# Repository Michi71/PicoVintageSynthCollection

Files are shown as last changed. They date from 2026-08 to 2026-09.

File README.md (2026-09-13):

# PicoVintageSynthCollection

Ten vintage synthesizer emulations for the RP2350, built from one shared
codebase. Same board, same core, one firmware image per instrument.

<p align="center">
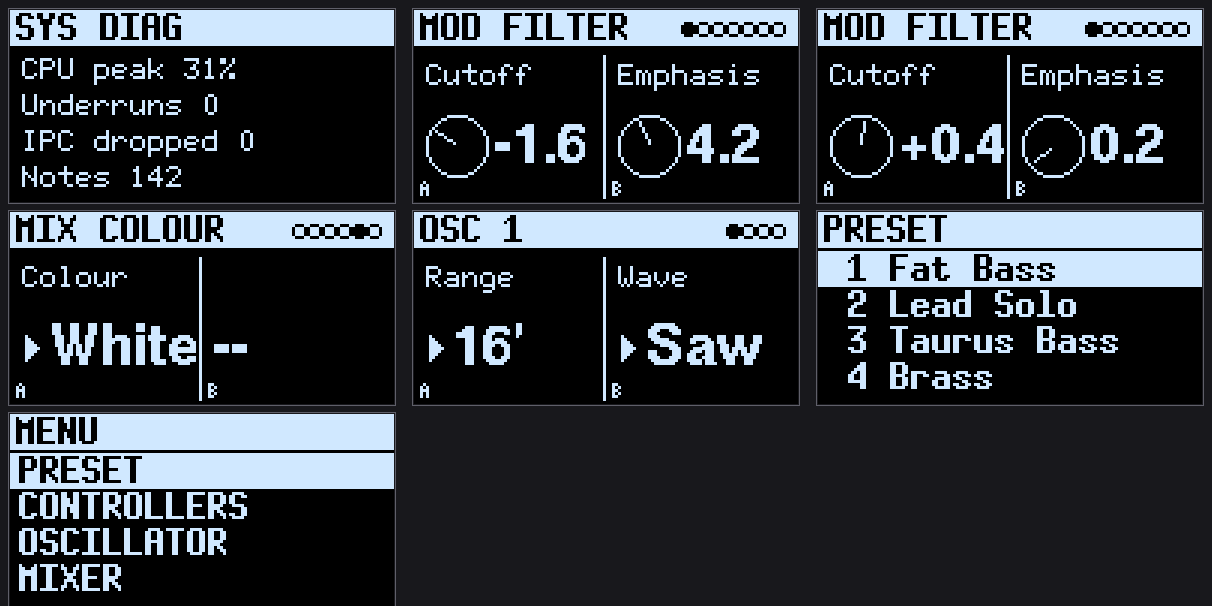
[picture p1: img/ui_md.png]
PicoFaceMD front panel: diagnostics page, filter page, preset list, section menu
  
  <br>
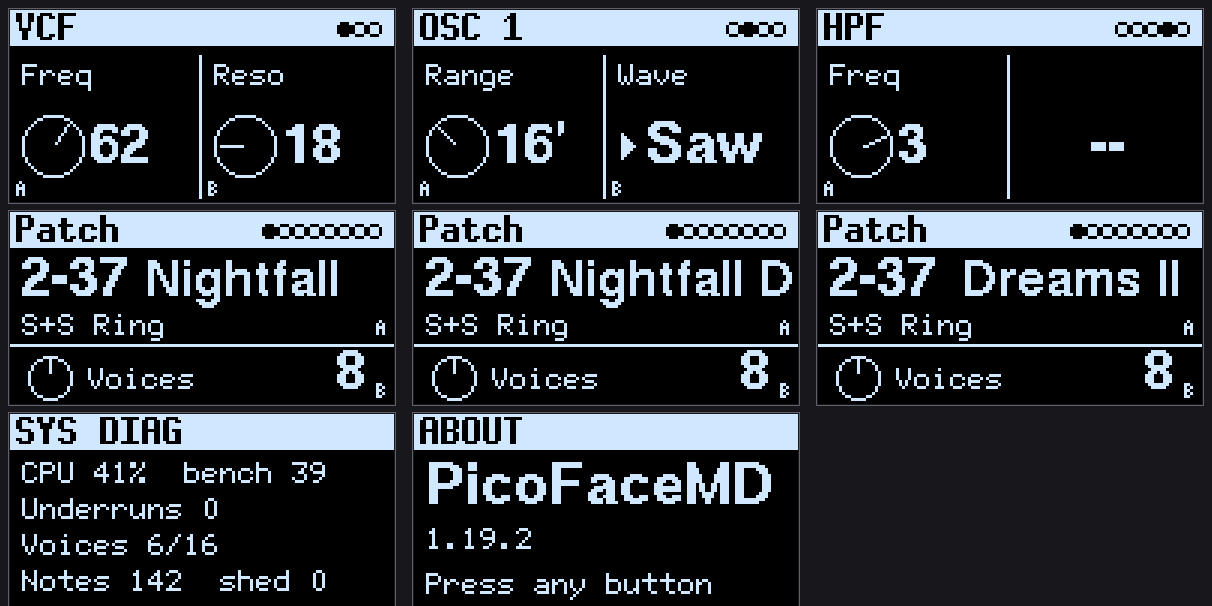
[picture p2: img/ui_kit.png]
The shared front panel: about, diagnostics, two-value pages, menus, patch page, popup
  
  <br>
  <sub>Rendered on a host from the firmware's own drawing code
  (<a href="tools/host_tests/ui/README.md">tools/host_tests/ui</a>) &mdash; what the OLED shows, pixel for pixel.</sub>
</p>

## Demo

<p align="center">
  <a href="https://youtu.be/cG6gyhaqCxE">
    PicoVintageSynthCollection demo video
  </a>
  <br>
  <a href="https://youtu.be/cG6gyhaqCxE">&#9654; Demo video on YouTube</a>
</p>

## Instruments

| Folder | Instrument | Binary |
|---|---|---|
| [instruments/PicoFaceYC](instruments/PicoFaceYC/README.md) | Yamaha reface YC (drawbar organ) | PicoFaceYC.uf2 |
| [instruments/PicoFaceCP](instruments/PicoFaceCP/README.md) | Yamaha reface CP (electric piano, mdaEPiano) | PicoFaceCP.uf2 |
| [instruments/PicoFaceDX](instruments/PicoFaceDX/README.md) | Yamaha reface DX (4-operator FM) | PicoFaceDX.uf2 |
| [instruments/PicoFaceJ6](instruments/PicoFaceJ6/README.md) | Roland Juno-6 | PicoFaceJ6.uf2 |
| [instruments/PicoFaceMD](instruments/PicoFaceMD/README.md) | Minimoog Model D | PicoFaceMD.uf2 |
| [instruments/PicoFaceSM](instruments/PicoFaceSM/README.md) | ARP/Eminent Solina String Ensemble | PicoFaceSM.uf2 |
| [instruments/PicoFaceOB](instruments/PicoFaceOB/README.md) | Oberheim OB-X (engine ported from OB-Xf) | PicoFaceOB.uf2 |
| [instruments/PicoFaceRD](instruments/PicoFaceRD/README.md) | Roland RD / MKS-20 (sample piano) | local build only |
| [instruments/PicoFaceJV](instruments/PicoFaceJV/README.md) | Roland JV-880 (native engine over the original PCM data) | local build only |
| [instruments/PicoFaceD5](instruments/PicoFaceD5/README.md) | Roland D-50 (native LA engine over the original PCM data) | local build only |

The RD, the JV-880 and the D-50 are the exceptions to "download and flash":
they only build where the respective ROM set is present, and those ROMs are not
distributable, so none of the three is in the release binaries. Without them
the configure step skips them and the seven above are unaffected. All three run
on the hardware; see the flash note below for the one build option the JV-880
needs on a small board.

## Hardware

- RP2350; the reference board carries 16 MB of flash, 4 MB is enough for every
  instrument but the JV-880 (see [How much flash an instrument needs](#how-much-flash-an-instrument-needs)).
  **The board must feed the core from the RP2350's own regulator** -- see
  *The board has to take the overclock* below before buying anything cheap.
- I2S audio (PCM5102 DAC)
- 128x64 OLED over I2C (SH1106)
- Three rotary encoders with push buttons
- USB MIDI and DIN MIDI

The pin map is the same for every instrument and lives in
[core/include/project_config.h](core/include/project_config.h).

**Which RP2350 board.** The default build assumes a Pico-2-format board with an
RP2350**A** -- Pico 2, Waveshare RP2350-Plus and the like -- where I2S sits on
GP26/27/28 at header pins 31/32/34. The Waveshare **RP2350B-Plus-W** has the
same header but carries **GP40/41/42** at those three positions (the RP2350B's
ADC0-2 take the Pico's ADC spots; GP26-28 are only on the pads underneath), so
a default image on it drives the I2S lines into thin air: display, MIDI and
encoders work, only the sound is missing, and every counter reads healthy. It
is a build-time choice, not a wiring one -- see *Building* for
`-DPICOFACE_BOARD=rp2350b_plus_w`.

**The board has to take the overclock.** These engines are budgeted for a
core clock of **444 MHz** (480 for the RD) at a core voltage of **1.60 V**:
three times the RP2350's rated 150 MHz, and a voltage above what the SDK
allows without an explicit override. That is not a tuning option, it is the
design point -- below it the instruments do not finish their audio blocks.
The firmware sets that voltage through the chip's on-board regulator, so the
board has to route the core supply (`DVDD`) through that regulator, the way
the Pico 2 reference design does. **Known good:** Raspberry Pi Pico 2,
Waveshare RP2350-Plus, Waveshare RP2350B-Plus-W (with its build variant).
**Known bad:** unbranded 16 MB "RP2350" boards from marketplace sellers. One
was bought to settle issue #107: its chip and flash are fine, but the
regulator register has no effect on its core voltage, so the core stays at the
board's fixed supply and stops dead at 312 MHz. No build option, flash timing
or stepping has anything to do with it, and no firmware can get 444 MHz from
such a board. The symptom is either nothing on the screen with the release
image, or "boots at 300 MHz, no sound" with a downclocked build. If a board
does neither of the things above, the working image is the diagnosis: build
`PicoFaceMD` with `-DPICOFACE_BOOT_DIAG=ON` and read the last line on the
screen; the whole investigation, with the images that separate flash, core
and voltage, is in the MD README under
[The board that stops at 300 MHz](instruments/PicoFaceMD/README.md#the-board-that-stops-at-300-mhz-a-core-voltage-the-register-cannot-reach).
Please check that section before opening an issue about a board that will
not start: a chip marked `A4` is not the reason either (the splash shows the
bootrom revision as `b4` now, and it changes nothing).

**If the screen stays dark.** The panel is on I2C at 1 MHz with only the chip's
internal pull-ups. That is above what an SH1106 datasheet promises (400 kHz) and
it is what the reference board runs, because the display push is paced in half
tile rows of roughly 1.5 ms of I2C each -- the bus rate is directly the UI's
frame time, and 400 kHz would make a full screen 60 ms instead of 24. On longer
jumper leads it is the first thing to suspect. Build with
`-DPICOFACE_OLED_I2C_HZ=400000`, and consider real 2.2k-4.7k pull-ups before
blaming the display.

A display that is simply absent costs nothing: the I2C write returns an error on
a NACK and the firmware carries on. A display that *holds a line low* used to
take the whole instrument down -- the wait for the bus is unbounded, and the
first transfer happens before the splash loop, which is the only place USB gets
serviced during startup, so the board would not even enumerate. It reads exactly
like a firmware that does not boot. That write is now bounded at 5 ms and the
panel is written off after twenty consecutive failures, so a broken display
costs you the display and not the MIDI, the audio and the encoders.

**On the board setting.** The build defaults to `PICO_BOARD=sparkfun_promicro_rp2350`,
and that is a statement about flash size rather than about hardware: the
prototype runs a Waveshare RP2350-Plus, and the SparkFun definition was picked
because it declares 16 MB where the plain `pico2` definition declares 4. Any
RP2350 board with 16 MB works if the pins above are reachable on it. For a
Pico-format board the honest pair is

```bash
cmake -S . -B build -G Ninja -DCMAKE_BUILD_TYPE=Release -DPICO_BOARD=pico2 -DPICO_FLASH_SIZE_BYTES=16777216
```

Without that second flag, `pico2` caps the image at 4 MB. The CP's sample
sets were cut for exactly that size, so every instrument but the JV fits
within it (the CP at 3.99 MB, with 190 KB to spare); the flag is for the JV,
and for a board that really has 16 MB. Nothing else in the SparkFun definition
reaches the firmware: the flash timing and the system clock are set by the project itself in
[core/src/pico_hw.cpp](core/src/pico_hw.cpp), and `PICO_FLASH_SPI_CLKDIV` is
identical in both. The one thing it declares that the prototype does not have is
an 8 MB PSRAM region on GPIO 19 — nothing is placed there, so it costs nothing,
but PSRAM is not a thing to reach for on this hardware without checking the
board first.

### Switching instruments

One board, ten firmware images, so choosing a different instrument is something
you do rather than something a factory does once. **Hold all three encoder
buttons together.** After half a second the display takes over and counts down
from two; let go and nothing happens. Hold it out and the board silences itself,
drains the audio it had already queued, and reappears as the `RPI-RP2` drive —
drop the next `.uf2` on it.

No button combination in any instrument uses all three at once, so it cannot
happen by accident, and the BOOTSEL button on the module is never needed for
this. Keep that button reachable anyway: if a firmware is too broken to reach
its own user interface, BOOTSEL plus a power cycle is the way back.

### How much flash an instrument needs

The reference board carries 16 MB. That is not a requirement of the design:
three instruments ship sample data, and only one of them needs a build option
to fit the 4 MB that a base Raspberry Pi Pico 2 and many other RP2350 boards
provide:

| Instrument | Image | On a 4 MB board |
|---|---|---|
| YC, DX, J6, MD, SM, OB | 90-190 KB | fits anywhere |
| PicoFaceCP | 3.99 MB | fits, 190 KB to spare |
| PicoFaceJV | 4.34 MB | only with `-DPICOFACEJV_4MB=ON` (3.76 MB, banks A+B) |
| PicoFaceD5 | 0.86 MB | fits |
| PicoFaceRD | 2.56 MB | fits |

The JV's reduced variant drops something real: the user bank, and the 22
samples only those patches used. Banks A and B are otherwise untouched --
nothing is resampled or requantised.

**The RD used to need one too, and no longer does.** Its packs held four
sampled velocity layers of every note; they hold the parameter ROM's own
corners now and the engine interpolates, which is both exact at all 128
velocities and a fifth the size. The whole instrument went from 5.15 MB to
2.56 MB. `-DPICOFACERD_MODEL=MKS20` or `=MK80` still builds one machine on its
own -- eight patches, and half a ROM set is enough for it -- but nobody needs
it to fit a board any more.

**The CP has no reduced variant either, and needs none.** It used to be
4.22 MB and carried its five built sample sets as one indivisible whole, with
no subset to drop; the sets were then cut for a 4 MB flash without dropping
anything: every sample keeps its attack byte for byte and loops 40-100 ms
earlier, at a loop cycle chosen to stay within 1 dB and 10 % spectral centroid
of the cycle it looped before. The rule and the numbers are in
[tools/cp_sampleprep](tools/cp_sampleprep/README.md#fitting-a-4-mb-flash).
Anything from 8 MB up holds any of the ten instruments. The D-50 is the one
sample-based instrument that never needed cutting -- its whole sample ROM is
512 KB.

An oversized `.uf2` fails to copy in a way that names no reason: the file
transfer stops or the drive rejects it, with nothing on screen about flash size.
That is the symptom, and it is not a corrupt download.

## Building

```bash
git clone --recurse-submodules https://github.com/Michi71/PicoVintageSynthCollection.git
cd PicoVintageSynthCollection
cmake -S . -B build -G Ninja -DCMAKE_BUILD_TYPE=Release
cmake --build build
```

The artifacts are then in `build/<instrument>.uf2`.

**Board variant.** `-DPICOFACE_BOARD=pico` (the default) builds for any
Pico-2-format RP2350A board. `-DPICOFACE_BOARD=rp2350b_plus_w` builds for the
Waveshare RP2350B-Plus-W: it selects an RP2350B board profile (48 GPIOs, 16 MB),
puts I2S on GP40/41/42, and re-bases PIO0 to GPIO 16-47 before the I2S program
is loaded, because an RP2350 PIO addresses either GPIO 0-31 or 16-47. The firmware
also puts such a board's flash into quad by itself when the bootrom left it in
dual -- the Puya P25Q128H on the reference board ships with its quad-enable bit
clear, and the bootrom never sets one -- and then tops the flash timing ladder
one rung lower (111 MHz instead of 148; RD 96 instead of 120): that part
verifies 111 MHz in quad and hangs at 148, and a rung that hangs cannot be
stepped down from. See the PicoFaceMD README, *The bit the bootrom never sets*. A board
with a faster flash can ask for the full rung with
`-DPICOFACE_QMI_M0_TIMING_TARGET=PICOFACE_QMI_M0_TIMING_RX4`. The released UF2s
are the default variant; the RP2350B build is one cmake flag away and produces
the same ten images.

```bash
cmake -S . -B build-b -G Ninja -DCMAKE_BUILD_TYPE=Release -DPICOFACE_BOARD=rp2350b_plus_w
cmake --build build-b
```

**The splash screen names the build.** Every instrument shows a version taken
from `git describe`, not a number typed into its `instrument.cmake`: on a
release tag it is the release (`1.7.0`), anywhere else it says how far past that
tag and from which commit (`1.7.0-4-ga39504b`), and a trailing `+` means the
tree had uncommitted changes when it was built. The About page shows the same
string. Quote it in a bug report and the image is identified exactly; the
version used to read `0.1` in every build ever made, which identified nothing.

A tarball without `.git` builds fine and shows `unknown`.

### The three that need ROMs

`PicoFaceRD`, `PicoFaceJV` and `PicoFaceD5` play the original machines' own
data, which is not distributable. Each looks in its own `roms/` directory —
`instruments/<name>/roms/`, gitignored — and removes itself from the build with
a note if what it needs is not there. Nothing else is affected.

| | what goes in `roms/` | |
|---|---|---|
| **PicoFaceD5** | two PCM ROMs and a program EPROM | identified by CRC32, so **names do not matter** |
| | | plus optional `*.syx` bulk dumps for the patch banks |
| **PicoFaceJV** | `jv880_rom2.bin`, `jv880_waverom1.bin`, `jv880_waverom2.bin` | exact names, 256 KB + 2 MB + 2 MB |
| **PicoFaceRD** | `mks20_15179736.BIN` … `41.BIN`, `MK80_IC5.bin`, `MK80_IC6.bin`, `MK80_IC7.bin` | exact names, 128 KB each |
| | `pack_p0.rdp` … `pack_p15.rdp` | **built, not found** — see below |

**The RD needs one thing nobody else does.** Its sixteen `.rdp` packs are note
descriptors derived from those ROMs, and they have to be made once:

```bash
R=instruments/PicoFaceRD/roms
python3 tools/rd_extract/rd_descramble.py $R \
    RD200_B.bin mks20_15179757.BIN /tmp/prog.bin /tmp/prm.bin
python3 tools/rd_extract/rd_make_packs.py /tmp/prog.bin /tmp/prm.bin $R \
    0 0x000000 1 0x008000 …
```

Python and the ROMs, nothing else -- no emulator, no toolchain beyond the one
already building the firmware.

**To check that all of this actually works from scratch**, `tools/check_clean_build.sh`
clones into a temporary directory, copies the ROMs in from outside git, and
builds all ten. That last part is the point: the ROM sets are not in this
repository and must never be, so a build here is the one thing CI cannot cover.
Name a directory to build there instead and keep the result; add `--variants`
for the reduced images too.

RD also builds as a single machine — `-DPICOFACERD_MODEL=MKS20` (1.73 MB) or
`=MK80` (1.23 MB), eight patches each, and only that machine's ROMs are needed.
The default is both machines and 2.56 MB, which fits a 4 MB board. See
[`instruments/PicoFaceRD/README.md`](instruments/PicoFaceRD/README.md) for the
whole recipe and all sixteen patch offsets.

Building a single instrument:

```bash
cmake -S . -B build -G Ninja -DCMAKE_BUILD_TYPE=Release -DPICOFACE_INSTRUMENTS_FILTER=PicoFaceMD
cmake --build build
```

### If the very first cmake call dies with an architecture error

On macOS a mixed package manager prefix produces this, and it reads like a
problem with the project:

```
dyld: Library not loaded: /opt/local/lib/libarchive.13.dylib
  Referenced from: /opt/local/bin/cmake
  Reason: (mach-o file, but is an incompatible architecture (have 'arm64', need 'x86_64'))
Abort trap: 6
```

It is not. The complaint comes from `dyld` about loading `cmake` itself, before
any of this repository is read, and "need 'x86_64'" means the `cmake` binary is
an Intel build sitting next to Apple Silicon libraries — a MacPorts or Homebrew
prefix that was installed under Rosetta, or carried over from an Intel Mac
without the migration. Check with:

```bash
uname -m                 # arm64 on Apple Silicon
file $(which cmake)      # must say the same
```

If they disagree, reinstall the toolchain for the machine's own architecture
(MacPorts documents a migration procedure for exactly this). Apple Silicon
itself is fine: the collection is developed on it.

## Repository layout

```text
core/            shared runtime: audio pipeline, hardware, USB/DIN MIDI, GUI, persistence
cmake/           picoface_add_instrument() and the SDK import helpers
lib/             third-party static libraries (audio, encoder, u8g2) and the SDK submodules
instruments/     one folder per instrument: instrument.cmake, src/, include/, doc/, README.md
tools/           host-side tools; not part of any firmware image
docs/            documentation shared by all instruments
hardware/        the module as a board: schematic, two layouts, panel, parts, and
                 what the first built pair taught
img/             the instruments' screens and the panel sheets above, rendered
                 from the firmware by tools/host_tests/ui
```

## Documentation

Shared:

- [Architecture](docs/ARCHITECTURE.md) - how core and instruments fit together, and why
- [Adding an instrument](docs/ADDING_AN_INSTRUMENT.md) - the three steps needed
- [The module bus](docs/MODULE_BUS.md) - the hardware interface several modules in one
  case would share: power, MIDI and audio. Planned, not built
- [Hardware](hardware/README.md) - the module as a 10 HP Eurorack board: schematic,
  the two layouts and the panel, parts, and the first built pair
- [Host tools](tools/README.md)

Per instrument, under `instruments/<name>/doc/`: MIDI implementation charts,
persistence formats, preset tables and the engineering logs of the individual
ports. The per-instrument README links them.

Manufacturer manuals and service documentation are **not** part of this
repository. Where an emulation follows a specific manual or schematic, the
instrument's README names the document so it can be obtained separately.

## Status

**All ten instruments build from a single configure run, each with its own USB
PID, and all ten run on the hardware.** Seven are in the release binaries; the
RD, the JV-880 and the D-50 need a local ROM set and are therefore built locally
only.
Open points are listed in [docs/ARCHITECTURE.md](docs/ARCHITECTURE.md),
section 8.

## License

**GNU General Public License, version 3 or later** - see [LICENSE](LICENSE).
Copyright (C) 2026 Michi71.

The collection was assembled in August 2026 from seven single-instrument
repositories -- YC, CP, DX, RD, J6, MD and SM; OB, JV and D5 were written here
afterwards, which is why the number is seven and not ten. Each of those seven
already shipped the identical GPL-3 licence text, and every instrument README
states GPL-3. It is also the lowest common denominator of what the engines are
built on. Where an instrument derives from someone else's work:

| Part | Upstream it derives from | That upstream's license |
|---|---|---|
| core, cmake, tools | own work | - |
| PicoFaceYC | [OpenB3 / BeatrixCPP](https://github.com/pantherb/setBfree) - tone generation *concepts* only, no code | AGPL-3.0 upstream, does not reach here; see below |
| PicoFaceCP | [mda-EPiano](https://sourceforge.net/projects/mda-vst/) (engine, in tree) | GPL-3.0-or-later |
| PicoFaceDX | an ESP32 reface DX emulation (engine) | see that project |
| PicoFaceRD | [giulioz/rdpiano](https://github.com/giulioz/rdpiano) + MAME (reference emulator; host-side only, not in this repository) | GPL |
| PicoFaceJ6 | [junox](https://github.com/dzannotti/junox) (patch table, parameter scaling) | GPL-3 |
| PicoFaceMD | [BelaMiniMoogEmulation](https://github.com/lbros96/BelaMiniMoogEmulation) (ladder filter) | stated by its author to be under no copyright |
| PicoFaceSM | [string-machine](https://github.com/jpcima/string-machine) (DSP models) | Boost Software License 1.0 |
| PicoFaceOB | [OB-Xf](https://github.com/surge-synthesizer/OB-Xf) (engine) | GPL-3.0-or-later |
| PicoFaceJV | own engine over the machine's own PCM data, measured against [giulioz/jv880_juce](https://github.com/giulioz/jv880_juce) (host-side reference; tone field layout) | non-commercial; not vendored, see below |
| PicoFaceD5 | [munt](https://github.com/munt/munt) - the LA32's wave generation and the Boss reverb topology as that project *documents* them, no code | LGPL-2.1-or-later upstream, does not reach here; see below |

Two rows in that table need a sentence more than a table cell holds.

**PicoFaceRD** used to carry the reference emulator's sources in the tree, and
three decoded ROM sets with them. Neither is here any more. The emulator is a
separate checkout the regression harness is pointed at, and the sample data is
built at configure time from a local ROM set into a blob -- the same arrangement
as the JV and the D5, and for the same reason. What the device plays is
`RdNewEngine` over descriptors that emulator captured offline.

**PicoFaceJV** contains none of that emulator's code, and cannot: its licence
forbids commercial use and fits neither MIT nor GPL-3. It was used as a host-side
measuring instrument — the harness in `tools/jv_extract/` drives it to take the
readings the engine was calibrated against, and the patch and tone field layout
comes from its `dataStructures.h`. The engine itself is written from the ROM
formats. `tools/jv_extract/README.md` records the reasoning; the work is Giulio
Zausa's, and his emulator in turn derives from [NukeYKT's
Nuked-SC55](https://github.com/nukeykt/Nuked-SC55).

`instruments/PicoFaceOB/` additionally carries its own `LICENSE`, identical in
text, because that instrument's engine is a direct port of OB-Xf and its files
keep the upstream copyright headers. Every instrument builds into its own
binary, so a stricter licence on one of them stays confined to that binary.

Source files carry a two-line SPDX header rather than the full notice, to keep
it out of the way of the code. Three kinds exist:

- own work: `GPL-3.0-or-later` plus the copyright line;
- ported trees (`instruments/PicoFaceDX/include/dx_engine/`): the licence line
  plus a note that copyright is shared with the upstream authors - no sole
  claim is made there;
- upstream files (`instruments/PicoFaceOB/include/obxf/`, CP's `mdaEPiano.*`,
  the SDK-derived `usb_descriptors.c`,
  `get_serial.*` and `tusb_config.h`): untouched, they keep the header they
  came with. The last four are MIT and BSD-3-Clause, not GPL.

**On PicoFaceD5 and munt.** The D-50 and the MT-32 share the LA32 sound chip,
and the MT-32 emulator [munt](https://github.com/munt/munt) has read that chip
out and written down what it does: how a cutoff becomes the width of a cosine
edge, how the resonance decays, and - from the same era's Boss reverb chip,
whose data lines were traced by Lord_Nightmare, balrog and Mok - the topology
the reverb here follows. munt is LGPL-2.1-or-later. Nothing was copied: the
engine under `instruments/PicoFaceD5/include/d5_engine/` was written for this
project from that written description and from the D-50's own firmware, which
is why no file there carries an upstream copyright header. The description is
what mattered, and a description is not the program.

**On PicoFaceYC and the AGPL.** OpenB3 / BeatrixCPP, whose tone generation
concepts the YC drawbar engine follows, is AGPL-3.0 - stricter than GPL-3, and
not something that can be dropped by relicensing. It does not apply here: the
engine under `instruments/PicoFaceYC/include/yc_engine/` was written for this
project and contains no upstream code, which is why no file there carries an
upstream copyright header. Copyright covers the expression, not the concepts,
so GPL-3 is the right licence for it.

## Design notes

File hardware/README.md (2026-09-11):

# Hardware

The module this firmware has been running on, turned into something
reproducible: the dimensions and decisions the board was drawn to, worked out
against the parts actually in hand and written down before the layout rather
than after. The first pair of boards has been fabricated, assembled and is
running the firmware since September 2026 - it is the reference hardware now,
see [The first built pair](#the-first-built-pair) for what powering it up
taught.

The schematic is drawn: the KiCad 10 project in
[PicoVintageSynthCollection/](PicoVintageSynthCollection/) (root sheet plus
`main_board`, `front_board`, `panel`; ERC clean), with a PDF export next to it
([PicoFace-schematic.pdf](PicoVintageSynthCollection/PicoFace-schematic.pdf)).

**Both boards are laid out**: [MainBoard/](MainBoard/) and
[FrontBoard/](FrontBoard/), routed, DRC clean; and the panel is a board in its
own right in [Panel/](Panel/). Both boards have been made from these files.

The interface *between* several modules — power, MIDI, audio — is a separate
document: [The module bus](../docs/MODULE_BUS.md).

## Format

3U Eurorack, 10 HP. The panel is 50.8 x 128.5 mm and 1.6 mm thick, which is
mechanical rather than cosmetic: the EC11 encoders have a 5 mm threaded bushing,
and 1.6 mm of panel leaves 3.4 mm for the nut. A 2 mm panel leaves 3.0 mm, which
works but has no margin.

**Cut it to 50.4 mm, not 50.8.** 10 HP is 10 x 5.08 mm, and that nominal figure
is the space the module occupies in the rack, not the width of the metal. A panel
made to it has no room for the tolerances of its own edge, of its neighbours, or
of the rails, and a full row will bind rather than sit flat. Roughly 0.4 mm under
is the usual allowance. The height is not affected: 128.5 mm is already the
Eurorack panel height, 3U less the clearance the rails need.

The layout is [Panel/panel_10hp.svg](Panel/panel_10hp.svg) (CorelDRAW source
next to it), measured against the real parts: the display on top, the SELECT
encoder between the RUN and BOOT buttons, PARAM A and B in a second row, the
four jacks along the bottom below the board. 14 HP was the plan as long as the
three encoders had to share one row; with SELECT in its own row and the jacks
off the board, 10 HP closes.

## The governing dimension

**The board sits 6.5 mm behind the panel.** That is the EC11's body height and
nothing else negotiates with it — every other panel-facing part has to reach the
same plane:

- the **display** module is 2.8 mm thick, so it rides on 3.5 mm standoffs
- the **jacks** could not reach it at all, which is why they are panel-mounted
  and wired (see below)

## Drill and cutout list

Origin top left, X right, Y down, panel 50.8 x 128.5 mm. Numbers read off
`panel_10hp.svg` (1 unit = 0.01 mm there); the SVG carries a 50 mm calibration
bar.

| Element | X | Y | Machining |
|---|---|---|---|
| Mounting M3 | 7.5 / 43.3 | 3.0 | 3.2 dia |
| Mounting M3 | 7.5 / 43.3 | 125.5 | 3.2 dia |
| Display window | 25.4 | 30.0 | 30 x 16 (X 10.4–40.4, Y 22–38) |
| Encoder SEL | 25.4 | 60.58 | 7.0 dia, 15 mm knob |
| RUN | 10.0 | 60.58 | 4.0 dia for the 6x6 tact switch actuator |
| BOOT | 40.8 | 60.58 | 4.0 dia for the 6x6 tact switch actuator |
| Encoder A | 12.9 | 85.61 | 7.0 dia, 15 mm knob |
| Encoder B | 37.9 | 85.61 | 7.0 dia, 15 mm knob |
| MIDI in | 8.15 | 109.6 | 8.2 dia (M8 thread), 10 mm body |
| MIDI out | 19.65 | 109.6 | 8.2 dia (M8 thread), 10 mm body |
| Out L | 31.15 | 109.6 | 8.2 dia (M8 thread), 10 mm body |
| Out R | 42.65 | 109.6 | 8.2 dia (M8 thread), 10 mm body |

No USB cutout: the 10 HP panel has no room for a USB lead, so USB stays at
the module's own socket.

The display module is **35.4 x 33.5 mm** with its four M2 holes **30.4 x 28.5**
apart, set 2.5 mm in from its top-left corner — all four numbers off the part
itself. Centred on the board it sits at X 7.7–43.1, Y 15.0–48.5, which puts the
holes at X 10.2 / 40.6 and Y 17.5 / 46.0. The two boards, 45 x 80 mm each, sit
at X 2.9–47.9, Y 14.0–94.0 behind it; the jack row is below the boards.

**The display's pin order is not the common one.** Measured on the part in hand:
**1 VDD, 2 GND, 3 SCK, 4 SDA**, numbered from the display side with pin 1 on the
left. The order most modules use — GND, VCC, SCL, SDA — would have put 3.3 V on
this module's ground pin and killed it on first power-up. The header is centred
on the module's top edge, which is where DS1 sits.

**The window is cut to the pixels, not to the glass.** On the 1.3 inch module the
active area starts 7.35 mm below the module's top edge and is 14.7 mm tall, so
its centre lands 14.7 mm below that edge — the glass around it is 19 mm tall and
sits differently. Cutting to the glass would leave an uneven border.

Clearances, so the numbers can be checked rather than trusted: the display
glass ends at Y 48.5 and the SELECT knob begins at 53.1; the 15 mm knob leaves
4.9 mm to each 6 mm button; the PARAM knobs (78.1–93.1) end 0.9 mm above the
board edge at Y 94 and stand 10 mm apart; the jack bodies (10 mm) sit 1.5 mm
apart at 11.5 mm pitch — fine for round nuts, an 11 mm hex nut is marginal.

## The panel as a board

The drawing is not a manufacturable file. `panel_10hp.svg` says where the holes
go and can be read by a person or a laser cutter; a board house needs the
outline on a copper-stackup layer and every opening as a closed contour. So the
panel is drawn a second time, as [Panel/Panel.kicad_pcb](Panel/Panel.kicad_pcb)
— a two-layer board 1.6 mm thick with **no copper on it at all**, which is the
usual way to have a fab cut a front panel: same process, same price bracket, and
the silkscreen comes with it instead of needing a separate print.

**The coordinates are the table above shifted 0.2 mm left.** The table is drawn
on the 50.8 mm nominal; cutting to 50.4 takes 0.2 mm off each edge, and
everything has to follow or the pattern sits off-centre. It stays symmetric
after the shift, which is the check: SELECT lands on 25.2, exactly half of 50.4,
and each pair still mirrors (mounting 7.3 / 43.1, buttons 9.8 / 40.6, PARAM 12.7
/ 37.7, jacks 7.95 / 42.45). The mounting holes end up ±17.9 mm from the panel
centre, which is where the rail thread expects them.

**What is drilled and what is routed** is decided by one number: 6.3 mm, the
largest drill most fabs keep.

| Opening | Layer | Why |
|---|---|---|
| outline 50.4 x 128.5 | `Edge.Cuts` | |
| display window 30 x 16 | `Edge.Cuts` | rectangular |
| 3 x encoder 7.0 dia | `Edge.Cuts` | over 6.3 |
| 4 x jack 8.2 dia | `Edge.Cuts` | over 6.3 |
| 4 x mounting 3.2 dia | NPTH | |
| 2 x button 4.0 dia | NPTH | |

Routed circles are cut with an end mill and come out a little rougher than a
drilled hole, which is of no consequence behind a nut. The display window's
inside corners will carry the mill's radius, about 1 mm — that is normal and the
module's bezel covers it.

**Every label sits above what it names**, including the jack row. That is not
symmetry for its own sake: a patch cable hangs down out of a Eurorack jack and
covers whatever is printed below it, so the first drawing — labels under the
jacks, in the space that looked free — would have been legible only on an
unpatched module. Checked rather than eyeballed: no silkscreen stroke falls
within 0.3 mm of any opening or the board edge, and none of it disappears under
a 15 mm knob or an 11 mm jack nut.

**The top side is the front.** Decided, and the board file is drawn to it: the
legend sits on `F.SilkS` unmirrored, so the side the fab prints as top is the
side that faces the player. Say it in the order anyway — a panel has no
components to make the intent obvious, and a fab that guesses has a fifty-fifty
chance of printing the legend on the inside. White on black is the usual choice.

DRC reports six warnings and nothing else: the six hole footprints are generated
in the board file rather than pulled from a library, so the library-parity check
has nothing to compare them against. Same class of warning the other two boards
carry, and it does not reach the Gerbers.

## Two boards

Both boards are **45 x 80 mm, two layers**.

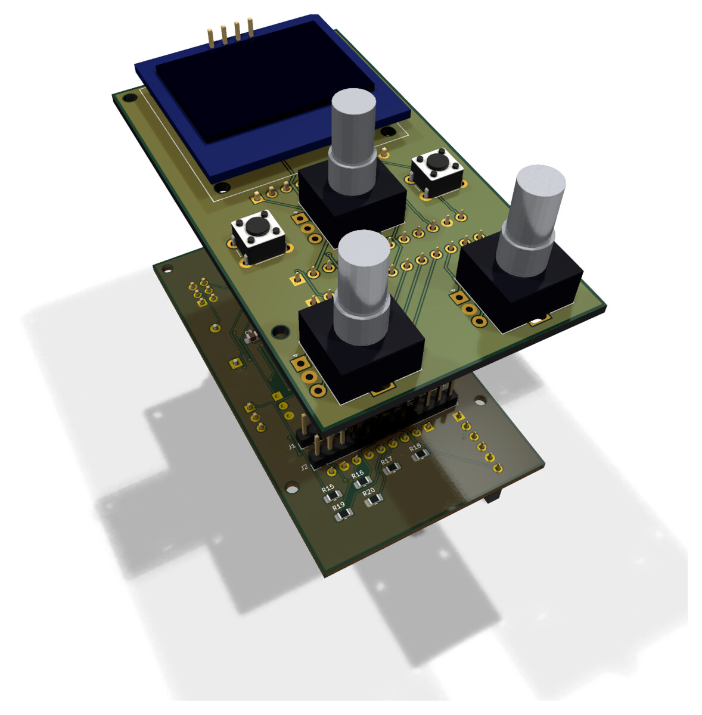
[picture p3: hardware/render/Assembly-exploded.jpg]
The two boards pulled apart, front board above the main board


*Renders under [render/](render/); how they are made and what they settled is in
[3D view](#3d-view) below. The encoders and the display are stand-in models, and
the module is drawn as a Pico.*

**Front board**, 6.5 mm behind the panel, carries everything the format dictates
— and that 6.5 mm is a hard ceiling for anything on its panel side, which is why
the jack wires are soldered into J8 rather than plugged into a header: a 2.54 mm
header stands 8.5 mm tall and would hit the panel. It carries:
three EC11 encoders, the RUN and BOOT tact switches (6x6, four pins; the
actuator has to reach through 6.5 mm of gap plus the 1.6 mm panel, so the 9.5
mm or taller types), the display on standoffs, the encoder pull-ups, and the
header J8 for the panel-wired jacks.

**Main board** behind it carries what does not care about the format: the
module on sockets, the PCM5102, the MIDI circuitry, and the bus connectors.

They join with **two 1x12 headers** (J1/J2 male on the main board, J3/J4
sockets on the front board) — two rather than one because they also hold the
boards parallel. Nineteen signals: I2C 2, encoders 9, MIDI 4, audio 2, RUN,
BOOT; plus 3V3, VSYS and three GND = 24. MIDI is four lines rather than two
because the current loop crosses the headers — the opto-coupler and its
resistors stay on the main board, where the bus MIDI RX joins the same node —
and the two extra grounds are what makes a single 24-way link acceptable for
audio. The plan said "roughly nineteen" and two 10-pin strips; the schematic is
where the count became exact.

The split is the point. A different enclosure means a new front board; the main
board does not change.

## Why the jacks are wired rather than soldered to the board

The available jack has its collar 2.9 mm above the board and its thread ends at
8.9 mm. With a 1.6 mm panel and a 2 mm nut, the panel can sit no further out
than 5.3 mm — and the encoders put it at 6.5 mm. Short by 1.2 mm, with no slack
anywhere to take it out of.

So the jacks mount to the panel and wire back to a 10-pin header (J8). That
removes the constraint instead of working around it: the board stops having an
opinion about which jack fits, which is what makes the three-conductor MIDI
sockets possible at all — those need TRS. The jacks are the M8-thread panel
type (10 mm body, nut, solder lugs), stereo for MIDI, mono or stereo for audio;
with a stereo jack on an audio output the ring is simply left open. On a metal
panel the bushing ties the sleeve to the panel — fine for the three grounded
jacks, and for MIDI IN either an insulating washer or accepting it (the opto
still isolates the loop).

## Parts

Already in hand: Waveshare RP2350-Plus (16 MB), three EC11 with 5 mm bushings, 15 mm
knobs, PCM5102 module.

Still needed:

| Part | Qty | Note |
|---|---|---|
| OLED 1.3" SH1106, I2C, 4-pin | 1 | 35.4 x 33.5 mm |
| 3.5 mm jack, panel mount, M8 thread, 10 mm, solder lugs | 4 | 2× stereo (MIDI), 2× mono or stereo (audio) |
| Tact switch 6x6, 4-pin, actuator ≥ 9.5 mm | 2 | RUN, BOOT — on the front board |
| Header strips 12-pin, male + female | 2 each | board to board (J1/J2, J3/J4) |
| Header strip 10-pin | 1 | panel jacks (J8) |
| Socket strips for the module | 2 | keep the module replaceable |
| Socket strips 1x6 and 1x9 | 1 each | the PCM5102 module, likewise replaceable |
| H11L1 optocoupler (+ DIP-6 socket) | 1 | MIDI in, Schmitt trigger type |
| 220R, 4k7, 1N4148, 100 nF | 1 each | MIDI in (4k7 pull-up on the H11L1, 100 nF bypass) |
| 33R, 0.5 W | 2 | MIDI out at 3.3 V (the source resistor sees a pin-4 short) |
| 1N5817 Schottky | 1 | bus 5 V into VSYS |
| BAT85 Schottky | 1 | bus MIDI RX into the RX node (small signal: low Vf, low leakage) |
| 1k 0805 | 2 | in series with the audio outputs (mispatch and load protection) |
| 100k 0805 | 4 | PCM5102 FLT/DEMP/XSMT/FMT to the module's own rails |
| 100 nF 0805 | 1 | on RUN, at the module pin |
| Shrouded header 2x3 | 1 | bus 1: power and MIDI |
| Header 3-pin | 2 | bus 2: audio; UART0 debug (footprint only) |
| 10k 0805 | 9 | encoder and switch pull-ups |
| 10 nF 0805 | 6 | **buy, leave unpopulated** |
| 100 nF 0805 | 1 | MIDI IN sleeve RF ground, **leave unpopulated** |
| M2 standoff 3.5 mm + screws | 4 | display |
| USB panel socket with lead | 0–1 | optional, and the 10 HP panel has no cutout for it; type follows the module — micro-USB on a Pico 2, USB-C on the Waveshare |

## Checked against the datasheets

- **The boards are drawn for a Raspberry Pi Pico 2**, the module most of the
  instruments in this collection run on. A **Waveshare RP2350-Plus** drops into
  the same sockets when 16 MB of flash is wanted — same 21 x 51 mm outline, same
  40 pins. Which one goes in is a firmware build setting, not a board question;
  see the flash-size note in the [top-level README](../README.md). The one place
  the difference does reach the board is BOOT, below.
- **Everything the board assumes about the module is checked against
  [the Pico 2 datasheet](https://datasheets.raspberrypi.com/pico/pico-2-datasheet.pdf)**,
  not against a footprint that happened to be to hand:

  | | board | datasheet |
  |---|---|---|
  | outline | 21.00 x 51.00 mm | 51 x 21 mm, 1 mm thick |
  | pin pitch | 2.54 mm | 2.54 mm |
  | pin 1 to pin 20 | 48.26 mm | 48.26 mm |
  | row spacing | 17.78 mm | 17.78 mm |
  | pin 1 from the top edge | 1.37 mm | (51 − 48.26)/2 |
  | hole per pin | 1.00 mm | 1 mm |

  Also from the drawing and not used here: four Ø2.1 mm mounting holes, 2 mm in
  from each end and 11.4 mm apart — the module hangs in its sockets, so they stay
  empty.
- **The pin map matches the firmware**, checked pad by pad against
  `core/include/project_config.h`: MIDI on GP4/GP5 → pins 6/7, display on GP2/GP3
  → pins 4/5, I2S on GP26/27/28 → pins 31/32/34, the three encoders on
  GP6-GP8/GP10-GP15, stdio on GP0/GP1 → pins 1/2.
  **This map assumes a Pico-format RP2350A board.** The Waveshare
  RP2350B-Plus-W keeps every one of these positions *except* pins 31/32/34,
  which carry GP40/41/42 there (the RP2350B's ADC0-2 take the Pico's ADC
  positions; GP26-28 are only on the pads underneath). A firmware built for a
  Pico drives GP26-28 into thin air on that board -- display, MIDI and
  encoders work, only the sound is missing. Build it with
  `-DPICOFACE_BOARD=rp2350b_plus_w` instead; see the top-level README. Ground lands on 3, 8, 13, 18,
  23, 28 and 38, and AGND on 33 — which the datasheet allows to be tied to
  digital ground when the ADC is not used, and it is not.
- **RUN is on pin 30** of the Pico format, so the RUN switch works.
- **VSYS is pin 39**, which is where the bus Schottky goes.
- **BOOT is a test pad on the underside**, under the BOOT button (the USB_N /
  USB_P pads sit under the USB connector, the three SWD pads at the far end).
  That pad sits on the button side of the 1 k that separates it from QSPI_SS_N,
  so the BOOT switch goes straight from the pad to ground — no extra resistor. A second button there makes the module
  unbrickable: a firmware too broken to reach its own interface is still
  recoverable without taking it apart.

  BOOT is the only signal on either board that does not end on a connector pin,
  which is why it gets two terminals rather than one:

  **TP2** is a spring-pin landing pad at **25.00 / 15.13**, directly under the
  module's BOOT pad, so the contact is made by seating the module and the module
  stays a plug-in part. That matters: the sockets are in the BOM specifically to
  keep it replaceable, and a soldered wire would tether it. The pin has to span
  **11.04 mm** — socket body 8.5 plus header plastic 2.54, both read out of their
  own STEP models — so roughly 12 mm free length compressing to 11. A crown or
  serrated tip, not a spear: the module's pad is flat and unperforated. It is
  **1.5 x 1.5 mm** though, which is a kinder target than it first looked, and
  leaves room for the tilt a 11 mm free-standing pin will have.

  **Where the position comes from.** Figure 5 of the Pico 2 datasheet, the SMT
  footprint, which gives every test-point centre in a frame whose origin is the
  board's bottom-left corner. The board is 21 x 51 mm there, and the USB shell
  pads at x 7.775 and 13.225 fix the centreline at 10.5. There are **seven** test
  points, not six, and the drawing labels none of them — it only gives
  coordinates, so which one is TP6 has to be reasoned out:

  | coordinate | mm from the USB end | what it must be |
  |---|---|---|
  | (9.5, 49.8), (11.5, 49.8), (10.5, 46.5) | 1.2 / 1.2 / 4.5 | TP1–TP3, the USB group, clustered at the connector |
  | (8, 43) | 8.0 | TP5, GPIO25/LED — the LED sits 7.4 mm from that end |
  | (8, 40.5) | 10.5 | TP4, GPIO23/SMPS PS |
  | **(8, 38)** | **13.0** | **TP6, BOOTSEL — the button sits 13.2 mm from that end** |
  | (11.5, 30.5) | 20.5 | TP7, 1V1, over by the chip |

  The LED and the BOOTSEL button are visible on any photo of the board, and
  measuring both against the three candidates leaves only one reading. The frame
  itself is confirmed independently: it puts pin 1's centre 1.37 mm from the top
  edge, which is exactly what KiCad's `RaspberryPi_Pico_Common_THT` footprint
  uses.

  Which side of the centreline a drawing means is the one thing it cannot say,
  since it does not state the viewing face — **checked on the part, the pad is
  nearer the GP0 row**, and that is the side the board carries. Against the
  module's own features TP6 sits **6.39 mm inwards from the GP0 pin row** and
  **11.63 mm from pin 1 along it**, which is the form to check with callipers.

  **The Waveshare RP2350-Plus is a different PCB**, so its BOOT pad is somewhere
  else and the spring pin will land on bare laminate. That build uses TP1 and a
  wire — which is exactly why TP1 stayed. Nothing needs changing on the board to
  switch between them; you fit either the pin or the wire.

  **TP1 stays** as the fallback, out at the board edge where a soldering iron
  reaches, for the case where the pad turns out to be somewhere else entirely.
  Then it is the short-wire build after all, and nothing has been lost.
- **RUN has only the RP2350's internal ~50k pull-up** (no external one on the
  module), and here it travels over two headers to the tact switch on the front
  board. 100 nF at the module pin (C9) so a touch or a spike does not reset a
  running instrument.
- **GP29 is not brought out**, which independently confirms that `PIN_POT_1` in
  `core/include/project_config.h` is a leftover rather than a connection.
- The pin map fits this board: MIDI on GP4/GP5 lands on **UART1**, which is what
  `midi_serial.cpp` uses, and the display on GP2/GP3 lands on **I2C1**, which is
  what `pico_hw.cpp` initialises.
- The **PCM5102 module takes 3.3–5 V** (two on-board LDOs) and brings its analog
  outputs out on a header row, so the audio bus taps there rather than at its
  own jack. The small purple GY-PCM5102 has a 6-pin digital row (SCK BCK DIN
  LCK GND VIN) and a 9-pin row on the long edge (FLT DEMP XSMT FMT A3V3 AGND
  ROUT AGND LROUT); the schematic sockets both, ties SCK to ground and leaves
  the four format pins to the module's own solder bridges (1=L 2=L 3=H 4=L for
  I2S) — plus 100k pulls to the module's own rails, so a replacement module
  that arrives unbridged still plays. Output is 2.1 Vrms behind 470R — about
  4.5 dB below the 10 Vpp a Eurorack module would normally put out, which is
  why no output stage is planned. The board adds 1k in series (R15/R16): a
  ±12 V Eurorack output patched into ours by mistake is then limited to
  ~8 mA into the DAC's clamps, and a half-inserted plug does not drop the load
  below the PCM5102's 1 kΩ minimum. Into a 100 kΩ input it costs nothing.
- **MIDI at 3.3 V.** In: 220R, reverse 1N4148, H11L1 from 3V3 with 4k7
  pull-up, sleeve left open (CA-033: no DC path to ground at the receiver; a
  100 nF footprint to ground is the RF option the spec allows). The pull-up is
  4k7 rather than the usual few hundred ohms because the bus MIDI RX joins the
  same node through a diode: every module then loads the hub's driver with
  only ~0.6 mA, ten of them with ~6 mA, and the low level at the module stays
  around 0.5 V. The firmware calls `gpio_disable_pulls(PIN_MIDI_RX)` — the
  pad's default pull-down would otherwise divide that pull-up. Out: 33R from
  3V3 to pin 4, 33R from TX to pin 5, sleeve grounded. CA-033's pair is
  33R/10R; 33/33 gives about 4.1 mA worst case into a standard receiver, the
  same class as the 47/47 the Teensy design ships with. The firmware raises
  GP4's drive strength to 12 mA — the default 4 mA is below the loop current.
  Both settings are made in `MIDISerial::init()`; neither is visible from the
  schematic, which is why they are written down on both sides.

## The main board layout

| front | back |
|---|---|
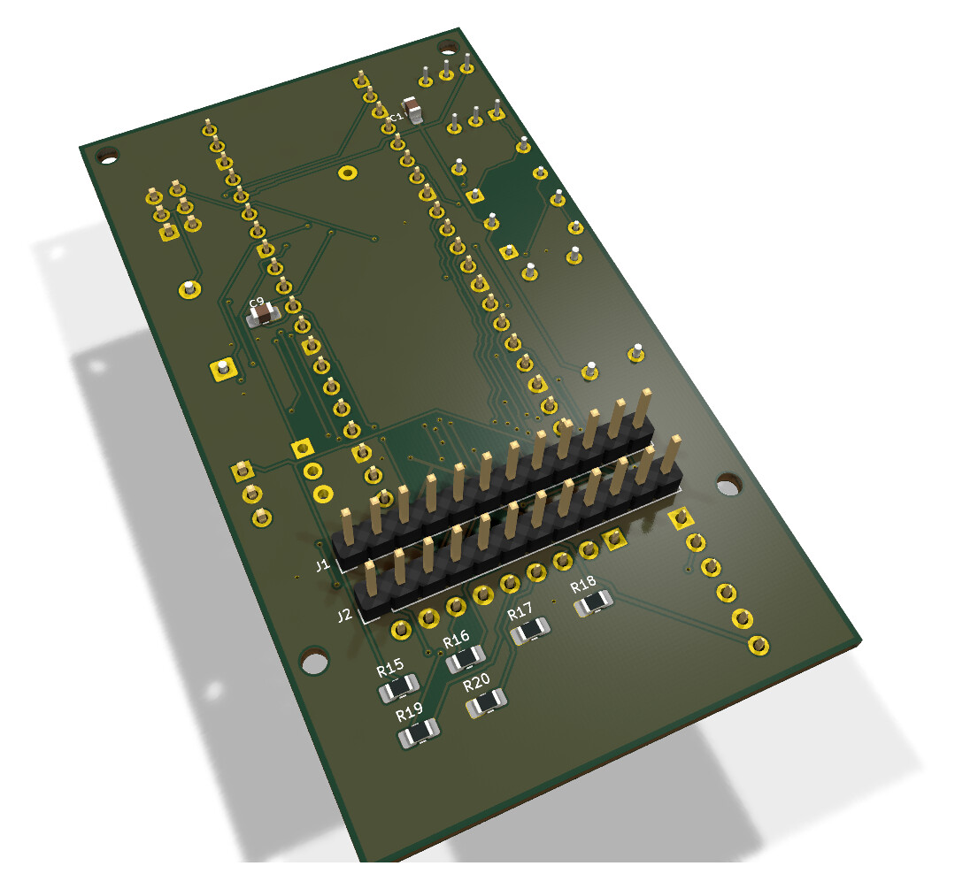
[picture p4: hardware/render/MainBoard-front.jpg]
Main board, panel side: J1 / J2 and the eight 0805 parts
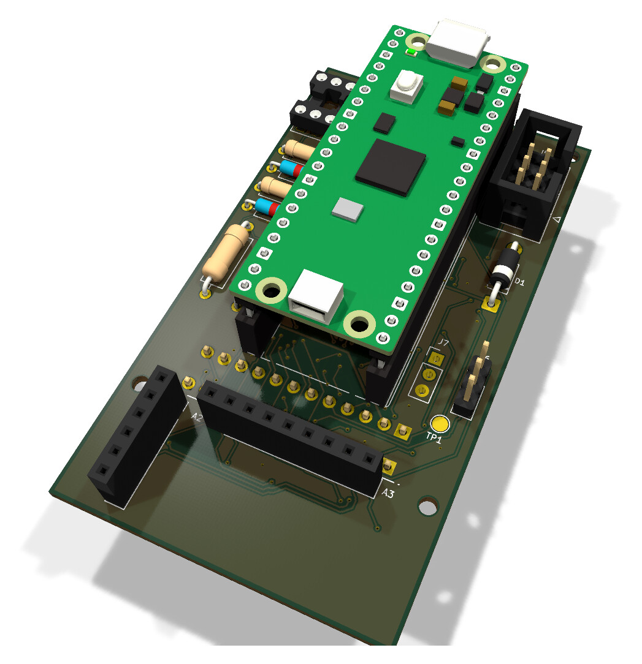
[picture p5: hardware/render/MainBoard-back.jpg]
Main board, back: module on sockets, MIDI section, PCM5102 sockets
|  |  |

[MainBoard/](MainBoard/) is a second KiCad project, because KiCad wants one
board per project. Its root sheet is a wrapper that pulls in
`../PicoVintageSynthCollection/main_board.kicad_sch` — there is one copy of the
schematic, not two. Every symbol carries a second instance path, which is what
lets one sheet belong to two projects without re-annotating anything. The 19
board-to-board signals end on global labels there, because they leave the board
through J1 / J2.

45 x 80 mm, two layers, 0.2 mm signal tracks (0.3 mm for 3V3 / VSYS / bus 5V),
0.2 mm clearance, 0.6/0.3 mm vias. 630 track segments, 1414 mm of copper, 93
vias — of which about a third are ground stitching. Ground is a pour on both
sides rather than routed.

**Everything sits on the back except J1 / J2 and the eight 0805 parts.** That is
the decision the layout turned on: with the module on the front it would
stand 13.5 mm into the gap between the boards and J1 / J2 would need long-pin
headers, which are a part you have to go looking for. On the back, nothing
between the boards is taller than a 0805, and ordinary headers reach. It also
puts USB, the bus connectors and the module's own BOOT/RESET buttons on the side
you can reach with the module in a case.

- **A1** sits at the top with its USB socket at the board's top edge, so a plug
  can come in from above without dismantling anything. A Pico 2 has **micro-USB**
  (the Waveshare board has USB-C), overhanging its own top edge by 1.3 mm typ.
  The module's edge is 2.13 mm inside the carrier board's, so the socket face
  ends up 0.83 mm *behind* the board edge — which sounds like it would foul a
  plug and does not, because the module stands 11 mm off the back on its sockets
  and the plug arrives in free air well above the board plane. Worth writing down
  so nobody 'fixes' it later.
- **TP2, the BOOT spring-pin pad, cost two reroutes.** It lands where UART0_RX
  used to run, so that net was laid again; the first attempt then took the
  corridor past C9 and pinched the ground pour into an 8.4 mm² island — with
  C9's own ground pad inside it, which would have left the RUN capacitor with no
  return path. The island was too narrow for a stitching via (widest point
  0.468 mm, a 0.6 mm via needs 0.50), so the fix is upstream: that corridor is a
  router keep-out now and UART0_RX goes round. Worth knowing because the same
  trap is waiting for the next track laid through there. BOOT ends up 72.2 mm
  long over two vias, which is long for a node that sits 1k from the flash chip
  select — harmless, because it is only sampled at reset, but it is the reason
  to keep the wire short if the fallback build happens instead.
- **The PCM5102 module** is at the bottom, on the socket offsets taken from the
  STEP model and cross-checked against a KiCad footprint — see
  [PCM5102_module_geometry.md](PCM5102_module_geometry.md). Its own 3.5 mm jack
  (unused) hangs about 11 mm past the bottom edge, which is drawn on
  User.Comments as a reminder.
- **The MIDI section** is down the right-hand strip beside the module, next to
  GP4/GP5 where its signals land.
- **A1's courtyard was clipped** to its own outline plus 0.25 mm. The library
  footprint reserves room for a connector overhang that here points off the
  board. Running "Update Footprints from Library" would put it back and J5 would
  then report a courtyard overlap.

DRC is clean: no unconnected items, no clearance, short, hole or courtyard
errors, and the board matches the schematic. What remains are warnings —
footprints differing from their library copies (they are generated, and A1's
courtyard is deliberately clipped) and a handful of silkscreen overlaps on a
board this dense.

## The front board layout

| panel side | back |
|---|---|
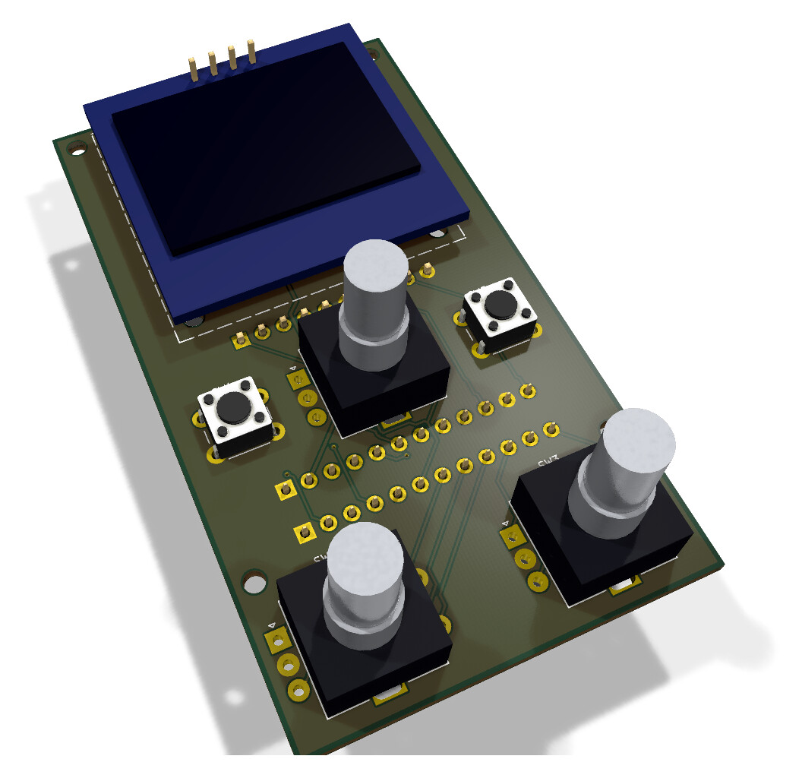
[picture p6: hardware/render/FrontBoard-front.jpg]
Front board, panel side: display, three encoders, RUN and BOOT
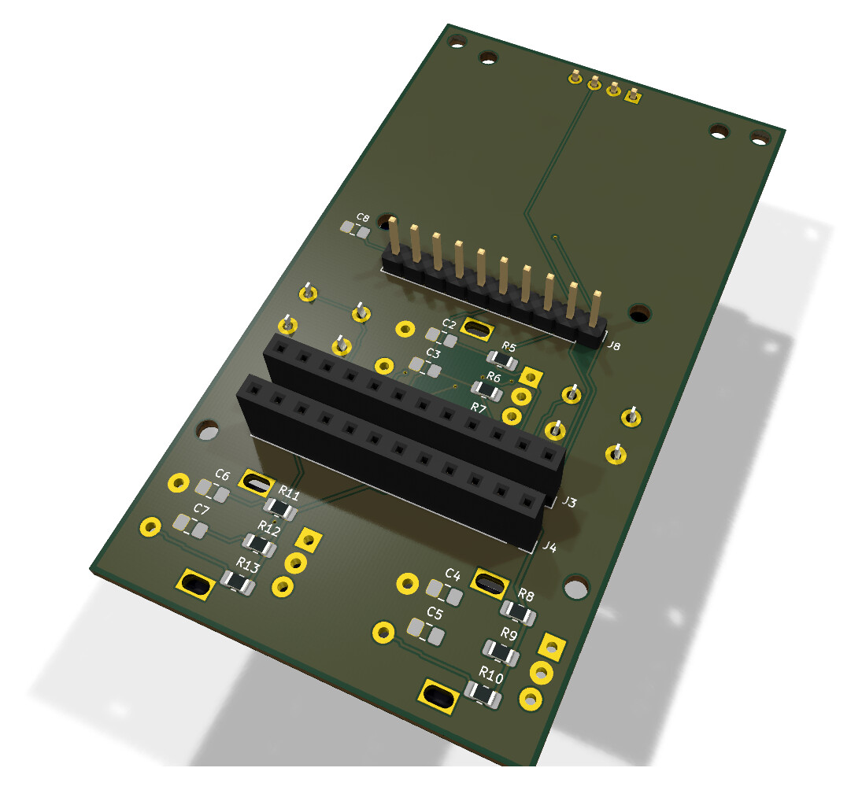
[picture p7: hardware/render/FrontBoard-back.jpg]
Front board, back: J3 / J4, J8 and the debounce parts
|  |  |

[FrontBoard/](FrontBoard/), same arrangement as the main board: a wrapper root
sheet around the shared `front_board.kicad_sch`, one copy of the schematic.
Power arrives through J3 rather than from anything on the board, so ERC rule
`power_pin_not_driven` is set to ignore in that project only.

45 x 80 mm, two layers, same rules as the main board. 229 track segments, 691 mm
of copper, 20 vias, ground poured both sides.

Almost nothing here was a free choice — the panel fixes it. Board origin is
panel (2.9, 14), so the encoder shafts land at (22.5, 46.58), (10.0, 71.61) and
(35.0, 71.61), the two buttons at (7.1, 46.58) and (37.9, 46.58), and the
display occupies (4.75, 1.0) to (40.25, 34.5). What was left to decide:

- **J3 / J4 sit on the back at exactly the coordinates J1 / J2 occupy on the
  main board** — y 55.4 and 60.4, pin 1 at x 8.89. Both boards are drawn in the
  same frame (both have F.Cu facing the panel), so a point (x, y) on one is
  directly behind the same point on the other, and pin k meets pin k.
- **J8 sits on the back**, in the free band between the display and the encoder
  row. Its wires run in the gap between the boards and leave at the bottom edge:
  on the panel side the encoder bodies fill the whole 6.5 mm, so there is no
  lane for ten wires there.
- **The pull-ups and debounce footprints sit beside the encoder they belong to**,
  on the back, where the encoders' own courtyards do not reach because those are
  on the other side.

## Fabrication output

Gerbers and drill files are not in the repository -- they are regenerated from
the board files, which is how the first pair was ordered. Two commands per
board, from `hardware/`:

```
kicad-cli pcb export gerbers --output MainBoard/fab/ \
  --layers "F.Cu,B.Cu,F.Mask,B.Mask,F.SilkS,B.SilkS,F.Paste,B.Paste,Edge.Cuts" \
  --subtract-soldermask --check-zones MainBoard/MainBoard.kicad_pcb

kicad-cli pcb export drill --output MainBoard/fab/ --format excellon \
  --excellon-units mm --drill-origin absolute --excellon-separate-th \
  --excellon-oval-format route \
  --generate-map --map-format gerberx2 MainBoard/MainBoard.kicad_pcb
```

That gives nine Gerbers, a plated and a non-plated Excellon file, drill maps and
a `.gbrjob` that declares two layers at 1.6 mm. Zip everything except the drill
maps -- a fab that auto-detects layers can mistake a `-drl_map.gbr` for copper.

Checked against the board files rather than assumed: main board 183 plated holes
(111 pads + 72 vias) and 4 unplated, front board 86 (67 + 19) and 8, both
outlines exactly 45 x 80 mm.

`--excellon-oval-format route` is deliberate. The encoders' six mounting lugs are
oval, and KiCad's default writes them as `X..Y..G85X..Y..` -- one line that means
"slot from here to there". It is normal Excellon and fabs read it, but strict
parsers do not all accept it: gerbonara refuses the file outright, so a check in
a viewer never happens. The routed form (`G00` to the start, `M15` pen down,
`G01` to the end, `M16` up) says the same thing in statements every tool knows.
The six slots come out as a 1.5 mm tool travelling 1.3 mm, so 2.8 x 1.5 mm, on
the three encoder axes at x 10.0 / 22.5 / 35.0. They are plated, which is what
holds the encoder bodies down.

The panel takes the same two commands with fewer layers — it has no paste and
no copper worth subtracting a mask from:

```
kicad-cli pcb export gerbers --output Panel/fab/ \
  --layers "F.Cu,B.Cu,F.Mask,B.Mask,F.SilkS,B.SilkS,Edge.Cuts" \
  Panel/Panel.kicad_pcb

kicad-cli pcb export drill --output Panel/fab/ --format excellon \
  --excellon-units mm --drill-origin absolute --excellon-separate-th \
  Panel/Panel.kicad_pcb
```

Read back: `Edge.Cuts` spans exactly 0–50.4 by 0–128.5 with eight closed
contours inside it, the unplated Excellon carries four 3.2 mm and two 4.0 mm
holes at the coordinates in the table, and the plated file and both copper
layers are empty — which is what a panel should look like.

Both packages were read back with gerbonara and rendered per side. What that
found and fixed: the Pico's `A1` designator sat entirely above the top edge and
would have been trimmed away by the fab, `TP1` and `A2` sat on pads and would
have been cut open by the soldermask subtraction, and the display outline ran
0.12 mm alongside the `DS1` box. Reference designators for the axial parts now
sit centred on their own bodies, which is also the only unambiguous place in a
4 mm-pitch stack. Both boards are at zero DRC violations, zero unconnected and
zero schematic-parity issues; nothing on any layer reaches past the outline.

The Excellon files carry a `G90` after the header that KiCad has always written
and that a strict reader warns about. It is not a defect and needs no action.

The main board carries **one DRC exclusion**, written into `MainBoard.kicad_pro`
with its reason: TP2's hole sits inside A1's courtyard, which is the entire point
of it. It is an exclusion for that one pair rather than the rule turned off, so
`pth_inside_courtyard` still guards the rest of the board — it caught a real
problem once already, when J1's pads sat under the module. TP2 has no courtyard
of its own, because a landing pad is not a component body.

## 3D view

The board files carried **no `(model ...)` references at all** — the footprints
were placed by script and the model lines never came along, so both boards
opened to an empty 3D view. Every footprint now points at its library model
again, with two exceptions and one correction:

- **The encoders had to be modelled.** KiCad ships 3D models for 105 of its 155
  footprint libraries and `Rotary_Encoder` is not one of them. These three parts
  are what fills the 6.5 mm between the front board and the panel, so a 3D view
  without them answers nothing.
  [3dmodels/RotaryEncoder_Alps_EC11E_H20mm.wrl](3dmodels/RotaryEncoder_Alps_EC11E_H20mm.wrl)
  takes its outline and shaft axis from the KiCad footprint and its heights from
  the EC11E nominal dimensions. Measured back out of a render: body 6.2 mm,
  bushing 4.8, 19.4 mm total above the board.
- **The display is an envelope**, not a model —
  [3dmodels/Display_I2C_35x33_Envelope.wrl](3dmodels/Display_I2C_35x33_Envelope.wrl),
  35.4 x 33.5 x 2.8 mm on its 3.5 mm standoffs, hung off H1. It exists to occupy
  the right space, nothing more.
- **The spring pin has a stand-in too** —
  [3dmodels/SpringPin_11mm_Stand-in.wrl](3dmodels/SpringPin_11mm_Stand-in.wrl).
  No part number behind it; it draws the envelope the contact has to fill, and
  the render below is what it is for: the pin has to out-reach the socket strips
  beside it, and you can see that it does.

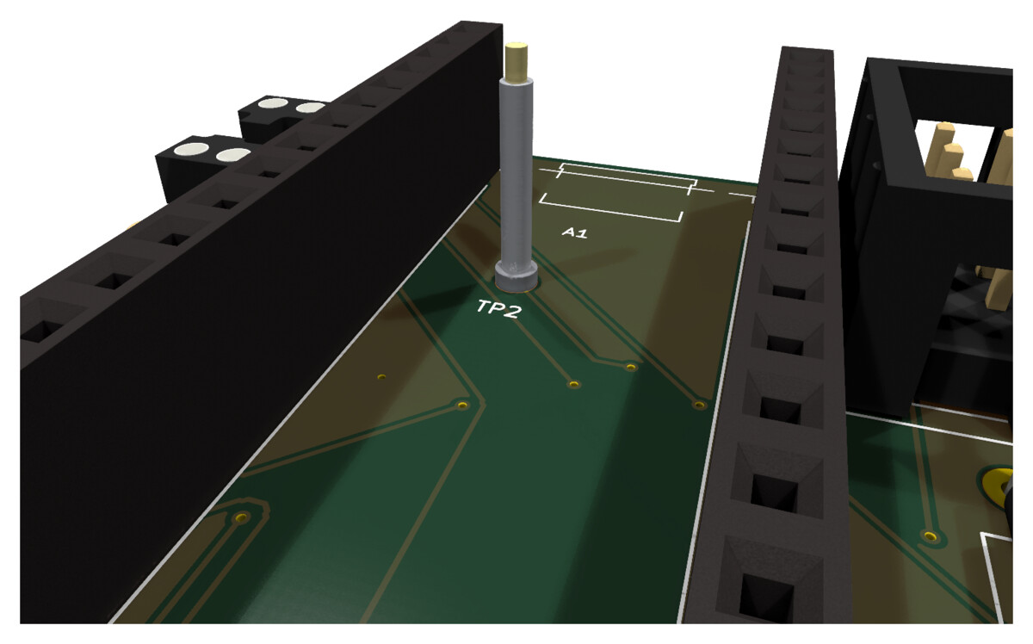
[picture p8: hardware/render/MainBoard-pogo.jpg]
The BOOT spring pin at TP2, module hidden
  

- **A1 now shows the module on its sockets**, not lying on the board. The
  footprint offers five variants and the one that was visible had headers
  soldered flat — which hides the very dimension the whole layout turns on. The
  socketed pair is visible and the module sits 11 mm up. The library has no
  Pico 2 model, but the outline is the same one.

Per board:

```
kicad-cli pcb render --output MainBoard-back.png --side bottom \
  --quality high --floor --perspective --rotate '-32,0,24' --zoom 0.85 \
  MainBoard/MainBoard.kicad_pcb
```

The two boards stacked is not something kicad-cli does, but it renders 3D models
and a board can be exported as one. Export the front board to VRML in tenths of
an inch (the unit KiCad's model loader expects), then add a footprint to a
throwaway copy of the main board that carries it as a model:

```
kicad-cli pcb export vrml --output FrontBoard.wrl --units tenths \
  FrontBoard/FrontBoard.kicad_pcb
```

```
(footprint "Assembly:FrontBoardStack"
  (layer "F.Cu") (at 22.5 40)
  (model "FrontBoard.wrl" (offset (xyz 0 0 11.04)))
)
```

No rotation and no mirroring: both boards are drawn in the same frame with F.Cu
towards the panel, so the front board only has to move up. **11.04 mm** is the
mated height of the two connectors, read out of their own STEP models — header
plastic 2.54 plus socket body 8.5. Raise the offset to 40 mm for an exploded
view. The VRML export's origin is the board centre with z=0 at the bottom face,
which is why the footprint goes at (22.5, 40) and the offset is the plain gap.

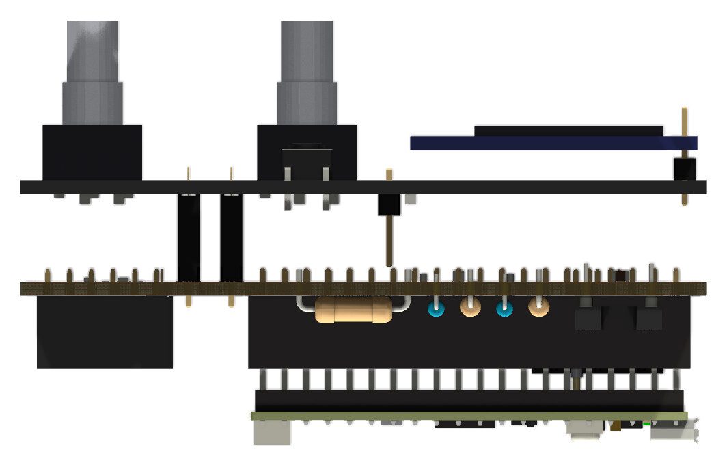
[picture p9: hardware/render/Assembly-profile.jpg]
The stack in profile: panel side at the top, module hanging off the back


The profile is the one worth reading twice. Top to bottom: encoder shafts and the
display on their standoffs, the front board, the two socket strips filling the
gap with J1 / J2 inside them, the main board, and the module hanging off its
sockets at the back. Also visible on the right is DS1's pin going straight
through the display.

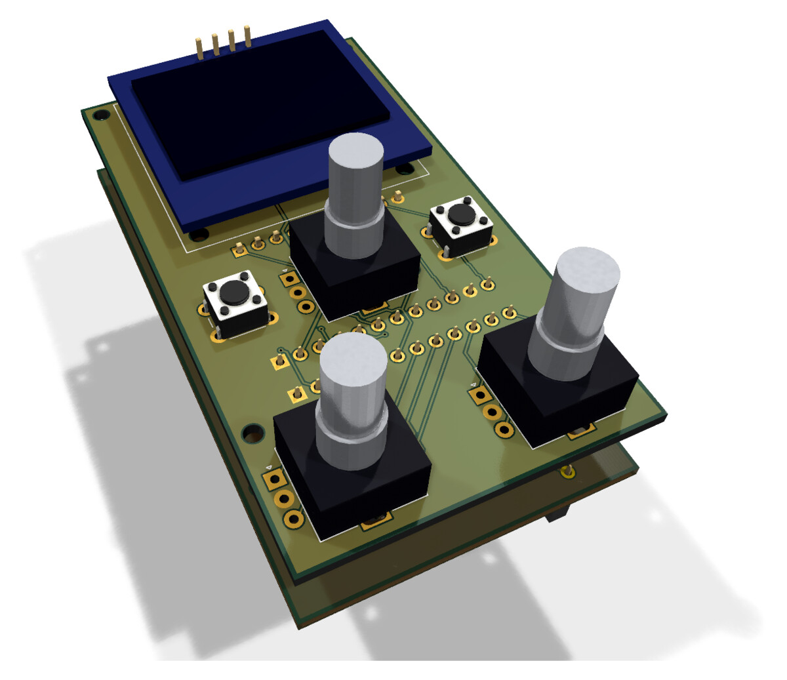
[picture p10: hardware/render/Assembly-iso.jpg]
The assembled pair from the panel side


The seven renders in [render/](render/) come out of exactly these commands,
scaled to 1200 px and saved as JPEG at quality 90 — they are photographic images
with smooth shading, where JPEG costs a third of the space and, checked at 200 %
zoom, leaves the silkscreen lettering clean. Regenerate them whenever a board
changes; they are documentation, not an artefact anything depends on.

What the view settled:

- **J1/J2 against J3/J4: all 24 pins coincide to 0.000 mm.** Worth checking
  rather than assuming — the two footprints are stored with opposite rotations
  (90 and -90) and only the back-side coordinate flip makes them run the same
  way.
- **DS1 and the display collide.** The display's carrier sits 3.5 mm up, a fitted
  2.54 mm header reaches 8.54 mm, and the render shows its pins straight through
  the module. That is not a board error — it says the display's own pins solder
  into DS1 from the front and no header gets fitted there. Worth knowing before
  ordering parts.
- **The tact switches in the render are the standard 5 mm type**, about 6.9 mm
  over the board, and the panel face is at 8.1 mm. That is the 9.5 mm-or-taller
  requirement noted above, now visible rather than only written down.

## Open

- Nothing on either board is assumed any more: every footprint position comes
  from a datasheet, a STEP model, the panel drawing or a measurement on the part.
- The board-to-board standoffs moved from the corners to y 63 on both boards:
  at y 77.5 the hole falls inside the PARAM encoders' courtyards. The front
  board is anchored to the panel by three encoder nuts anyway.
- ~~Not fabricated, not built.~~ Fabricated, built and running since
  September 2026; see the next section.
- Panel-mounted parts (the four jacks, the optional USB lead) are in the
  schematic with "exclude from board" set, so they appear in the BOM but on
  neither layout.
- Not on the schematic: mounting holes for board-to-board standoffs (the two
  header strips are the only mechanical link so far), and the module's SWD
  pads (underside, unreachable once the module sits in its sockets).
- Powered over USB at the module's own socket (the 10 HP panel has no USB
  cutout; a panel lead is optional). The bus 5 V path exists as footprints for
  later; where the hub's own supply comes from is not decided.
- The panel is the expensive part to have made — 128.5 mm exceeds the 100 x 100
  mm that sponsored and cheap-tier PCB runs are usually capped at. Both boards
  stay well under it.

## The first built pair

Both boards came back from fabrication in the first week of September 2026 and
were assembled and powered up on the 8th. Two findings, both resolved, both
worth knowing before building another:

- **The encoders count the other way round.** On this board the A and B
  contacts of all three EC11 reach the RP2350 swapped relative to what the
  firmware's pin definition had assumed - measured on the assembled board, not
  read off the schematic. The fix is in the firmware, deliberately in the pin
  definition rather than in a direction flag: `core/include/project_config.h`
  names `PIN_*_CLK` / `PIN_*_DT` the way this board wires them (SEL 7/6,
  PARAM A 11/10, PARAM B 13/12). This board is the reference from here on, so
  that is the one default; an earlier prototype or protoboard that was wired
  the other way swaps its two A/B leads (issue #161). There is no build
  variant for it, and there will not be one.
- **The DAC module is silent until R15-R20 are fitted.** The GY-PCM5102's four
  configuration pins are driven by the board (R17-R20, 100k; R19 pulls XSMT to
  A3V3, R17/R18/R20 pull FLT/DEMP/FMT to GND), and the module's own solder
  bridges stay open - that is the intended case, not a fault. Without R19,
  XSMT floats and the DAC sits in soft mute, which looks exactly like a dead
  module, on the module's own 3.5 mm jack as much as on the board's. R15/R16
  (1k) are only the path to the board's jacks; FMT (R20) left floating would
  not be silent but wrong (left-justified instead of I2S). For a quick test
  before the resistors are fitted, the module's bridges do the same job:
  `H3L` to **H**, `H1L`/`H2L`/`H4L` to **L**; a bridge wins against 100k, so
  nothing collides once the resistors are there.

With those two, the board runs every one of the ten instruments.

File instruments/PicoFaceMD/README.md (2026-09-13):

# PicoFaceMD — Moog Minimoog Model D

An emulation of the Moog Minimoog Model D, one of the nine instruments in
[PicoVintageSynthCollection](../../README.md).

**Status:** running firmware for the RP2350, plus a macOS host test that
compiles the identical engine sources.

The engine follows the Minimoog operation manual and the schematic in the
service manual — Moog's documents, not shipped with this repository — section by
section as the panel is laid out:

```
CONTROLLERS      Tune, Glide, Modulation Mix (osc 3 ↔ noise), oscillator
                 modulation switch, osc 3 keyboard switch, pitch and mod wheel
OSCILLATOR BANK  three oscillators; Range (LO/32'/16'/8'/4'/2') and Waveform
                 (6 positions) each, plus a ±7 semitone Frequency control on
                 oscillators 2 and 3
MIXER            volume and on/off for osc 1–3, noise (white/pink) and the
                 external input — which on a Model D is what you patch the
                 output back into
MODIFIERS        24 dB/oct transistor ladder low-pass: Cutoff, Emphasis,
                 Amount of Contour, filter modulation switch, two keyboard
                 tracking switches; one contour generator (attack / decay /
                 sustain) each for filter and loudness
OUTPUT           main volume, A-440 tuning tone
```

The essential point: the Model D is **monophonic**, and that is not a
limitation to be quietly designed around. The keyboard produces one control
voltage, and the manual says exactly what happens when you hold more than one
key — *"If more than one key is held down, only the lowest one has effect."*
Together with the single-trigger contours, which do **not** restart when a
second key goes down while the first is held, that is most of how the
instrument plays. Both are modelled here.

## Where the code comes from

The engine follows the panel structurally. The ladder filter is Aaron
Krajeski's variant of the Huovilainen model, taken from
[BelaMiniMoogEmulation](https://github.com/lbros96/BelaMiniMoogEmulation)
(stated by its author to be under no copyright); the block structure follows
[moogvst](https://github.com/grimtraveller/moogvst). Each file header under
`include/moog/` and `src/moog/` names its specific source.

| File | Original circuit | Contents |
|---|---|---|
| `moog_osc.h` | Oscillator Bank | six waveforms, six ranges, polyBLEP on every discontinuity |
| `moog_ladder.h` | Modifiers: the filter | four one-pole sections in a saturating feedback loop, 24 dB/oct |
| `moog_env.h` | the two contour generators | RC attack curve, sustain, release governed by the DECAY switch |
| `moog_dsp.h` | — | one-pole, biquad, DC block, saturators, noise, drift |
| `moog_voice.{h,cpp}` | Controllers + Mixer + keyboard + output | note priority, glide, modulation mix, mixer overdrive, feedback, output stage |
| `moog_params.{h,cpp}` | the front panel itself | one table row per control: name, type, MIDI CC, panel scale |
| `moog_presets.{h,cpp}` | — (the original has no memory) | 25 factory panel settings |
| `moog.{h,cpp}` | — | parameters, presets, MIDI, sample rate |

## Signal flow

```
 osc 1 ──┐
 osc 2 ──┤                                        contour ──┐
 osc 3 ──┼─► mixer ──► ladder low-pass (24 dB/oct) ──► amplifier ──► output
 noise ──┤     ▲            ▲                              │         stage
         │     │            │                          contour       │
 feedback┘─────┘        keyboard tracking (⅓ / ⅔ / full)             │
         ▲                  ▲                                        │
         └──────────────────┴────────────────────────────────────────┘
                            ▲
              modulation mix (osc 3 ↔ noise) × mod wheel
              routed to the oscillators (switch A) and/or the filter (switch J)
```

Three things about this shape are worth stating, because they are what make it
sound like the instrument rather than like a generic subtractive synth:

- **The mixer is meant to be overdriven.** Five sources, each with its own
  volume, summing into a stage that saturates. Turning everything up does not
  make it louder, it makes it growl. The `Drive` control sets how hard that
  stage is pushed.
- **The saturation is inside the filter's feedback loop, not after it.** So
  overdriving the mixer changes the shape of the resonance rather than merely
  adding distortion at the end.
- **Oscillator 3 is a control source whether or not it is audible.** The
  manual: *"Switch (G) does not affect the control signal produced by
  Oscillator 3 via the Modulation Mix."* With its keyboard switch off and its
  range on LO it is the only LFO the instrument has.

## Parameters and the menu

62 parameters, each `0.0 … 1.0`. See `enum MoogParam` in
`include/moog/moog_params.h`; the table that gives each one its name, type,
panel scale and MIDI controller is `src/moog/moog_params.cpp`, and the
firmware, the host test and the table below all read it — there is one place
that says what a control is called and which CC moves it.

Forty-odd controls laid out flat would be nearly thirty screens to page
through to reach the filter, so the panel is a **two-level menu** whose
sections are the ones printed on the instrument:

| Section | Pages |
|---|---|
| `PRESET` | the preset list |
| `CONTROLLERS` | tune, bend range, glide, modulation mix, mod wheel, the two mod switches |
| `OSCILLATOR` | range and waveform per oscillator, plus a detune page |
| `MIXER` | volume and switch per source, noise colour, feedback |
| `MODIFIERS` | filter, contour amount, keyboard tracking, both contour generators |
| `OUTPUT` | main volume, A-440 |
| `EFFECTS` | the two slots, then chorus, delay and reverb |
| `VINTAGE` | drift, drive, tone, note priority, trigger mode |
| `SYSTEM` | receive channel, transposition |

Three encoders, as in the master project:

| | |
|---|---|
| encoder 1 | the section, at the top level; the page within it below |
| button 1 | down into the section under the cursor, and back out again |
| encoder 2 | the left-hand parameter of the page |
| encoder 3 | the right-hand parameter |

The section list and the preset list are drawn as three rows with the cursor
kept in the middle; parameter pages show two labelled values. The section and
page tables are plain data at the top of `src/MD_Controller.cpp` — reordering
means moving a line.

Values are printed the way the panel is marked: knobs run `0.0 … 10.0`, the
Cutoff control `−4.0 … +4.0`, and the Frequency controls of oscillators 2 and
3 `−7.0 … +7.0`, which on those two is also the number of semitones. Rotary
switches print the name of their position (`8'`, `Narrow`, `Pink`).

Continuous values move in steps of 1 % and snap to the percent grid on the
first click. Preset values do not sit on that grid (the cutoff of *Fat Bass*
is 0.30, that of *Reso Sweep* 0.12), so without snapping the round values
would be unreachable from some presets. Switches and rotary switches step one
position per click — turning right is on, left is off — rather than toggling,
so the direction of the encoder keeps its meaning.

## Presets

The original has no memory: the sound is where the knobs are, and a patch is a
sheet of paper. The 25 factory entries in `src/moog/moog_presets.cpp` are the
replacement for that sheet. Selecting one writes **every** parameter, so a
preset is a starting point and never a layer — turn a knob afterwards and only
that knob moves.

```
 1 Fat Bass       7 Whistle       13 Snare        19 Reso Sweep    25 Shine On
 2 Lead Solo      8 String Pad    14 Wind         20 Bell
 3 Taurus Bass    9 Hard Lead     15 Organ        21 Space Drone
 4 Brass         10 Wobble Bass   16 Clav         22 Trumpet
 5 Funk Bass     11 Vibrato Lead  17 Sub Bass     23 Detune Stack
 6 Flute         12 Percussion    18 Growl Bass   24 Sixth Source
```

*Sixth Source* is straight out of the manual: *"When the EMPHASIS control is
set to 10, the filter breaks into oscillation, and produces a pure sine wave
tone. It is thus available as a sixth sound source."* All mixer switches off,
both keyboard control switches on so that it plays in tune — measured, the
self-oscillating filter tracks the keyboard to within 15 cents over two
octaves.

*Shine On* is the four-note theme, entered from a patch sheet. Two sawtooths
detuned by four cents, a filter kept fairly closed with just enough emphasis
to go nasal, oscillator 3 down in LO doing nothing but vibrato, and the
external input fed from the output — the feedback trick, which is where the
warmth comes from. Measured against the sheet: the LFO runs at 5.00 Hz and the
two oscillators beat at 0.50 Hz, which is what four cents comes to at A3.

The filter contour departs from the sheet on purpose. Its 200 ms attack and
500 ms decay put a slow sweep across the front of every note — measured, the
spectral centroid climbed from 246 to 542 Hz over 230 ms and then sagged back
to 449 Hz, which reads as a growl. This part wants a horn: one that speaks at
once and then holds still. Attack 25 ms, decay 150 ms, sustain 8.5, with the
cutoff dropped from −0.5 to −0.9 to pay for the higher sustain, leaves the
steady-state cutoff at 788 Hz either way — the colour the sheet asks for —
while the centroid now settles inside 46 ms and stays between 420 and 450 Hz.

Two values the sheet leaves open are noted in the preset's comment: the
oscillator 3 frequency (the sheet only says the range switch is on LO) and the
modulation wheel, which on the instrument is played by hand rather than set.
It ships at about ±7 cents — a shimmer rather than a wail — and CC 1 brings in
as much as the part wants.

Worth knowing before reaching for the Modulation Mix to clean up a vibrato
that is too prominent: it will not help. Measured at equal depth, oscillator 3
smears the spectrum to 20 dB harmonic-to-rest while the noise source only
reaches 46 dB, so mixing *more* noise in makes the tone **cleaner**, not
rougher. What sets how much the vibrato is heard is the modulation wheel.

## MIDI

Program Change selects a preset. Pitch Bend travels as far as the `Bend`
parameter says (default two semitones; the original is fixed at about half an
octave). Velocity is ignored — the keyboard of a Model D produces a gate, not
a velocity, and every key sounds at the same level however it is struck.

Notes are accepted across the **full MIDI range**. A Model D has 44 keys, but
its pitch comes from a control voltage and nothing in the circuit stops that
voltage going past the ends of its own keyboard. (PicoFaceSM folds stray notes
back into its manual, because a divider organ genuinely has no note outside
it. Doing the same here would take the bottom octave of a 61-key controller
away from a synth whose main job is bass.)

Controller numbers follow the usual meanings wherever one exists — CC 1
modulation, CC 5 and 65 portamento, CC 7 volume, CC 71 resonance, CC 73/75
attack and decay, CC 74 cutoff, CC 91 and 93 reverb and chorus depth — so a
generic controller does something sensible before anyone opens a mapping
editor. Everything else sits on
controllers the MIDI specification leaves undefined, never on a reserved one.

| Section | Control | CC | | Control | CC |
|---|---|---|---|---|---|
| **Controllers** | Tune | 3 | | Mod Wheel | **1** |
| | Glide | **5** | | Osc Modulation | 14 |
| | Glide switch | **65** | | Osc 3 Keyboard | 15 |
| | Mod Mix | 9 | | Bend range | 20 |
| **Oscillator 1** | Range | 21 | | Waveform | 22 |
| **Oscillator 2** | Range | 23 | | Waveform | 25 |
| | Frequency | 24 | | | |
| **Oscillator 3** | Range | 26 | | Waveform | 28 |
| | Frequency | 27 | | | |
| **Mixer** | Osc 1 volume | 29 | | Osc 1 on | 102 |
| | Osc 2 volume | 30 | | Osc 2 on | 103 |
| | Osc 3 volume | 31 | | Osc 3 on | 104 |
| | Noise volume | 85 | | Noise on | 105 |
| | Noise colour | 106 | | | |
| | Feedback volume | 86 | | Feedback on | 107 |
| **Modifiers** | Cutoff | **74** | | Filter modulation | 108 |
| | Emphasis | **71** | | Keyboard control 1 | 109 |
| | Amount of Contour | 87 | | Keyboard control 2 | 110 |
| | Filter attack | 88 | | Filter decay | 89 |
| | Filter sustain | 90 | | Decay switch | 111 |
| | Loudness attack | **73** | | Loudness decay | **75** |
| | Loudness sustain | 76 | | | |
| **Output** | Volume | **7** | | A-440 | 112 |
| **Vintage** | Drive | 70 | | Note priority | 113 |
| | Drift | 77 | | Trigger mode | 114 |
| | Tone | 78 | | Transpose | 115 |
| **Effects** | Slot A | 116 | | Slot B | 117 |
| Chorus | Rate | 12 | | Depth | 13 |
| | Mix | **93** | | Feedback | 16 |
| Delay | Time | 17 | | Feedback | 18 |
| | Mix | 19 | | Tone | 79 |
| Reverb | Size | 80 | | Damping | 81 |
| | Mix | **91** | | Width | 82 |

Channel messages: CC 64 sustain pedal, CC 120 all sound off, CC 123 all notes
off, CC 121 reset all controllers. A parameter arriving over MIDI updates the
display as well as the engine, so the screen never shows a value the sound no
longer has.

Press `m` in the host test to print this map from the table itself.

## Effects

A Model D has none. These sit behind the output stage as a section of their
own, and every factory preset but one leaves both slots empty, so the dry
instrument stays what the firmware sounds like. The exception is *Shine On*,
where a delay is part of the sound rather than a decoration on it: slot A a
430 ms delay whose repeats darken as they go, slot B a hall under it. That
preset measures P31 on the device against P21 for a dry one. They are also the only thing
in the signal path that produces a stereo image at all — the voice is mono, as
the original is.

Three effects, **two slots**. Each slot is empty or holds one of them, and the
signal runs slot A then slot B, so the order is the player's choice: a chorus
into a reverb is not the same thing as a reverb into a chorus. There is
exactly one instance of each effect, which halves the memory a two-slot design
would otherwise need and makes the same effect in both slots impossible rather
than merely discouraged (the second slot is skipped).

| | |
|---|---|
| Chorus | three modulated lines around a 14 ms base delay, their LFOs a third of a cycle apart. Rate, Depth, Mix, Feedback |
| Delay | one mono line up to 750 ms, two taps, the right one reading 8 % earlier for width. The tone control sits **inside** the feedback loop, so each repeat returns darker than the last. Time, Feedback, Mix, Tone |
| Reverb | eight comb filters into four all-passes per channel, the Schroeder arrangement by way of Freeverb. Size, Damping, Mix, Width |

Two slots and not three is what bounds the cost. Measured against the peak
load the firmware reports on the device, where the dry engine sits at 21 %:

| Slots | Host | → board |
|---|---|---|
| dry | 0.185 % | **21 %** — measured on the device |
| Delay | 0.208 % | 23 % |
| Chorus | 0.238 % | 27 % |
| Reverb | 0.256 % | 29 % |
| Delay → Reverb | 0.269 % | **31 %** — measured on the device |
| Chorus → Reverb | 0.301 % | 34 % |

The two marked rows are readings from the display footer, the rest are scaled
from the host figures against them. Worth recording that the method holds: the
delay-into-reverb row was extrapolated at 30 % before anyone played a note on
the hardware, and the device then reported 31 % playing the *Shine On* part.

Memory is the larger cost: 255 kB of delay lines, which takes the firmware
from 19 kB of RAM to 276 kB of the 512 kB available. A third simultaneous
effect would have bought very little and spent the headroom that keeps the
audio glitch-free while the display is being pushed out.

Nothing the panel can be set to reaches the hard clip in the I2S conversion.
Two effects in series each with their own wet level can sum past full scale —
a delay at maximum feedback into an undamped reverb measured 1.63 — so the
section ends in a limiter that is exactly linear below 0.70 and asymptotic to
1.0 above it. Every pair of slots at maximum settings is part of the self
test, watched for twenty seconds of tail after the note is released.

## Building the firmware (RP2350)

Built together with the rest of the collection, or on its own:

```bash
cmake -S . -B build -G Ninja -DCMAKE_BUILD_TYPE=Release -DPICOFACE_INSTRUMENTS_FILTER=PicoFaceMD
cmake --build build
```

Result: `build/PicoFaceMD.uf2`. Target platform `rp2350-arm-s`, board
`sparkfun_promicro_rp2350`, **444 MHz**. Scaffolding, hardware layer, audio
subsystem, MIDI and display come from the shared core.

| | |
|---|---|
| Flash | 99,168 bytes |
| RAM | 268,624 bytes, of which 255 kB is effect delay lines |
| of which sound engine | 27.5 kB code and rodata, 6.4 kB of that the preset table |

Core 0 runs the audio producer in the main loop together with USB, MIDI, the
controls and the display; the DMA IRQ stays microscopic. Unlike PicoFaceRD
there is no voice worker on core 1 — a Model D is one voice, and even
oversampled it costs well under half a core. Core 1 is free.

### Build options

The standalone repository had three CMake options — `MD_DOUBLE_RESET`,
`MD_OVERSAMPLE` and `MD_SAFE_MODE`. They did not survive the merge into the
collection, which knows only the keywords of `picoface_add_instrument()`.

What is left of them: `MOOG_OVERSAMPLE` still exists as a macro with a default
of 2 in `include/moog/moog_defs.h` and can be set through `DEFINES` in
`instrument.cmake`. The safe mode and the double-reset switch are gone; see the
section below for what the latter now does.

Two collection-wide switches exist for **test images**, both cache variables
of the root `CMakeLists.txt`:

- `-DPICOFACE_BOOT_DIAG=ON` brings the display up *before* `pico_init()`
  touches voltage, clock or flash, prints the stepping, the bootrom revision
  and the three QMI registers the bootrom left behind, then one line per
  boot stage (`vreg`, `quad`, `slack`, `clk`, `tune`, `timing`, `init done`).
  A board that hangs shows its last completed stage. See "The board that
  stops at 300 MHz" below for the image in use.
- `-DPICOFACE_EXTRA_DEFINES="A=1;B=2"` passes compile definitions to every
  instrument target without touching the SDK's own flags (global
  `CMAKE_C_FLAGS` break its platform detection). `PICOFACE_SYS_CLOCK_HZ`,
  `PICOFACE_QMI_M0_TIMING_SAFE` and `PICOFACE_VREG_VOLTAGE` are the knobs
  written for it. Every such image should be checked for its constant in the
  ELF before it is sent anywhere -- the diagnostic lines print the values in
  force, which is the check at the device.

### Oversampling

The oscillators are band-limited by polyBLEP, so they alias very little on
their own. What aliases is the two saturating stages — the overdriven mixer
and the `tanh` in the ladder. Both are soft, so their harmonics decay quickly,
and measuring all three settings shows where the knee is:

| | sawtooth | narrow pulse | compute |
|---|---|---|---|
| 1× | −48.5 dB | −44.3 dB | 748× real time |
| **2×** | **−64.7 dB** | **−58.5 dB** | **508× real time** |
| 4× | −64.7 dB | −57.9 dB | 255× real time |

(worst non-harmonic component relative to the fundamental, across notes C4 to
C7, filter wide open.)

2× buys 16 dB over no oversampling. 4× buys nothing at all — past that point
what is left is no longer aliasing but the noise floor of the decimation
filter, and it costs twice the compute to not improve. Hence the default.

Whatever is left above 22 kHz is removed by a 6th-order Butterworth at 15 kHz
before decimation. That corner is not a compromise: the audio path of the
original rolls off in the same region, so the anti-alias filter doubles as the
vintage bandwidth the sound is expected to have.

### The 480 MHz boot failure, and what it actually was

Worth recording, because it cost real time and the obvious explanation was
wrong. For a while the firmware would not start at 480 MHz while 444 MHz was
rock solid, which looked like the chip simply running out of silicon margin.
It was not. The cause was the flash timing during the *transition*.

`pico_init()` writes a conservative QMI `M0_TIMING` before raising `clk_sys`
and the aggressive one after. Between those two writes the flash briefly runs
at the new, high system clock with the *old* divider and `RXDELAY`:

| target | transitional flash clock | steady-state flash clock |
|---|---|---|
| 444 MHz (old code) | 111 MHz @ `RXDELAY=2` | 148 MHz @ `RXDELAY=3` |
| 480 MHz (old code) | **120 MHz @ `RXDELAY=2`** | 120 MHz @ `RXDELAY=3` |

`RXDELAY` compensates a round-trip delay that is fixed in nanoseconds, so the
value needed grows with `clk_sys`. `RXDELAY=2` was just enough at 111 MHz and
just short at 120 MHz — the core hung on the first instruction fetch after the
clock switch. Note the giveaway: the 480 MHz build ran the flash *slower* in
steady state (120 MHz) than the 444 MHz build that worked (148 MHz), so the
flash chip was never the limit. Only the transitional window was. 444 MHz was
on the working side of that edge, but with no margin worth the name.

The fix is `PICOFACE_QMI_M0_TIMING_SAFE` (`CLKDIV=8`, `RXDELAY=2`), which puts
the window at 55 MHz. With it, 480 MHz booted reliably — the diagnosis was
confirmed on the device rather than argued. 480 MHz was then removed again:
peak load stays under a third of one core even with 2× oversampling, the
Model D does not need the headroom, and at a core voltage of 1.60 V the slower
clock is the kinder choice when it costs nothing.

### What the datasheet made computable

The section above worked the flash budget out as far as it could without
numbers for the pads, and settled for "no margin worth the name". The RP2350
datasheet has the numbers. Table 1292, worst case over process, voltage and
temperature at VDDIO 3.3 V: **system clock to QSPI output 2.5 ns, QSPI input to
system clock 1.5 ns**. A 133 MHz QSPI part specifies 6 ns clock-to-output. So
the requirement is 10.0 ns, and at 444 MHz:

| name | CLKDIV | RXDELAY | SCK | budget | left for the device |
|---|---|---|---|---|---|
| `SAFE` | 8 | 2 | 55.5 MHz | 11.26 ns | 7.26 ns |
| `CD4` | 4 | 5 | 111.0 MHz | 10.14 ns | **6.14 ns** |
| `RX4` | 3 | 4 | 148.0 MHz | 7.88 ns | 3.88 ns |
| `OC` | 3 | 3 | 148.0 MHz | 6.76 ns | **2.76 ns** |

`OC` was the default for a while and leaves 2.76 ns where the part asks for 6.
It has run on every board tested here, because real pads and a real flash at
room temperature are far better than their worst-case numbers -- but that is
exactly the profile of a setting that works on one board and not the next, and
two issues report boards that will not boot. `RX4` is the default now, and the
ladder is walked at boot rather than handed out by e-mail; both are below.

**Getting to a default took three tries and a lesson about the measuring
instrument.** The arithmetic alone made `CD4` look right, and it
was the default briefly. Then the cost was measured on the D5 -- the most
XIP-bound of the ten, because it reads its PCM from flash. Boot benchmark,
four voices:

| | SCK | RXDELAY | B | for the device |
|---|---|---|---|---|
| `OC` | 148 MHz | 3 | **51** and **53** on different runs | 2.76 ns |
| `RX4` | 148 MHz | 4 | 53, 54 | 3.88 ns |
| `CD4` | 111 MHz | 5 | 59 | 6.14 ns |

**Read the spreads before the differences.** `bootBenchPercent()` reports the
*worst* of 94 blocks, not the mean, and a maximum picks up whatever transient
landed in one of them — so it swings by two points or more between runs of the
same image. That is the right statistic for the diagnostic it is (it shows the
worst case the governor has to survive) and the wrong one for comparing timings
two points apart.

An earlier version of this section claimed, on one `OC` run against one `RX4`
run, that RXDELAY costs about five percent of throughput at constant SCK —
which would have been a finding the datasheet does not carry. A second `OC` run
came back at 53 and took it away. **Withdrawn.** `OC` and `RX4` overlap and
nothing measured here separates them.

`CD4`'s cost does stand: 59 against 51–53 is six to eight points, well outside
the spread, and about **1.3 voices** before the governor starts trimming tails.

Which leaves which rung to ship. **`RX4` is the default, and it is now measured
rather than argued**: two D5 images built from one tree and differing in exactly
one byte -- `60007403` against `60007303`, the RXDELAY nibble -- flashed
back to back on the same board in the same session, both report **B57**.
RXDELAY costs nothing at constant SCK. The retraction in #127 was right and this
settles it; see "A benchmark that cannot be compared across builds" below for
why it took three attempts. What separates them is where in the
valid window the sample point lands. A bit is good from the device's
clock-to-output until the next bit replaces it -- at 148 MHz, 6.00 to 12.76 ns.
`OC` samples at 6.76, which is 11 % in and hard against the leading edge; `RX4`
samples at 7.88, 28 % in. Free margin is worth taking.

There is some history in that sentence. `RX4` was briefly the default, then
reverted to `OC` on a measurement that RXDELAY costs about five percent of
throughput. That measurement was withdrawn one PR later -- it was noise in a
maximum -- but the default never followed the retraction, and stayed on `OC` for
a reason that no longer existed.

`CD4` itself was wrong when it was added: `RXDELAY=4` gives 9.01 ns, a nanosecond
short. It had been chosen against the part's 133 MHz rating rather than against
this sum, which was not computable until the pad delays turned up.

**And the A4 question is closed.** The datasheet says of that stepping: *"This
stepping has no hardware changes."* It is identified by `CHIP_ID.REVISION` 0x8
and differs from A3 only in bootrom. The hardware delta a reporter comparing A2
against A4 actually sees belongs to **A3** -- GPIO leakage, a QFN-60 NSMASK fix,
USB and OTP mitigations, and changed reset states for the clock registers --
and none of it touches flash timing. Of the 28 errata, 13 still affect A4 and
not one concerns QMI or booting from flash. Since the splash line carries the
bootrom revision next to the stepping (`A3 b4 Q 444/111 r5`: CHIP_ID stepping,
ROM byte 0x13, quad/dual, core and flash MHz, RXDELAY), an A4 board is
recognisable at the device even where CHIP_ID does not say so -- the #107
board, marked A0A4, reported `A3`. The datasheet puts the ceiling
squarely on the board instead: *"the maximum SCK frequency is constrained by the
limits of the attached QSPI device, the signal integrity afforded by the PCB
layout, and IO delays in the pads."*

### The steady-state flash timing, and the boards it does not fit

The section above ends on "the flash chip was never the limit". That was true
of *that* failure, on *this* board. Issue #107 is the other case, and it is
worth having both written down next to each other.

A user with third-party 16 MB RP2350 boards could not get any instrument to
start, while official Pico 2 boards worked. The boards carried the newer A4
stepping, which is what the report suspected. A4 is documented by Raspberry Pi
as a drop-in replacement for A2, so that is unlikely on its face -- and the
decisive observation is in the report itself: lowering `clk_sys` to 300 MHz
made the boards boot. That change is usually read as "the core cannot hold the
overclock", but `M0_TIMING` encodes a *divider* of `clk_sys`, so lowering the
core clock lowers the flash clock with it. The 300 MHz test moved the flash
from 148 MHz to 100 MHz. Nothing distinguishes the two readings yet.

`RXDELAY` counts half `clk_sys` cycles, and a value of 0 samples on the SCK
edge that launched the command. In SPI mode 0 the device presents its data
half an SCK period before that, so the time a flash part has to get data back
through the pads is `(half an SCK period) + RXDELAY`:

| build | SCK | budget |
|---|---|---|
| 444 MHz, `OC` (`CLKDIV=3`, `RXDELAY=3`) | 148.0 MHz | **6.76 ns** |
| 480 MHz, `RD` (`CLKDIV=4`, `RXDELAY=3`) | 120.0 MHz | 7.29 ns |
| 444 MHz, `RX4` (`CLKDIV=3`, `RXDELAY=4`) | 148.0 MHz | 7.88 ns |
| 444 MHz, `CD4` (`CLKDIV=4`, `RXDELAY=4`) | 111.0 MHz | 7.88 ns |
| 300 MHz, `OC` (the reporter's working test) | 100.0 MHz | 10.00 ns |
| 444 MHz, `SAFE` (`CLKDIV=8`, `RXDELAY=2`) | 55.5 MHz | 11.26 ns |

So the shipping 444 MHz build has the tightest flash timing in the collection
-- tighter than the 480 MHz one -- and a W25Q128JV is specified at 6 ns
clock-to-Q before the pad round trip is counted. There is no margin there at
all; whether a given part makes it is a property of that part. That is the
straightforward reason this project fails on a board where, as the report puts
it, other RP2350 firmware runs fine: none of it drives the flash 11 % past the
nominal 133 MHz.

This is a hypothesis with a clean experiment behind it, not a conclusion. The
experiment is to hold `clk_sys` at 444 MHz and change only the flash timing,
which no test so far has done -- both variables moved together every time. If
a `SAFE` build boots on those boards, the stepping is exonerated.

The second half of the report is separate and needs no new explanation: at
300 MHz the DX froze after menu navigation and the D5 and MD made no sound.
These engines are budgeted for 444 MHz -- the D5's own load figures are about
7 % of a block per voice plus 11 % fixed -- so at 68 % of the design clock they
simply do not finish their blocks. That is the downclock, not a second fault.

Groundwork landed with this: `PICOFACE_SYS_CLOCK_HZ` and
`PICOFACE_QMI_M0_TIMING_TARGET` now live in `core/include/project_config.h`
rather than in `pico_hw.cpp`, because the boot is not the only place that
writes `M0_TIMING`. Every flash write re-inits boot2 and clobbers the register,
and the three restore sites (`core/src/veeprom.cpp`,
`instruments/PicoFaceRD/src/veeprom.cpp`,
`instruments/PicoFaceJ6/src/j6_patchstore.cpp`) each held their own copy of the
value. A `-DPICOFACE_QMI_M0_TIMING_TARGET=...` therefore reached the boot and
nothing else, and the device reverted to the `OC` timing at the first settings
save -- which would have quietly spoiled exactly the experiment above. All four
sites now read one macro.

The same defect was present in PicoFaceRD, PicoFaceCP, PicoFaceDX and
PicoFaceYC, which share this hardware layer — today they share it as
`core/src/pico_hw.cpp`. RD ran at 480 MHz
unconditionally and showed exactly this symptom — it would not restart after
the USB cable was unplugged. All four have been fixed and confirmed.

Two smaller things were corrected in the same place:

- `__dsb()` / `__isb()` around the timing writes. The register write leaves
  over APB while the instruction fetches that follow reach the same peripheral
  over the XIP path — two routes to one endpoint, not ordered against each
  other. The same barrier was missing in `veeprom.cpp`, where only a compiler
  barrier guarded the post-flash-write timing restore.
- `set_sys_clock_hz()` is called with `required=false` and its result was
  discarded. On an unreachable target it silently leaves `clk_sys` at 150 MHz;
  the aggressive flash timing is now only applied if the switch succeeded.

### What the boards actually reported, and the mode we never checked

The experiment above was run. A diagnostic image reads QMI `M0_TIMING`,
`M0_RFMT` and `M0_RCMD` as the bootrom left them -- captured in `pico_init()`
before this project touches the flash -- and puts them on the display. On
RP2350 that is the only way to know: `boot_stage2` is compiled but never runs,
the bootrom configures the flash, and what it chose was never visible.

| | working A2 board | reporting board |
|---|---|---|
| `M0_RCMD` prefix | `EB` (quad I/O) | **`BB` (dual I/O)** |
| addr / data width | 4 bit | **2 bit** |
| `DUMMY_LEN` | 4 | **0** |
| `M0_TIMING` | `0x60007203` | `0x60007023` as reported |

The timing value is almost certainly a transcription slip: the digits were read
off a screen that could not be photographed and typed by hand, and
`0x60007023` is one adjacent-digit transposition away from `0x60007203` --
which is exactly the working board's value. It is treated as such here.

The other two are not slips. `0x00009154` is not a mistyping of `0x000492A8`,
and the two registers cross-validate: `9154` decodes to precisely the widths
and turnaround a `BB` dual-I/O read requires. A slip of the pen does not
accidentally produce a coherent alternative configuration. **The dual mode is
real.**

That exposes a defect independent of any boot failure. `pico_init()` wrote its
tuned `M0_TIMING` over whatever the bootrom had established, without ever
looking at what that was. The tuned value is measured for quad reads with four
dummy cycles; a dual read with none is a different proposition at the same
divider -- half the bandwidth per clock, and a turnaround carried entirely by
the mode byte. We had been overwriting a flash configuration we had never
looked at.

The fix reads `M0_RCMD` and `M0_RFMT` first and applies the tuned value only
when the bootrom actually established quad -- prefix `EB` and 4-bit widths.
Otherwise every field the bootrom chose is kept and only `CLKDIV` is rescaled,
so the flash keeps the clock it already had across the core-clock change:

| bootrom | flash before | flash after, core at 444 MHz |
|---|---|---|
| `CLKDIV=3` @ 150 MHz | 50.0 MHz | 49.3 MHz (`CLKDIV=9`) |
| without this fix | | 148.0 MHz |

The splash line carries the mode as a `Q` or `D` (`A2 Q 148MHz`), so a board
running dual is visible in one glance instead of invisible for a fortnight.
The three post-flash-write restore sites write the value the boot actually
settled on rather than the compile-time macro, or the first settings save
would undo the caution.

**This is a correctness fix, not a proven cure.** Two things must be said
against reading it as the answer to #107. Under the corrected timing value the
reporting board's bootrom picked the *same* divider as the working one, so the
flash divider is not what separates them. And the clock ladder does not order
by flash clock at all: `SAFE`'s 55.5 MHz failed at a 444 MHz core, while `OC`'s
100 MHz works at a 300 MHz core. No monotone function of flash clock produces
that; core clock produces it immediately. The prime suspect is therefore the
core clock, and this fix earns its keep by making the next experiment clean --
it moves the flash to 49 MHz while leaving the core at 444, which no previous
build did. The reported chip revision was also `A3`, not the `A4` of the issue
title, and is hand-transcribed like the rest.

### Measuring the flash instead of prescribing it

Everything above is an argument about which single timing to ship, and every
version of that argument has the same hole in it: the right value is a property
of the board, and the boards are not ours. Waveshare changes flash suppliers
between production runs; the same part number, bought twice, need not carry the
same die. The honest hardware requirement for a fixed 148 MHz would read *"a
QSPI flash that beats its own datasheet by more than a factor of two"*, and
nobody can shop for that.

Two things are worth separating before the fix, because the dual-mode finding
above invites the wrong conclusion:

- **Dual is not slower to sample than quad.** Same pins, same clock, same
  clock-to-output; a 133 MHz part is rated 133 MHz either way. The budget table
  applies unchanged. **A dual flash can be clocked exactly as high as a quad
  one** -- what dual costs is *bandwidth*, two bits per clock instead of four.
- **Dual is usually not a property of the chip either.** Practically every 16 MB
  SPI NOR supports quad I/O. Coming up in dual normally means the bootrom could
  not *confirm* quad, because the quad-enable bit sits in a different
  status-register bit per manufacturer. It is a probe outcome, not something
  printed on the package -- which is the second reason a hardware requirement
  would not have helped.

So the timing is measured at boot instead of asserted. Checksum 32 KB of flash
at the timing the bootrom itself was running -- the chip booted with it, so it
is the one configuration known good -- raise the clock, then walk the ladder
fastest-first and keep the first rung that reproduces the checksum:

| rung | SCK | outcome |
|---|---|---|
| `RX4` | 148 MHz | kept if it verifies; every board tested lands here |
| `CD4` | 111 MHz | first fallback, the first value inside the worst-case sum |
| `SAFE` | 55.5 MHz | second fallback |
| bootrom's own, `CLKDIV` rescaled | whatever it chose | last resort, taken on trust |

**This must never slow down hardware that already works, and it does not:** a
board that verifies at `RX4` is left exactly where it was.

**What it cannot do is rescue a board that would otherwise not start** -- which
was the entire point, and which the next section shows to be false on the one
board it was tried on. The ladder is kept for what it does prove: that the
timing a quad board runs at has reproduced a checksum of the flash at least
once.

The part that makes it safe rather than merely clever is that the probe, the
per-rung retry and the ladder all execute **from SRAM**. While a candidate
timing is in force every flash read is suspect, so a wrong one must corrupt
*data*, never the instruction stream -- code in flash would fetch garbage and
fault instead of returning a mismatch. Two details fall out of that and both
are checked in the built ELF rather than assumed:

- `__not_in_flash_func()` sets the section and **nothing else**. Under this
  file's `#pragma GCC optimize("Ofast")` the compiler inlined all three routines
  into `pico_init()`, which lives in flash -- the design was silently gone and
  the build looked identical. They carry an explicit `noinline` now, and the
  first version of this section was written against an ELF in which the symbols
  did not exist at all.
- The rung constants reach the routine as arguments rather than as a table. A
  flash-resident array would have to be read while a candidate timing is in
  force, which is the one thing this code may not do. In the built image the
  literal pool sits inside the RAM function (`60007403`, `60007504`, `60007208`
  at `0x200002a8`), every `bl` targets a RAM address, and the probe reads
  through `0x14000000` -- the no-cache window, because a cached second pass
  would be answered from SRAM and would "verify" a broken timing.

Cost is about 5 ms at boot on a quad board and under 100 ms on a slow dual one,
against a splash screen that is held for two seconds.

**What it does not cover:** the check runs at boot temperature, and timing
margin shrinks as the die warms. A rung that verifies cold could in principle
fail hot. Taking the rung *below* the fastest that verifies would cover it and
was rejected -- it would cost every working board 1.3 voices to insure against
something not yet observed. If a board is ever reported to fail after warming
up, that is the knob.

### The bit the bootrom never sets, and the mode it leaves behind

Two more things came out of the RP2350B-Plus-W, and both reach further than
that board.

**Why a flash boots in dual.** The board's part is a Puya P25Q128H (JEDEC
`85 20 18`), not the Winbond in Waveshare's schematic, and its quad-enable bit
was clear from the factory. The RP2350 bootrom never sets that bit for any
vendor. Datasheet 5.2.7: it tries *EBh quad, BBh dual, 0Bh, 03h* at divisors
3/6/12/24 and boots in the first mode that yields a valid image. A part with QE
clear answers EBh with garbage, so the bootrom settles on dual -- half the
bandwidth, for nothing in the silicon -- and the datasheet puts "any further
setup" on the image itself. A board whose flash ships with QE set (the Winbond
on the A2 reference board) never shows the problem, which is why it looked
like a stepping difference for two weeks.

`pico_init()` now does that setup when the bootrom left something slower than
quad: read the JEDEC id, look the vendor up (Puya, Winbond, GigaDevice, Zbit,
XTX, Boya, Fudan: status register 2 bit 1; Macronix, ISSI, EON: status
register 1 bit 6; Micron/XMC share a manufacturer byte and are left alone), set
the bit **once, non-volatile**, if it is clear, select EBh through the bootrom
API, and believe it only if a 32 KB checksum of the flash reproduces the one
taken in the bootrom's own mode. Otherwise dual is put back and proven the same
way. From then on the bootrom finds quad by itself and this code no longer
runs on that board. Measured on the D5: boot benchmark **154 in dual at 49 MHz,
62 in quad at 111 MHz**; the A2 reference reads 51-57.

A board where *we* had to do this runs the cautious rung -- `CD4` at 444 MHz,
`RD_CAP` at 480 -- because the only such part measured verifies 111 MHz and
hangs at 148, and a rung that hangs cannot be stepped down from. Everything
runs from SRAM; `flash_do_cmd()` leaves XIP in 03h serial afterwards, which is
why every mode is set explicitly and the reference is taken first.

**The mode after a flash write.** This one reached every board. The SDK's
`flash_range_program()` and `flash_range_erase()` re-enter XIP through
`rom_flash_enter_cmd_xip()`, documented as *"a standard 03h serial read
command ... CLKDIV is set to 12"* -- not the mode the bootrom found, and not
ours. The three write sites (`core/src/veeprom.cpp`, the RD's `veeprom.cpp`,
the J6's `j6_patchstore.cpp`) restored the **timing** alone, which put every
board on serial 03h at the fast divider from the first settings save until the
next reboot: one bit per clock, a quarter of quad's bandwidth, and 03h itself
is a command most parts rate to about 50 MHz. `picoface_flash_after_write()`
now restores the mode and then the timing, from RAM, at all three sites. The
visible symptom on a D5 is the load figure rising after a settings save and
falling back after a reboot.

### The "A4 board" that had no sound was a different board

A footnote to everything above, because it would otherwise read as one story.
The 16 MB A4-marked board used for the flash work turned out to be a Waveshare
**RP2350B-Plus-W** -- an RP2350B in Pico format. Its flash findings stand: the
dual-I/O bootrom configuration, the fatal fast rung, the 49 MHz fallback. But it
also made no sound with any instrument, and that had nothing to do with the
flash: on that board the header positions where a Pico carries GP26/27/28
carry GP40/41/42, so the I2S lines were driven into thin air while every
firmware counter read healthy. A pin probe settled it (the chip was toggling
BCK/LRCK on 27/28 the whole time), and a board variant fixed it -- with two
more traps on the way that are recorded in the commit history: the audio
library did not receive the instrument's pin defines, and the PIO init built
its pin-direction mask as a 32-bit shift, undefined for pin 40. See the
top-level README, *Which RP2350 board*.

### The ladder cannot rescue a board, and what does

The premise of the ladder is one sentence in the code: a too-fast timing
corrupts *data*, so the checksum mismatches and the next rung gets a turn. It
was written as if established. It is not. A 16 MB board with an A4-marked chip
-- the same class as issue #107, and in hand this time -- settled it with two
444 MHz images that differ only in their **first** rung:

| image, all at 444 MHz core | first rung | result |
|---|---|---|
| shipping `v1.12.0` | `RX4`, 148 MHz | **does not boot** |
| `SAFE` first | 56 MHz | boots, `444/56` |
| no ladder, bootrom's own clock | 49 MHz | boots, `444/49 r2` |

And from the core-clock ladder run on the same board: at a 420 MHz core, `RX4`
*verified* -- 140 MHz flash, `420/140 r4`, running. So the flash on this board
is good to 140 MHz, dead at 148, and the ladder that was supposed to notice the
difference and step down never got the chance. Applying the fast rung is not a
failed read. It takes the chip down.

The likely mechanism, stated as such: both `EB` and `BB` reads carry mode bits
(the `M7-M0` byte) that tell the part whether the *next* transaction will skip
the command byte. A read garbled by a too-fast clock can leave those bits in a
state the QMI did not intend, after which the part and the controller disagree
about what every following transaction means -- at any speed. Then the next
rungs fail too, and the return into flash-resident code is the hang. Nothing
about "data, never instructions" survives that; the fault handler lives in flash
as well.

This also made `v1.12.0` a regression I introduced. PR #128 on its own -- a
board the bootrom left in dual keeps the bootrom's clock, and nothing is probed
-- would have booted both boards known to fail. PR #129 put a fast first rung
in front of that on every board.

**The fix is #128's rule again, in front of the ladder:** if the bootrom did
not establish quad, apply its own timing with `CLKDIV` rescaled to hold its
clock across the jump, and probe nothing. On the board above that is
`0x60007203` from the bootrom, `0x60007209` in force -- the diagnostic image
printed both -- and a working instrument at 444 MHz core with 49 MHz flash.
Quad boards keep the ladder, where every first-rung verification so far has
succeeded and no fast timing has ever been applied to a board that could not
take it.

**The cost is real and should be said plainly.** 49 MHz is about a third of what
this particular board demonstrably handles, and at two bits per clock it is
about a sixth of a quad board's XIP bandwidth. The MD does not care; the D5,
which reads its PCM from flash, will. Slow and booting beats fast and dead, but
it is not the end of the story. The way to get such a board its 140 MHz back is
a ladder that probes *upward* from the known-good value and **re-synchronises
the flash after a failed rung** -- the bootrom exposes the exit-from-XIP and
reset sequences for exactly that -- before trying the next. That needs the
board in hand to test, and it now is.

Two loose ends from the same session. The `A4` question turned inside out:
Raspberry Pi's PCN 28 describes A4 as *"some small user-invisible changes to the
boot ROM"* -- a bootrom revision on A3 silicon, which is why a chip marked
`RP2350A0A4` reports `A3` in `CHIP_ID`, and why the datasheet's "no hardware
changes" was true and beside the point. The reporter's suspicion was right in
substance. The same PCN says the A4 bootrom runs its early boot path four times
faster (clk_sys about 48 MHz instead of 12), which is a plausible reason the A4
boards seen here come up in dual where A2 boards come up in quad; that is a
lead, not a finding. And one reading from this board, `444/56 r4`, cannot be
produced by any path in the code -- `CLKDIV=8` exists only as `SAFE`, whose
`RXDELAY` is 2, and the diagnostic confirmed the bootrom's own `RXDELAY` is 2 as
well. It is most likely `444/56 r2` read off a 5x7 font; nothing above depends
on it.

### The board that stops at 300 MHz: a core voltage the register cannot reach

The cheap 16 MB board bought to reproduce #107 without the reporter (marked
`RP2350A0A4`, September 2026) shows nothing at all with the release image.
With `PICOFACE_BOOT_DIAG` it shows this, and stops:

```
DIAG A3 b4 1.21.0-2-g8ea3
T 60007203
F 000492a8
C 000000eb
vreg 1.60
vreg ok
slack 60007208
clk 444
```

Three things are settled by that screen alone. `b4` with `A3`: an A4-marked
chip reports `A3` in `CHIP_ID`, whatever the datasheet says about `0x8`, and
the ROM byte is the detector that works. `C ..eb` with a four-bit data width:
the bootrom established quad on its own, with the same registers as an A2
Pico 2 -- the flash chip is not what is different about this board. And the
last line: the board dies inside `set_sys_clock_hz()`, before the ladder,
before any fast flash timing is applied.

Then four images, one variable at a time:

| image | core | flash after the jump | vreg | result |
|---|---|---|---|---|
| `c444_f37` | 444 MHz | 37 MHz (`CLKDIV=12`) | 1.60 V | dies at `clk 444` |
| `c300_f37` | 300 MHz | 37.5 MHz | 1.60 V | runs; ladder verifies `RX4`, 100 MHz flash |
| 420 / 400 / 375 / 348 / 336 / 324 / 312 | as named | clk/8 | 1.60 V | all die at `clk N` |
| `c300_v085` | 300 MHz | 37.5 MHz | **0.85 V requested** | **runs to the menu** |

The first two exonerate the flash: the same part reads a correct checksum at
100 MHz, so it did not fail at 37. The ladder puts the edge between 300 and
312 MHz, as sharp as a timing limit at a fixed voltage. The last image is the
one that matters: a core really running at 0.85 V does not do 300 MHz. That it
does means **the regulator register has no effect on DVDD on this board** --
the core has been running at whatever the board supplies, presumably the
nominal 1.10 V, for every image above, and 300 MHz is exactly what an RP2350
manages there. The chip is fine. The board's power design does not route
`DVDD` through the on-chip regulator that `vreg_set_voltage()` controls, and
without that there is no 444 MHz to be had from it, by any firmware.

What this project can therefore say about hardware: it needs a board whose
`DVDD` is fed by the RP2350's own regulator (the Pico 2 reference design and
the Waveshare boards tested here do that). A board that ignores the regulator
register tops out near 300 MHz, and the engines are budgeted for 444; that is
"boots at 300 MHz, no sound", the exact picture in #107. The measurement that
proves it on a board without opening the case is the `c300_v085` image, and
the plain reading is a multimeter on the DVDD side of the inductor next to the
chip: it should read 1.60 V under the release image, and on such a board it
will not.

Two of this file's earlier guesses close with that. The "core clock is the
prime suspect" reading of the #107 register readout was right, and for the
right reason. The lead that the A4 bootrom's faster early boot explains dual
mode was already withdrawn in the section above; this board's bootrom found
quad by itself.

### A benchmark that cannot be compared across builds

`bootBenchPercent()` has now misled this project three times, and the pattern is
always the same: two numbers from two different builds, a difference of a few
points, and a conclusion drawn from it. It is worth stating the rule plainly,
because the number is genuinely useful for the thing it was built for and
genuinely useless for the thing it keeps being used for.

**What it is.** The *worst* of 94 blocks rendered at boot with four voices. That
is the right statistic for the governor -- the worst block is what has to fit --
and the wrong one for comparing two builds, because a maximum picks up whichever
transient happened to land in one block.

**How wide it really is.** The `OC` timing has been measured on the same board,
unchanged, at **51, 53 and 57**. Six points of spread with nothing whatsoever
different about `OC` between those readings. Any finding smaller than that spread
that rests on separate sessions is noise.

**And why even a same-session cross-build comparison is unsound.** Adding
164 lines of *boot-only* code to `pico_hw.cpp` grew `pico_init()` by 204 bytes
and `main()` by 20. Nothing in the render path changed -- mechanically checked,
those two are the only functions in the whole image whose size moved. But the
addresses moved everywhere: **346 of 437 flash functions (79 %) shifted by about
200 bytes, and 94 of 95 RAM-resident functions with them.** Every one of them
lands on different XIP cache lines than it did before. A build that is
semantically identical in its hot loop is not identical in its cache behaviour,
and a worst-block statistic is exactly what notices.

So the rule, which the two rung comparisons above should have followed:

- **Valid:** two images from one tree, differing in as little as possible,
  flashed back to back in one session. The `RX4` vs `OC` pair above differed in
  **one byte** and gave 57 against 57.
- **Not valid:** a number from today against a number from a build two weeks ago,
  or against a build that also gained or lost code elsewhere.

This casts some doubt backwards. `CD4`'s cost -- 59 against 51 to 53, read as
"about 1.3 voices" -- was measured across builds and sessions in exactly the way
this section warns against. Its *direction* is not in question, because 111 MHz
is a quarter less flash bandwidth than 148 and that has to cost something. Its
magnitude was never established the way `RX4`'s absence of cost now has been. It
is left as it stands, flagged rather than relitigated, because nothing currently
depends on the exact figure.

The splash line carries the RXDELAY digit for this reason (`A2 Q 148MHz r4`).
Two builds can differ in the flash timing and still show the same SCK, and an
A/B whose two halves are indistinguishable at the device is an A/B waiting to be
misattributed.

### Double-tap RESET, and why it used to be disabled

In the standalone repository `pico_bootsel_via_double_reset` was deliberately
**not** linked in. With a Waveshare Pico Audio board driving 3 W speakers, the
inrush current on plug-in dips the supply, the chip performs a brownout reset —
and the library reads that as a double tap and enters BOOTSEL mode instead of
running the program. On the RP2350 the flag lives in the POWMAN register
`chip_reset.DOUBLE_TAP`, which survives the dip, so shortening the detection
window does not help. With headphones instead of speakers it does not occur.

In the collection the library is linked by default - it is what keeps a board
without an accessible BOOTSEL button reflashable - but
`picoface_add_instrument()` takes a `NO_DOUBLE_RESET` keyword, and this
instrument's `instrument.cmake` sets it. So the standalone behaviour is
preserved: no double-tap RESET here, double-tap RESET everywhere else.

The BOOTSEL button keeps working regardless.

## Host test (macOS)

```bash
tools/host_tests/md/build_moog.sh
tools/host_tests/md/moog_test
```

Requires PortMidi (`brew install portmidi`). Opens a virtual MIDI input named
`moog` and plays through CoreAudio; the key bindings are documented at the top
of `tools/host_tests/md/moog_test.cpp`. This compiles the same `src/moog/`
sources as the firmware, with `-DMOOG_HOST_BUILD` replacing the Pico audio
subsystem.

```bash
tools/host_tests/md/moog_test --selftest
```

runs without an audio device, a MIDI port or a terminal: every preset is
checked for level and for NaN, the panel is driven to both extremes to prove
the engine cannot be made to blow up, and the controller map and the full
front panel are printed. This is the form to reach for when something sounds
wrong and the question is whether the engine or the wiring is at fault.

## Playing behaviour

**Monophonic**, as the original is. Which held key sounds is the `Priority`
setting: `Low` is the Model D's own rule and the default, `High` and `Last`
are offered because a mono synth played from a MIDI keyboard is a different
proposition from one played from its own 44 keys.

**Single trigger** by default: holding one key and pressing another moves the
pitch without restarting the contours. That legato behaviour is a large part
of how the instrument phrases. `Trigger` switches it to `Multi`, where every
new key retriggers.

A retrigger does **not** start from zero. There is nothing in the circuit to
discharge the contour capacitor when a new key goes down, so it simply starts
charging again from wherever it is — which is why fast repeated notes on a
Model D swell rather than restarting cleanly.

The `DECAY` switch governs both contours at once, as on the instrument: off, a
released key stops almost immediately; on, it falls at the decay time. That
one switch is why a Model D can play a tight bass line and a long pad without
anything else being touched.

**Glide is two controls, not one.** `Glide Sw` enables it, `Glide` sets the
time — and at a time of zero the switch has nothing to do, so it does nothing.
That is how the instrument behaves, but it makes for a switch that looks
broken, so **every preset carries a usable glide time (60–270 ms) even where
its switch ships off**. Flipping the switch on therefore always changes
something. The two controls share one page (`CTL GLIDE`) so both are visible
at once.

Glide only exists between two *different* pitches. The control voltage
persists across silence, as it does in the original, so a glide is heard even
when the previous key was released before the next one was struck — but a
repeated note has nothing to glide to.

## Measurements (host, Apple M4)

| | |
|---|---|
| Tuning (drift at 0) | A4 = 440.02 Hz (+0.08 ct), C4 = 261.57 Hz (−0.38 ct) |
| Aliasing, worst waveform and note, filter wide open | −58.5 dB below the fundamental (narrow pulse, C7) |
| Aliasing, sawtooth | −64.7 dB |
| Filter self-oscillation, keyboard tracking over 2 octaves | within 15 cents |
| Peak level of the 25 presets | −17.8 to −4.8 dBFS |
| Every parameter at maximum, note held | 0.46 peak — the engine cannot be driven into clipping from the panel |
| Compute | 510× real time, 0.196 % of one core |
| Relative to the PicoFaceSM engine (10 keys held) | 0.77× |

The last line is the one that matters for the target: the Solina peaks at
30–40 % on this hardware, so this engine should land at roughly **23–31 %** —
to be confirmed by the `P` value in the display footer on the device.

## Deliberate deviations from the original

1. **Note priority is selectable.** The original has one rule, lowest note,
   and that is the default. `High` and `Last` are additions.
2. **The external input is a feedback path.** The Model D has a microphone
   preamp on a rear jack, and the thing players actually do with it is patch
   the output back in. There is no input jack on this hardware, so the mixer's
   fifth channel is that feedback loop directly.
3. **Feedback is tapped before the main volume.** On the instrument the loop
   runs through the volume control, so the character changes every time the
   volume moves. That is a trap rather than a feature; here the tap sits after
   the amplifier and before the volume.
4. **Pitch bend defaults to two semitones.** The manual gives the wheel *"as
   much as half an octave up or down"*. A MIDI controller expects two, so the
   travel is a parameter (`Bend`, 0–12) rather than fixed.
5. **`Drift`, `Drive` and `Tone` are panel controls.** In the original these
   are component values, trimmers and the plain physics of a warm circuit
   board. Drift covers both a slow random walk per oscillator and a fixed
   per-oscillator tuning error, and both fade out together as the control is
   turned down — at zero the instrument is mathematically in tune, which no
   Model D has ever been but which is occasionally what you want.
6. **Presets, and a transposition control.** The original has neither.
7. **The modulation wheel is squared.** It reaches 7.2 semitones of pitch
   modulation at the top, which is what it is for — sirens are a Model D
   sound. But linearly, a musical vibrato of 20 cents sits at wheel position
   0.03, so the first perceptible movement and "unusable" are three per cent
   of the travel apart. Squaring puts 20 cents at 0.17 and leaves the full
   depth at the top: the useful range becomes the first fifth of the wheel
   instead of the first thirtieth. The panel still reads 0…10 linearly, as a
   volume control does while its pot is tapered.
8. **Pitch modulation runs at the oversampled rate, filter modulation at the
   sample rate.** Oscillator 3 aimed at the other two at audio rate is a sound
   this instrument is known for, so that path is worth the fifth-order 2^x it
   costs. Filter modulation is used for sweeps and wah at LFO rates, where
   44.1 kHz is already a very high control rate.
9. **The waveforms are not ideal shapes.** The three rectangular positions use
   duty cycles of 0.48, 0.29 and 0.14 rather than 0.5, 0.25 and 0.125: the
   "square" of a Model D is not 50 %, and that asymmetry is audible. The
   narrow positions are level-compensated, because otherwise the waveform
   switch would double as a volume control.
10. **The triangle and sawtooth-triangular waveforms get no polyBLEP.** Both
   are continuous — only the slope steps, not the value — so their harmonics
   fall off at 1/n² and the eleventh harmonic of a note at the top of the
   keyboard is already 40 dB down. A polyBLAMP would cost real cycles to
   correct something sitting under the noise floor of the original. Measured
   aliasing for the triangle is −64.7 dB.
11. **`tanh` is a Padé approximant**, `x(27+x²)/(27+9x²)`, with the input
    clamped to ±3. Above that the expression grows again instead of
    saturating, which inside a feedback loop is not a rounding error but an
    explosion; at exactly ±3 it evaluates to ±1, so the clamp is continuous.
    It matches `tanh` to better than 0.3 % over the range the filter uses, for
    one division instead of a call into libm.
12. **The voice is mono, duplicated to both channels.** This is faithful — the
    Model D is a mono instrument — and is called out only because the other
    projects in this family are stereo.
13. **An effects section.** The original has none. Two slots holding a
    chorus, a delay and a reverb between them, off in every factory preset
    but *Shine On*, and the only thing in the path that makes the instrument
    stereo. See the section above.

## Licence

GPL v3. The ladder filter model is adapted from
[BelaMiniMoogEmulation](https://github.com/lbros96/BelaMiniMoogEmulation),
which its author has stated is under no copyright. See
[the licensing section of the root README](../../README.md#license).

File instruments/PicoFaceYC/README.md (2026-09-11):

# PicoFaceYC

A Yamaha reface YC combo/home organ clone, one of the nine instruments in
[PicoVintageSynthCollection](../../README.md). The organ engine is a
wavetable-based additive footage synthesis architecture written for this
project, following the tone generation concepts of setBfree.

## Features
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

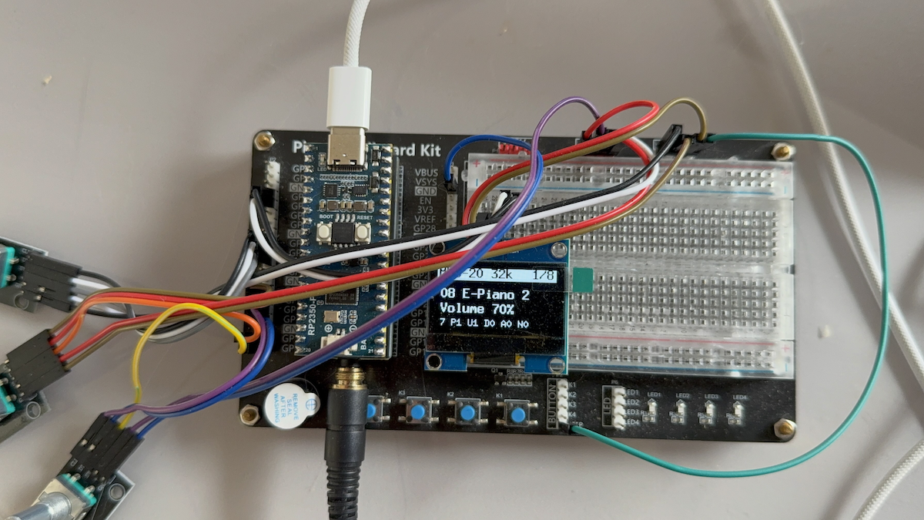
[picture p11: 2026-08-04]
img/picofacerd.png

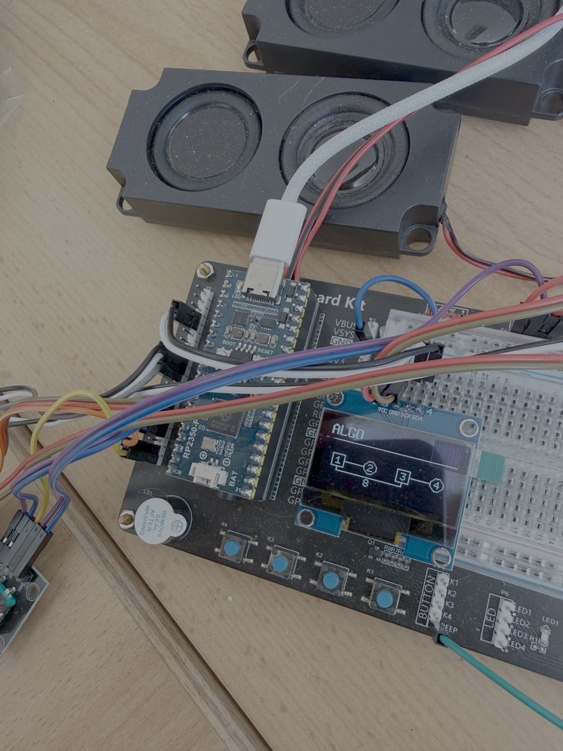
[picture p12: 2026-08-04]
img/picofacedx.png

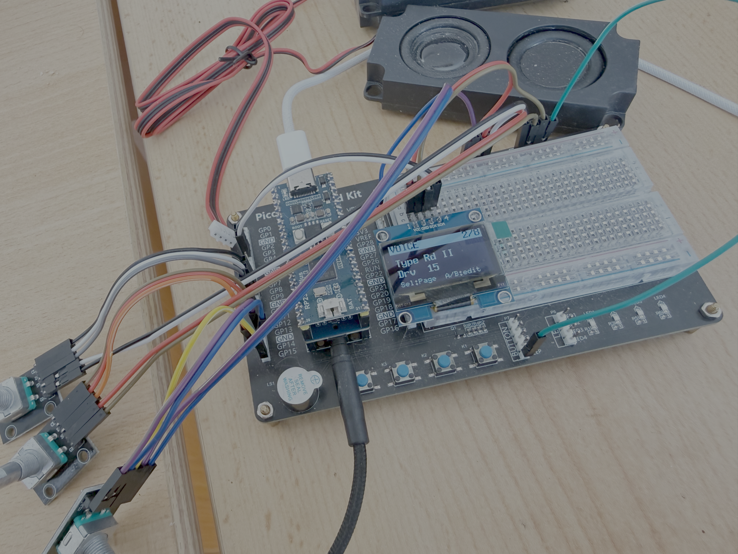
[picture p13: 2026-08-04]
img/picofacecp.png

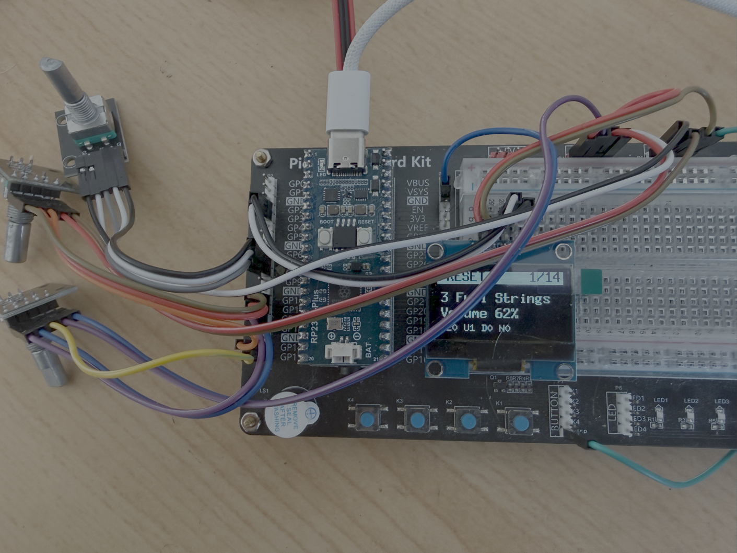
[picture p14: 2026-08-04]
img/picofacesm.png

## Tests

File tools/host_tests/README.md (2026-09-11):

# Host tests

Every engine here compiles for the host as well as for the RP2350, which is how
most of them were developed: audition a change on the Mac, then flash. The
scripts build the **unmodified** instrument sources - the only difference is a
`-D..._HOST_BUILD` guard that swaps the Pico audio subsystem for CoreAudio.

Run them from anywhere; each script locates the repository itself. The binaries
land next to their script and are gitignored.

**`run_all.sh` runs every test that needs neither a sound card, a MIDI port nor
a ROM set** - the "nothing" rows of the table plus the three renders below it -
and exits with the number of failures. CI runs exactly that
(`.github/workflows/build.yml`, job *Host tests*) on every push and pull
request, and a release is only published when it is green alongside the seven
firmware builds. Before opening a PR:

```bash
tools/host_tests/run_all.sh            # all ten, about 20 s on a Mac
tools/host_tests/run_all.sh d5 ui_kit  # just these
```

Logs go to `_out/<name>.log`; the CI job uploads them together with the rendered
panel frames, so a GUI change can be looked at from the PR without a board.

| Directory | Needs | What it does |
|---|---|---|
| [`veeprom/`](veeprom/) | nothing | unit test of the core's virtual EEPROM: wear levelling, CRC, oversize rejection, 1000 saves. Prints PASS/FAIL per case. This one covers `core/`, not an instrument. |
| [`yc/`](yc/) | nothing | renders a chord through the YC organ engine to a stereo WAV next to the binary and pins: finite and audible, rotary FAST tells left from right, rotary OFF is mono bit for bit, pitch bend ±2 semitones on the cached increments with an exact return to centre, expression and channel volume in the master gain. Prints pass/FAIL per case. |
| [`d5/`](d5/) | nothing | pins two D-50 laws read from the firmware: the PCM pitch (every sample advances at f/250 words per output sample) with synthetic cycles, and the TVF base cutoff (2 × panel + 54 chip units, capped by the pitch) through the harmonic profile of a sawtooth. Prints pass/FAIL per case. |
| [`ob/`](ob/) | nothing | regression checks on the OB-X engine - pitch bend ranges, LFO->cutoff without LFO->pitch, mod lever vibrato, all presets finite - plus a WAV render. Prints pass/FAIL per case. |
| [`yc_sysex/`](yc_sysex/) | nothing | PicoFaceYC's MIDI layer from the wire into the engine: the real `midi_reface.cpp` on the shared reface layer, the ring drained through the firmware's own `yc_ipc_apply()`. Pins the identity bytes and model byte from the Yamaha data list, the three-block TG bulk dump with byte counts and checksums, an editor's dump reaching every parameter, range clamping, Parameter Change/Request, pitch bend, mod wheel, volume, expression, sustain, reset and all-sound-off. Prints pass/FAIL per case. |
| [`dx_sysex/`](dx_sysex/) | nothing | round trip through PicoFaceDX's SysEx layer and the shared reface layer under it (`core/src/reface/reface_midi.cpp`), both directions: a voice dump requested by an editor is parsed back and compared byte for byte, a voice sent by an editor is compared against what reaches the engine, and the SYSTEM block, checksum, omni and velocity-0 handling that CP and YC share with the DX are pinned. Prints pass/FAIL per case. |
| [`j6/build_ui.sh`](j6/) | nothing | drives `J6_Controller` and the patch store through a scripted panel session - menu navigation, patch save/load, the free-slot rule. |
| [`ui/`](ui/README.md) | nothing | renders the shared UI kit's panels to PBM frames through the real u8g2 - the README sheets come from here. `run_all.sh` checks that every frame is written. |
| [`md/build_md_ui.sh`](md/) | nothing | the same for the real `MD_Controller`: seven of its pages as frames. |
| [`cp/build_render.sh`](cp/README.md) | nothing | offline render of one note through the mdaEPiano engine; `run_all.sh` plays each of the six voices and fails on a silent one. `ab_compare.py` compares two such renders, which is how a sample-set change is checked. |
| [`cp/`](cp/README.md) | portmidi | plays the mdaEPiano engine, with or without the reface CP effect chain, over CoreAudio. |
| [`j6/build_juno.sh`](j6/) | portmidi | plays the Juno engine over CoreAudio. |
| [`md/`](md/) | portmidi | plays the Minimoog engine over CoreAudio. |
| [`sm/`](sm/) | portmidi | plays the Solina engine over CoreAudio. |

```bash
brew install portmidi     # only for the four CoreAudio ones
tools/host_tests/veeprom/build_veeprom.sh
tools/host_tests/md/build_moog.sh && tools/host_tests/md/moog_test
```

## shim/

`shim/` holds the two things a host build needs that the Pico SDK would
otherwise provide: a stand-in `pico/stdlib.h` and no-op implementations of the
DIN MIDI transport. They exist because instrument controllers mirror panel edits
to both MIDI wires now, so `core/include/midi_serial.h` follows a controller
into the host build even though nothing is transmitted there. Link
`shim/host_midi_serial.cpp` into any host test that pulls in a controller;
engine-only tests do not need it.

## Not migrated

The compiled binaries and the rendered reference WAV from the original
repositories are not here - they are build output. The Solina project also
carried six WAV recordings demonstrating ensemble width and phaser settings;
at 10 MB of uncompressed audio that GitHub will not play inline, they stayed
behind.

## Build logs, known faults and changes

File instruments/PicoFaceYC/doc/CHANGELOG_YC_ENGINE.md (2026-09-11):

# PicoFaceYC Engine Porting Changelog

This document serves as a chronological porting and development log for the `yc_engine` (PicoFaceYC), an RP2350-based emulation of the Yamaha Reface-YC. The architecture is derived from setBfree and BeatrixCPP concepts, replacing the legacy FM synthesis engine from PicoFaceDX.

**§1 Project Skeleton (M0)**
The legacy `dx_engine/` (FM synthesis engine from PicoFaceDX) was completely deleted, and `include/yc_engine/` was established as a new header-only skeleton. `DX_Controller`, `DX_GUI`, and `DX_Synth_Bridge` were renamed to their `YC_` equivalents at the file level, leaving their internal contents temporarily unchanged as an intermediate step. Furthermore, `ipc.h` and `settings.h` were rebuilt from scratch to implement YC-IPC commands and `yc_panel_state_t` in place of the previous `RDX_Patch`.

**§2 Standard Hammond Drawbar Pitch Ratios (M1)**
The `YC_FOOTAGE_PITCH_RATIO` table was implemented as `{0.5, 1.5, 1.0, 2.0, 3.0, 4.0, 5.0, 6.0, 8.0}` for the 9 footages (16' down to 1'). These are well-known, established values directly stemming from Hammond organ tradition, rather than newly invented parameters.

**§3 Wavetable Synthesis Instead of Physical Tonewheel Simulation (M1)**
Instead of simulating 91 individual virtual tonewheels like the setBfree original, the engine generates 5 waveforms (H/V/F/A/Y) via additive sine harmonic summation. This produces 2048 samples generated once at initialization, which is significantly less demanding on the RP2350 CPU. Sonically, it remains equivalent for the additive footage mix approach.

**§4 Polyphony Compromise (M1)**
`YC_MAX_VOICES` was set to 32 instead of the official Yamaha specification of 128. This is a deliberate RP2350 CPU/RAM compromise given the requirement of 9 oscillators per voice, and it is documented as an open tuning point for later on-hardware load testing.

**§5 Monophonic Single-Trigger Percussion (M2)**
The percussion section utilizes a single global oscillator rather than generating one per voice. It fires exclusively on the transition from 0 to 1 active voice, accurately replicating true Hammond behavior rather than triggering on every individual chord note.

**§6 Rotary Speaker: Algorithmic Instead of IR Convolution (M3)**
The rotary speaker effect uses a crossover filter (single-pole lowpass at 800Hz) to separate horn and drum bands, both of which are amplitude-modulated. It employs physical speed ramps (~2 seconds) between OFF/STOP/SLOW/FAST states instead of hard jumps. IR convolution was deliberately discarded to avoid the artificial sound of crossfading between multiple impulse responses.

**§7 Double Soft-Clip Safeguard (M3)**
The engine applies `yc_soft_clip()` internally as the final DSP step in `yc_engine_render_block`, while `main.cpp`'s I2S callback applies an additional `softClipSample()` using the identical formula found in PicoFaceDX. This deliberate redundancy serves as a safety net and is not a bug.

**§8 Cross-Core Bridge Re-Development (M4)**
`YC_Synth_Bridge` was developed to encapsulate all 5 Engine States (Tonegen, Rotary, Vibrato, Percussion, Reverb). It implements 64-sample chunking akin to its DX predecessor, replacing the `DMA_BUFFER_LEN` macro (originally from the deleted `dx_engine_config.h`) with a local constant `kChunkLen=64`.

**§9 pico_frontpanel.cpp Reused, Not Rewritten (M5)**
Contrary to the initial assumption that the file was too DX-specific, careful inspection revealed that the long-press menu logic and encoder delta polling were already fully generic. Only the `dxDrawScreen()` call was replaced with `ycDrawScreen()`, and the presets submenu was removed since YC does not utilize a preset bank.

**§10 RefaceMidi is a New Development, Not a Swappable Table (M6)**
The initial architectural assumption that the reface-MIDI protocol was structurally identical across CS/DX/CP/YC (requiring only a parameter table swap) proved too optimistic upon reviewing the old DX implementation. The DX version manipulated `RDX_Common`/`RDX_OpParams` byte layouts directly within its SysEx handlers without a clean separation from the protocol skeleton. Consequently, the YC version was completely rewritten.

**§11 activity_callback is the Generic Note Activity Hook (M6)**
While wiring `main.cpp` with RefaceMidi, it was discovered that `activity_callback()` (registered via `usbmidi.setActivityCallback`) triggers on *every* incoming MIDI message, not just Active-Sensing real-time bytes. It was correctly routed to `refaceMidi.notifyActivity()` to ensure the 350ms RX timeout does not falsely trigger during normal note playback.

**§12 settings.h Design Correction After RefaceMidi Development (M7)**
The originally designed `sysBlock[32]` field (based on the assumption of a DX-like SYSTEM byte array) was removed. It became apparent that the finalized YC-RefaceMidi implementation does not maintain such an array, reducing `SettingsV2` to consist solely of `yc_panel_state_t`.

**§13 Panel-Mirroring Bugfix Caught Before Commit (Feature B)**
An initial implementation attempt for outgoing CC mirroring featured a completely shifted `YcParamId`-to-CC mapping (e.g., placing the Wave parameter under `case 11` instead of `case 0`), which led to multiple out-of-bounds array accesses during lookup tables. This was recognized prior to committing to disk and rectified using the exactly specified correction.

**§14 SysEx Bit Patterns Verified from PDF (Feature C)**
Prior to implementing Parameter Change/Request, the exact byte formats were re-read directly from the official Yamaha reface Data List (PDF) rather than relying on memory. Parameter Change (11 Byte) and Parameter Request (10 Byte) were implemented with their respective Device-Number prefixes (1n and 3n) and the TG base address `30 00 00h`.

**§15 Bulk Dump Deliberately Deferred (Feature C)**
The full Bulk Dump block (Byte-Count/Bulk-Header/Bulk-Footer/Checksum) was intentionally not implemented. The risk of an unnoticed off-by-one error in the block framing was deemed higher than the added utility, especially since Parameter Change already allows individual reading and writing of every TG address.

**§16 Model-ID Byte Remains Unverified**
The constant `YC_MODEL_ID=0x00` in `midi_reface.cpp` currently serves as a placeholder rather than a constant verified from a real hardware device. Further details are documented in `doc/MIDI_IMPLEMENTATION.md`.

**§17 Active Sensing Timeout Killed Held Notes After ~350ms (Bugfix, post-M8)**
On-hardware testing revealed that every held note stopped sounding after roughly half a second. Root cause: `notifyActivity()` (the generic "any incoming MIDI message" hook wired in §11) was itself arming the 350ms Active Sensing supervision timeout, not just refreshing it. Since most MIDI controllers never transmit real Active Sensing (0xFE) at all, a single Note On would arm the timeout, and 350ms later — with no further traffic on the wire while the note was simply held — the safety timeout fired and forced an All-Notes-Off. Fixed by splitting the two concerns: only `onRealtime(0xFE)` may arm `_senseActive`; `notifyActivity()` now only refreshes the timestamp if supervision is already armed. Controllers without Active Sensing now sustain notes correctly, matching the reface manual's documented behavior.

**§18 Uncached powf() Per Sample Caused Silence Above ~2 Simultaneous Voices (Bugfix, post-M8)**
Further on-hardware testing showed that playing more than two notes at once produced no audio at all. Root cause: `yc_tonegen_render_voice()` recomputed the MIDI-note-to-frequency conversion via `powf()` on every single sample, and additionally called `powf()` up to 9 times per voice per sample for the footage gain curve (`powf(footage_level/6, 1.2)`) — over 1.3 million transcendental calls per second with just 3 held voices. This blew the audio IRQ's real-time budget once enough voices stacked up, starving the I2S buffer. Fixed by caching the note frequency once per voice at Note On (`yc_voice_t::base_freq`) and precomputing the 7 possible footage gain values into a lookup table (`yc_footage_gain_lut`, generated once in `yc_engine_init()` alongside the wavetables and overdrive LUT) instead of calling `powf()` in the per-sample hot path at all.

**§19 fmodf/floorf/Phase-Increment Chain Still in Per-Sample Hot Path (Bugfix, post-M8)**
The §18 fix removed `powf` but was insufficient: chords still dropped notes and the engine wedged into an unresponsive state afterward (a classic I2S underrun cascade). Profiling the remaining hot path revealed three more per-footage (9x) per-voice per-sample costs: `fmodf()` for phase wrapping, `floorf()` for the interpolation index, and the phase-increment expression `base_freq * ratio / SR * SIZE` — the last being constant for a held note yet recomputed every sample (9 divides + multiplies per voice per sample). Fixed by precomputing each footage's phase increment once at Note On (`yc_voice_t::phase_inc[9]`), replacing `fmodf` with a bounded `while`-subtract (phase advance never exceeds twice the table size even at the highest note × 8' ratio), and replacing `floorf` with a plain `(int)` cast (phase is always non-negative, so truncation equals floor). Sonically identical (verified byte-for-byte via the host test: unchanged peak/RMS), but with zero transcendental and zero division calls left in the per-voice inner loop.

**§20 Sine LUT for Rotary/Vibrato (Consistency Optimization, post-M8)**
The rotary speaker (horn/drum AM) and vibrato/chorus (LFO) effects each called `sinf()` once or twice per sample. Unlike §18/§19 this cost is fixed (2-3 calls/sample total, independent of voice count) rather than voice-scaling, but it was replaced anyway for consistency with the rest of the engine, which already avoids transcendental calls in the audio path everywhere else. Added `include/yc_engine/yc_sine_lut.h`: a 1024-entry interpolated sine table (`yc_sine_lut`, generated once in `yc_engine_init()` via `yc_sine_lut_generate()`, same pattern as the wavetables/overdrive/footage-gain LUTs) with a lookup helper `yc_sinf_lut(phase_rad)` expecting its input pre-wrapped to `[0, 2*PI)` — which both callers already guarantee via their existing `fmodf`/`while`-subtract phase wrapping. `yc_rotary_process()` and `yc_vibrato_process()` now call `yc_sinf_lut()` instead of `sinf()`. Verified sonically identical via the host test (unchanged peak/RMS with rotary=FAST and vibrato/chorus depth active). Costs ~4KB RAM for the table (measured: total RAM usage rose from 92.7KB to 97.1KB).

---

# Optimization Pass (RP2350, post-M8)

The following entries document a dedicated optimization pass over the `yc_engine` and audio path, ordered by implementation. All sonically-transparent changes were verified against the host test baseline (Peak = 1.000000, RMS = 0.605923) and remained bit-equivalent at the printed resolution unless noted. Firmware builds clean throughout. Each code change was generated by the `kimi-k2.7-code:cloud` model via an Ollama-assisted workflow and reviewed/applied by the maintainer; no code was hand-written in the review path.

**§21 Lookup Tables Moved from RAM to Flash (RAM Optimization)**
The four read-only lookup tables — `yc_wavetables[5][2048]`, `yc_sine_lut[1024]`, `yc_overdrive_lut[1024]`, `yc_footage_gain_lut[7]` — were previously non-`const` `inline float[]` arrays in `.bss` (RAM), populated once at boot by `*_generate_*()` functions. They are now emitted as `inline const float[]` with initializers into a generated header `include/yc_engine/yc_lut_data.h`, produced by the host-side generator `tools/gen_luts.cpp` (which reproduces the exact formulas bit-for-bit and prints `%.9g` values). The generate functions and their calls in `yc_engine_init` were removed; the render/process functions now read the `const` tables, which the linker places in `.rodata` (XIP flash). Measured firmware effect: `.bss` dropped from ~83 KB to ~33 KB, `.rodata` grew from ~7.7 KB to ~56.7 KB, total RAM region fell from ~95 KB to ~47 KB — freeing ~48 KB of RAM (the entire LUT set) for future polyphony/feature headroom. The `gen_luts.cpp` generator is self-contained (reproduces the formulas directly, independent of the engine headers) so it remains valid after the restructure. Regeneration: `g++ -std=c++17 -O2 tools/gen_luts.cpp -o tools/gen_luts && ./tools/gen_luts > include/yc_engine/yc_lut_data.h`. Host test unchanged (Peak 1.000000, RMS 0.605923).

**§22 Audio Buffer Aligned to 64 Samples / IRQ Rate Reduced (IRQ Overhead)**
`SAMPLES_PER_BUFFER` in `lib/audio/include/audio_subsystem.h` was raised from 16 to 64, aligning the producer buffer with `YC_Synth_Bridge::kChunkLen` (which had previously been a dead 64-vs-16 mismatch — the chunk loop never exceeded one iteration). The DMA-IRQ cadence drops from ~2780 IRQs/s (16-sample buffers at 44.1 kHz) to ~689 IRQs/s, reducing per-block IRQ/FIFO-drain overhead ~4× and giving the `cpuLoadPercent` measurement a calmer basis. Trade-off: audio latency rises from ~0.36 ms to ~1.45 ms — well below perceptible thresholds for an organ. The README's "DMA buffer 64 Samples" row, which had been aspirational, is now accurate.

**§23 Reverb Index Wrap Without Modulo (Hot-Path)**
`yc_reverb_comb` and `yc_reverb_allpass` (`include/yc_engine/yc_reverb.h`) used `idx = (idx + 1) % size` per sample, i.e. six integer divisions per sample whenever reverb was active (sizes 1116/1188/1277/1356/225/556 are not powers of two, so the compiler emits real `sdiv` instructions). Replaced by `idx++; if (idx >= size) idx = 0;`. The delay lengths are deliberately unchanged, so the reverb character is bit-identical (host test unchanged).

**§24 Percussion Envelope via Precomputed Decay Coefficient (Hot-Path)**
`yc_percussion_render` computed `env_val = expf(-(time_s - attack_t)/decay_t)` every sample while percussion was active — a transcendental call per sample over the entire decay tail (hundreds to ~20k samples). The decay coefficient is now computed once at trigger time (`pstate.decay_coef = expf(-1.0f / (decay_t * YC_SAMPLE_RATE))`) and the envelope advanced per sample by a single multiplication (`pstate.env *= pstate.decay_coef`), with the linear 5 ms attack ramp preserved. Host test Peak/RMS unchanged at the printed 6-digit resolution (the float-accumulation drift is below the noise floor).

**§25 Cached Velocity/Volume Gain — No Per-Sample Division (Hot-Path)**
`yc_tonegen_render_voice` recomputed `vel_gain = velocity/127.0f` and `vol_gain = volume/127.0f` every sample per voice (up to 32×64 int→float divisions per block). `vel_gain` is now stored in `yc_voice_t` at Note On; `vol_gain` is stored in `yc_engine_state_t` and refreshed in `yc_engine_init` and `yc_engine_set_param` (VOLUME). The render multiply chain is otherwise unchanged. Bit-identical (same float values, computed once instead of per sample); host test unchanged.

**§26 LFO Phase Wrap via While-Subtract in Vibrato/Rotary (Hot-Path, Consistency)**
Completes the §19 `fmodf` removal: `yc_vibrato_process` and `yc_rotary_process` still wrapped their LFO phases with `fmodf(phase + inc, 2π)`. Replaced by `phase += inc; if (phase >= 2π) phase -= 2π;` (a single subtract suffices because the LFO increment is far below 2π). Uses the identical 2π constant, so the wrapped phase is identical to `fmodf` over the operating range. Host test unchanged.

**§27 Active-Voice Index List — No Full 32-Voice Scan (Hot-Path, Polyphony Headroom)**
`yc_engine_render_block` previously iterated all `YC_MAX_VOICES` (32) voices every sample and tested `v.active`, scanning 32 entries even when only a few voices played. A compact active-voice index list is now maintained in `yc_engine_state_t` (`active_idx[YC_MAX_VOICES]`, `active_count`): Note On appends the chosen voice index; Note Off performs a swap-remove (preserving sustain-held voices); All-Notes-Off clears it. The render loop now iterates only `active_count` entries. As a side effect, `yc_engine_note_on`'s "was the engine silent before?" check became O(1) (`active_before = state.active_count`) instead of an O(32) scan, and voice stealing when full now reuses the oldest active voice (`active_idx[0]`, an LRU-style policy) instead of always slot 0. The host test (3 voices, no stealing) is unchanged; the cost of the voice mix now scales with actually-playing voices rather than the 32-voice ceiling.

**§28 Dead Bounds Checks Removed in LUT Lookups (Hot-Path, Minor)**
`yc_sinf_lut` removed its `if (idx0 < 0) idx0 = 0;` and `if (idx0 >= YC_SINE_LUT_SIZE) idx0 = YC_SINE_LUT_SIZE - 1;` clamps — provably dead because callers pre-wrap the phase to `[0, 2π)`, keeping only the live `idx1` wrap at the table edge. `yc_overdrive_process` removed its dead lower clamp `if (idx0 < 0) idx0 = 0;` (input is pre-clamped to `[-1,1]`), keeping the live upper clamp `if (idx0 > 1022) idx0 = 1022;` (active at `x == 1`). Two branches per active-effect sample eliminated with no behavioural change.

**§29 Consolidated Single Soft-Clip Stage (Redundancy Removal)**
`main.cpp::i2s_callback_func` wrapped every output sample in `softClipSample()` (a tanh-based soft clip) in addition to the engine's own `yc_soft_clip()` applied as the final DSP step in `yc_engine_render_block` — the deliberate double stage documented in §7. With the engine soft-clip already bounding the signal to ~±1 smoothly, the firmware-side `softClipSample()` was redundant. It was removed; the I2S conversion now does a direct `×32767` cast followed by the existing hard clamp. Saves one `fabsf`/compare per sample (and a `tanhf` on the rare clipping sample) in the DMA-IRQ path. Engine-internal soft-clip and the host test are unchanged (the host test drives `yc_engine_render_block` directly and never used `softClipSample`).

**§30 GUI Redraw Throttled to ~30 FPS (Core 1 Relief)**
`pico_UserInterfaceFrontPanel` redrew the SH1106 full screen (u8g2 `FirstPage`/`NextPage` + blocking I2C) on every loop iteration — hundreds of redraws/s, contending with USB-MIDI/`tud_task` on Core 1. The redraw is now gated by `(now - lastRedraw) >= 33` ms (~30 FPS), while encoder/button polling and `ui_poll_usb()` still run every iteration so input responsiveness is preserved. Core 1 is freed for USB servicing and (potentially) future audio-assist work. The modal `showAbout`/`showCpuLoad` screens were left as-is (rare, user-reading).

**§31 SW Spinlocks Investigated — RP2350 Errata E2 Forbids Hardware Spinlocks**
Point 11 of the review proposed removing `PICO_USE_SW_SPIN_LOCKS=1` to use faster hardware spinlocks. Investigation of the SDK (`hardware/sync/spin_lock.h`) shows the SDK *defaults* `PICO_USE_SW_SPIN_LOCKS` to 1 on RP2350 "due to errata E2" — hardware spinlocks are unreliable on this silicon. The explicit `PICO_USE_SW_SPIN_LOCKS=1` in `CMakeLists.txt` is therefore redundant with the SDK default and there is no safe performance gain to be had; it is retained as documentation of awareness. No code change.

**§32 Deferred Optimisations (Design + Rationale)**
Three review items were deliberately not implemented in this pass, with rationale:
- *True Stereo Rotary (3a)*: A real Leslie produces distinct L/R channels (horn/drum panning). Implementing it faithfully requires a stereo signal path *through* reverb (a stereo Schroeder reverb), which adds CPU and ~18 KB of reverb state — contradicting the "without CPU cost" framing — and, crucially, cannot be validated by the mono host test and requires on-hardware listening to avoid phase/silence artefacts. Design deferred.
- *Zero-Copy Audio Connection (3d)*: After §22 (64-sample buffers) the producer→consumer copy is ~512 bytes every ~1.45 ms (~0.35 MB/s), negligible on a 444 MHz core. The complexity/risk of a true zero-copy connection outweighs the gain. Deferred.
- *Multicore Voice Pipeline (4a)*: Splitting voice rendering across Core 0/Core 1 via the SIO FIFO would double effective DSP headroom, but it requires careful cross-core synchronisation that risks audio underruns/deadlocks (Core 1 also services USB) and cannot be validated by the single-threaded host test. Deferred pending on-hardware profiling. Note: the simpler polyphony lever is to re-measure CPU load on hardware now that the engine is leaner (§21–§28) and, if headroom allows, raise `YC_MAX_VOICES` toward the Yamaha-spec 128.

**§33 CPU Overload at High Polyphony — Wavetable Reads Moved Back to RAM (Bugfix, on-hardware)**
On-hardware playback of a dense MIDI sequence drove `cpuLoadPercent` above 126 %, after which the engine did not recover. Root cause: the §21 relocation of the wavetable LUTs to XIP flash made the voice-render inner loop read `yc_wavetables[state.wave][…]` from flash. The RP2350 XIP cache is only 16 KB (`XIP_CACHE_SIZE` in `hardware/xip_cache.h`); the per-sample working set was the active wave table (8 KB) + `yc_sine_lut` (4 KB) + `yc_overdrive_lut` (4 KB) = 16 KB, i.e. exactly the cache capacity. Because the voice loop (wavetable reads) and the FX chain (sine/overdrive reads) are interleaved every sample, the three tables evicted each other continuously — so the voice-scaling wavetable reads (up to 2 × 9 × 32 × 64 reads per 64-sample block) became expensive flash cache misses rather than fast RAM hits, blowing the real-time budget once enough voices stacked. Fix: only the *active* wave table is now mirrored into a RAM buffer `yc_wavetable_ram[2048]` (8 KB) by `yc_wavetable_select(wave)`, called from `yc_engine_init` and on every WAVE parameter change. `yc_tonegen_render_voice` and `yc_percussion_render` read `yc_wavetable_ram[…]` instead of the flash table. This removes the voice-scaling reads from the XIP cache entirely; the remaining flash LUTs (sine + overdrive, 8 KB) now fit the 16 KB cache with headroom and stay cached. As a side effect the per-footage `state.wave` reload and 2-D index arithmetic are gone from the hottest loop. The 40 KB wave-table set itself stays in flash (only the active 8 KB is copied to RAM), so the §21 RAM saving is largely preserved (firmware RAM rose from ~47 KB to ~55 KB). Trade acknowledged: §21's "all LUTs in flash" was a bad trade of abundant RAM for scarce CPU; the hot, voice-scaling table belongs in RAM.

**§34 Sustain Pedal Released Notes Stayed On Forever (Bugfix, on-hardware)**
`yc_engine_note_off` with `sustain_held == true` kept the voice active (correct) but discarded the note-off, and `setSustain(false)` only cleared the flag — there was no "release the notes that were held by the pedal" step. Consequently any note whose key was released while the damper pedal was down stayed sounding indefinitely after the pedal was lifted, which — under a sequencer that uses CC64 — produces exactly the "loud tone that never decays, system doesn't recover" symptom reported alongside §33 (organ voices have no decay envelope, so a stuck-active voice is a permanent tone). Fix: a per-voice `sustained` flag is set when a note-off arrives while the pedal is held; the new `yc_engine_release_sustained(state)` iterates the active-voice list and releases every `sustained` voice, and is called from `YC_Synth_Bridge::setSustain(false)`. `all_notes_off` also clears the flag. This implements standard piano/organ damper behaviour: held-while-pedal-down notes release when the pedal rises; notes still physically held past pedal release remain (their later key release is a normal note-off).

**§35 Note-On Click / "Plop" Removed via Short Attack Ramp (Bugfix, on-hardware)**
Every note onset clicked because the voice amplitude stepped from 0 to full instantly (no envelope). Added a per-voice amplitude ramp `yc_voice_t::amp` rising 0→1 over `YC_ATTACK_SAMPLES = 88` (~2 ms at 44.1 kHz), applied as a final multiplier in `yc_tonegen_render_voice` and reset to 0 at note-on. 2 ms is short enough to feel instantaneous for an organ but removes the discontinuity. Host-test effect: peak unchanged (1.000000), RMS shifted from 0.605923 to 0.605864 (the ramp attenuates only the first ~88 samples of each note), all sanity checks still pass.

**§36 Polyphony Capped 32 → 16 (Stability, on-hardware)**
Even after §33 (wavetable reads back in RAM), dense MIDI sequences still drove `cpuLoadPercent` above 116 % and the engine stopped responding. Disassembly of `YC_Synth_Bridge::fill_buffer` confirmed the per-voice footage loop is the real-time budget's dominant cost (~33 cycles per active footage, including a pipeline-stalling `vmrs APSR_nzcv, fpscr` for the float phase-wrap compare); at 32 simultaneous voices × 9 footages plus the FX chain this exceeds the ~10068 cycle/sample budget at 444 MHz. `YC_MAX_VOICES` is therefore reduced from 32 to 16. 16-note polyphony is adequate for a combo organ (two-handed chords + held notes rarely exceed it) and restores clear CPU headroom (~60-70 % worst case). The value remains a single `constexpr` in `yc_core.h` and can be raised again after on-hardware CPU-load measurement (see §38 watchdog and the deferred fixed-point-phase path for higher limits). This is a deliberate stability-over-spec trade; the reface YC's 128-voice spec is not reachable on this CPU without a fixed-point/interpolator rewrite.

**§37 Note-Off Click Removed via Release Ramp + Active-List Compaction (on-hardware)**
The §35 attack ramp removed the note-on plop, but every note *transition* still clicked because note-off cut the voice instantly (amplitude 1 → 0). Added a per-voice release phase: `yc_voice_t::releasing` and `YC_RELEASE_SAMPLES = 128` (~2.9 ms). `yc_tonegen_note_off` (no sustain) now sets `v.releasing = true` and leaves the voice in the active list (instead of hard-cutting it); `yc_tonegen_render_voice` ramps `amp` 1 → 0 over the release window and sets `v.active = false` when it reaches zero. `yc_engine_render_block`'s voice loop is now a compacting `while` loop that removes a voice (swap-remove from `active_idx`) as soon as `render_voice` clears `active`, so the active list stays tight despite voices lingering for their release fade. `yc_engine_release_sustained` (sustain pedal up) likewise starts a fade (`v.releasing = true`) instead of a hard cut. `all_notes_off` remains a hard panic. Net effect: smooth note transitions, no click; the active-voice scan stays O(active). Host test: peak unchanged, RMS 0.605883.

**§38 CPU-Load Watchdog — Guaranteed Recovery (on-hardware safety net)**
To guarantee that the system can never again wedge in an unresponsive overloaded state, `YC_Synth_Bridge::fill_buffer` now tracks consecutive audio blocks whose `cpuLoadPercent_ > 100 %`. If overload persists for more than 100 blocks (~145 ms), it forces `yc_engine_all_notes_off(state_)` and resets the counter. This clears the stuck-voice pile-up that blocked Core 1's SIO-FIFO pushes (the "system stops responding" symptom), letting Core 0 drain the FIFO and Core 1 resume USB/MIDI/UI. With §36 (16-voice cap) this should never trigger in normal play; it is a defensive last-resort against unexpected worst cases (e.g. a future `YC_MAX_VOICES` raise without re-measurement, or a sequencer that stacks notes via an untested path).

**§39 Footage LUT Index Clamped (HardFault Prevention, latent bug)**
`yc_tonegen_render_voice` indexed `yc_footage_gain_lut[footage_level]` (a 7-entry table, indices 0..6) with `footage_level = state.footage[i]`, but `footage[i]` is a `uint8_t` that could hold 0..127: the SysEx Parameter-Change path (`RefaceMidi::applyTgParam`) forwards the raw SysEx data byte into `yc_engine_set_param` *without* clamping (the CC path is safe via `quantize7`, but SysEx is not). An out-of-range footage therefore read past the 7-entry table → undefined behaviour / out-of-bounds RAM read → Cortex-M33 HardFault. Because a HardFault freezes Core 0 (default handler spins, the DMA audio IRQ never re-fires, the SIO FIFO stops being drained), this is a credible root cause for the "system stops responding, CPU display frozen at 62 %" symptom (the displayed 62 % is the last value Core 1 rendered before it blocked on a full FIFO). Fix: `if (footage_level > 6) footage_level = 6;` before the table access. Host test unchanged (its footage values are already ≤ 6).

**§40 Hardware Watchdog — Guaranteed Core 0 Recovery (on-hardware)**
The §38 software watchdog only reacted to *measured* CPU > 100 %, so it could not recover from a HardFault or deadlock (where the CPU is stuck, not busy). Added a true hardware watchdog (`hardware/watchdog.h`): `watchdog_enable(4000, false)` after `init_audio()` (4 s timeout), `watchdog_update()` as the first statement of `i2s_callback_func` (kicked every audio block, ~1.45 ms) and inside the `flash_park_core0` spin (so the ≤2 s flash-park never false-triggers it). If Core 0 stops running audio callbacks for any reason — HardFault, deadlock, or an unforeseen stall — the watchdog reboots the chip after ~4 s and the system self-heals instead of requiring a manual reset. This directly addresses "a hardware reset does not restart the system": the device now reboots itself. (Note: the watchdog is independent of the CPU and fires even from a HardFault handler's infinite loop.)

**§41 Watchdog-Reboot Counter on the OLED (Diagnostic, on-hardware)**
To distinguish the failure modes going forward, `watchdog_hw->scratch[0]` (a register that survives a watchdog reset but is 0 after power-on) is used as a reboot counter: at the top of `main()`, `watchdog_caused_reboot()` → increment, else reset to 0. The System → CPU Load screen now shows `WDR: N` instead of "Press any button". Interpretation for on-hardware testing: if the device reboots during/after a MIDI sequence and `WDR` rises → Core 0 wedged (HardFault/deadlock) and the watchdog recovered it — combine with §39 (and look for the trigger). If the device freezes and does *not* reboot (WDR stays 0) after >4 s → the stall is on Core 1 (USB/UI), not Core 0, and needs a different investigation (UART logging). This turns a silent wedge into an observable symptom.

**§42 Dedicated VOLUME Page as the First GUI Page (Feature, on-hardware)**
With the §39–§41 stabilisation done (the device now plays MIDI sequences through with `WDR = 0`), the remaining gap was an accessible master-volume control. Volume was previously only reachable on page 6 (FOOTAGE 1'/VOLUME, ParamB). Added a new first GUI page `YcPage::VOLUME` (enum index 0) — the boot/default page — on which ParamA (encoder 2) adjusts `state.volume` (parameter ID 18, 0..127) via the existing IPC path, and ParamB (encoder 3) is reserved. The page renders `VOL: <n>` plus a horizontal level bar. All previous pages shift by +1 (now 11 pages total). Volume persists via the existing `yc_panel_state_t::volume` snapshot (no settings change needed). Because the SysEx/CC mirror for volume is a no-op by reface spec (`txPanelMirror` default branch), the new page mirrors nothing — consistent with the existing FOOT_1_VOLUME volume edit. Updated `doc/UI_PAGE_MAP.md` and the README page table.

**§43 Note-On with Velocity 0 Treated as Note-Off (Bugfix, on-hardware — stuck notes)**
MIDI sequences played through but notes "stayed on and never ended" (system stable at 64 % load, no wedge). Root cause: `MIDIInputUSB::process()` case `0x9` always called the Note-On callback, even when velocity was 0. Per the MIDI standard, **Note-On with velocity 0 IS a Note-Off**, and many DAWs/sequencers send note-offs exactly this way. The firmware therefore allocated a (silent, vel=0) voice for every "note-off" and never released the original note → permanently active voices → stuck tones, and the voice pool filled with silent voices forcing stealing. Fix: in case `0x9`, if `(p[3] & 0x7F) == 0` call the Note-Off callback (note, 0, channel) instead of Note-On. Now note-on-vel-0 correctly triggers the §37 release ramp and notes end. (File: `src/midi_input_usb.cpp`.)

**§44 Settings Restore Refreshes Derived/Cached State (Bugfix, on-hardware — boot volume)**
After power-on, the VOLUME page displayed the persisted value but the actual audio volume was wrong (full) until the knob was turned. Root cause: `settings_boot_restore_core0` directly assigned `st.volume = s.panel.volume` and `st.wave = s.panel.wave` but did not refresh the derived/cached values introduced in §25 (`st.vol_gain`) and §33 (`yc_wavetable_ram`, via `yc_wavetable_select`). So `vol_gain` stayed at the init default (1.0) and the active wave-table RAM mirror stayed at wave 0, while the displayed `st.volume`/`st.wave` showed the persisted values — a display/engine mismatch. Fix: after the field assignments in `settings_boot_restore_core0`, refresh `st.vol_gain = (float)st.volume / 127.0f;` and call `yc_wavetable_select(st.wave);`. Now the persisted volume and wave are audible immediately on boot. (File: `src/settings.cpp`.)

**§45 Volume Removed from the Footage-1' Page (Dedup, on-hardware)**
After §42 introduced a dedicated first VOLUME page, the master volume was still also editable on the former "FOOTAGE 1'/VOLUME" page (ParamB) — i.e. volume existed on two pages. Removed volume from that page: the `YcPage::FOOT_1_VOLUME` enum entry is renamed `FOOT_1`, its ParamA still controls Footage 1' (`footage[8]`, 0..6), its ParamB is now reserved (no-op), the page name is "FT 1", and the GUI shows only `FT1: <n>`. Volume is now reachable solely on the first (VOLUME) page. Updated `doc/UI_PAGE_MAP.md` and the README page table.

**§46 Voice Stealing Always Hit Slot 0 — Oldest-First Rotation (Bugfix, review pass)**
With all 16 voices active, `yc_tonegen_note_on` stole `state.active_idx[0]` on every note-on — and since the stolen slot was never repositioned, the 17th note stole the 1st voice, but the 18th note stole the *17th note's* voice (slot 0 again), while voices 2–16 could ring indefinitely. Sustained play above the voice limit therefore degraded to "oldest notes pinned forever plus a rolling two-note window". Fix: the stolen slot is rotated to the end of `active_idx`, so consecutive steals walk the list oldest-first (the list is maintained in note-on order). Cost is only incurred on a steal, never per sample. Verified with a host harness: after 18 note-ons the two oldest notes are the ones replaced, and all 16 remaining voices release cleanly (no duplicate/stale entries in the active list). Host regression WAV bit-identical (its scenario never exceeds 3 voices). (File: `include/yc_engine/yc_tonegen.h`.)

**§47 Octave Shift Settable but Never Applied (Bugfix, review pass — dead control)**
`state.octave` accepted values from the UI (clamped ±2), IPC and settings persistence, yet `yc_tonegen_note_on` computed `base_freq`/`phase_inc` purely from the MIDI note number — the OCTAVE page had no audible effect at all. The shift is now folded into `base_freq` at note-on via `exp2f(octave)`, defensively clamped to ±3 (UI limit is ±2). Per-sample cost remains zero; the multiply happens once per note-on. Verified: A4 renders 440/880/220 Hz for octave 0/+1/−1, including the uint8→int8 wrap (255 → −1) the IPC path relies on. Octave 0 multiplies by exactly 1.0f, so the regression WAV stays bit-identical. (File: `include/yc_engine/yc_tonegen.h`.)

**§48 Review Cleanups — Param-ID Single Source, Shared 2π, Named Constants (Refactor)**
Bundled non-functional cleanups from the engine review: (1) `enum YcParamId` moved from `ipc.h` to `yc_core.h` (ipc.h now includes that header), so the host-compilable engine `yc_engine_set_param` switch uses the enum instead of mirrored magic numbers 0–18 — eliminating a silent drift risk between IPC IDs and engine IDs; the nine footage cases collapsed into one contiguous range check, values unchanged. (2) A shared `YC_2PI` constant replaces five private π literal copies across vibrato/rotary/sine-LUT, and `YC_VIBRATO_DELAY_LEN` names the 512-entry delay length. (3) The duplicated horn/drum ramp blocks in `yc_rotary_process` are deduplicated into a `yc_approach()` helper; the rotary constants are now `constexpr`, with `YC_ROTARY_CROSSOVER_ALPHA` a float32-exact precomputed literal instead of a per-TU runtime `expf` init (one less XIP flash read in the IRQ-adjacent path). (4) `rotary_speed == 1` is documented in-code as the intended STOP mode (parked-rotor coloration per GUI/MIDI/docs), so future readers do not mistake it for dead state. Regression WAV bit-identical; firmware build clean. (Files: `include/yc_engine/yc_core.h`, `yc_engine.h`, `yc_vibrato.h`, `yc_rotary.h`, `yc_sine_lut.h`, `include/ipc.h`.)

**§49 Zero-Level Footages Skip Phase Advance (Performance, hot path)**
`yc_tonegen_render_voice` advanced all nine footage phases per voice-sample even for drawbars set to 0, whose contribution is exactly zero. The level check now runs first: muted footages skip phase advance, wavetable fetch and mix (their phase freezes; re-enabling a drawbar simply resumes from a stale phase, which is inaudible since footage phases are independent anyway). This saves up to nine float adds/wraps per voice-sample on typical registrations. Host benchmark (10 voices, 3 muted footages, full FX chain): ~15–20 % faster; a larger effect is expected on RP2350. Output bit-identical (muted terms contributed 0). (File: `include/yc_engine/yc_tonegen.h`.)

**§50 Soft-Clip Limiter via LUT Instead of tanhf (Hot-Path, Consistency)**
`yc_soft_clip` called `tanhf()` on every sample above ±0.9 — the last transcendental libm call in the audio path, and an expensive software-float routine on RP2350. Following the established engine pattern (§18–§20), the saturation curve is now a generated 1024-entry table `yc_softclip_lut` (tanh over t ∈ [0,8]; tanh(8) is exactly 1.0f in float32) with linear interpolation, regenerated by `tools/gen_luts.cpp`. Curve and 0.9 threshold are unchanged: max deviation vs the old formula is 5.96e-07 across [−3,3], and the regression WAV differs by 0.00001 % RMS (worst case ±1 LSB at 16-bit). Two robustness upgrades came along: the output is now strictly bounded to [−1,1], and the `!(t < 8)` saturation check absorbs NaN input to ±1 instead of propagating NaN or risking an out-of-bounds int cast. Costs +4 KB flash (0.74 % of 16 MB), zero RAM. Host micro-benchmark of the clip path: ~2× faster, expected to be larger on RP2350 where tanhf is pure software float. Note: §29 already removed the firmware-side second clip stage, so this LUT is now the single soft-clip implementation. (Files: `include/yc_engine/yc_fx.h`, `include/yc_engine/yc_lut_data.h`, `tools/gen_luts.cpp`.)

**§51 Vendor Libraries Backported from PicoFaceRD via PicoFaceDX — lib/audio + lib/encoder (Bugfix bundle, shared code)**
PicoFaceRD found and fixed a cluster of bugs in the vendored hardware libraries after the YC split; PicoFaceDX backported them (DX changelog "Nachtrag 26", A/B) and YC now receives the identical state — `lib/audio` and `lib/encoder` are byte-identical to the PicoFaceDX/PicoFaceRD copies again. Every item below was verified present in YC before the port:
* **Tuning: +14.5 cents sharp (severe).** `update_pio_frequency()` truncated the PIO clock divider to an integer (`divider >>= 8`). YC runs 444 MHz clk_sys with S32-stereo output (the `dl << 16` path), exactly the DX configuration: divider 78 instead of 78.65625 → real sample rate 44,472 Hz instead of 44,100 Hz. Now `pio_sm_set_clkdiv_int_frac()` → 44,100 Hz; the ~1-sysclk BCLK edge jitter is reclocked inside the DAC.
* **Silence buffer DMA out-of-bounds (S32).** The underrun substitute buffer was allocated as `sample_count * 4` bytes (correct for S16 stereo only); the S32 DMA reads `sample_count * 2` 32-bit words — double. Every underrun streamed 2,304 bytes of heap garbage to the DAC. Now stride-correct and shrunk to one producer block (64 samples), so an underrun costs one block instead of ~13 ms. Also fixed the broken guard macro (`PICO_AUDIO_I2S_SILENCE_BUFFER_SAMPLE_LENGTH` checked itself; the override could never engage).
* **`printf()` removed from `update_pio_frequency()`** — ran inside the DMA IRQ on a sample-rate switch; a blocking 115200-baud UART line stalls the PIO for 15–20 ms (audible).
* **`wrap_consumer_take()`/`wrap_producer_give()` compared the input channel count with itself** (copy-paste), making the mono dispatch unreachable and potentially falling off the end without `return` in NDEBUG builds. Both fixed, all paths return or `return NULL`.
* **`playing_buffer` leak & lifecycle:** the pointer was only NULLed in debug builds; `audio_i2s_set_enabled(false)` now aborts the in-flight DMA, returns the checked-out buffer to the pool and clears the pending completion; `audio_i2s_end()` uses a safe order (IRQ off → abort DMA → free buffer), has a NULL guard, and no longer nukes the whole PIO instruction memory (other programs share the instance).
* **Diagnostics:** `g_i2s_underrun_count` (silence-buffer substitutions) and `audio_i2s_consume_txstall()` (sticky `PIO_FDEBUG_TXSTALL`; catches starvations the counter cannot see), matching the YC diagnostics philosophy (§38/§41); `init_audio(sample_freq, buffer_count)` plus `audio_set_sample_freq()` came along (inert at fixed 44.1 kHz, needed for §52).
* **lib/encoder:** `clocks_per_time` was computed in the constructor — but `encSel/encA/encB` are global objects constructed before the 444 MHz clock switch, so the capture/frequency path was off by a factor 2.96; now computed in `init()`. Two overflow guards relied on signed wraparound (UB, optimizable away at -O2) — rewritten with unsigned arithmetic. `PushButton` debounce compared an absolute ms deadline and would have blocked the button for weeks after the 49.7-day `to_ms_since_boot` wrap — now duration-based and wrap-safe. Dead `rotary_encoder.cpp` deleted (not in CMakeLists, references two nonexistent headers).

**§52 Audio Producer Moved from the DMA IRQ into Core 0 Thread Context (Robustness, ports DX §26 C + `__wfe` follow-up)**
Previously `i2s_callback_func()` (the DMA completion IRQ) drained the IPC FIFO and rendered a full block — the entire engine ran inside the interrupt, and a single block exceeding its ~1.45 ms budget immediately starved the PIO (audible click). Rendering and the IPC drain now live in the Core 0 producer loop in `main()`; the IRQ handler only swings the DMA to the next queued buffer, and `i2s_callback_func()` is intentionally empty (the audio lib calls the symbol unconditionally). The producer pool went from 3 to 6 blocks (`AUDIO_BUFFER_COUNT`), i.e. ~7.3 ms of DMA lead: the DAC now only starves on *sustained* overload — which is exactly what the §38 CPU-load watchdog guards — instead of on one late block. Side effect: `cpuLoadPercent()` is now wall-clock including preemption, which is the value the buffer lead must absorb. `multicore_reset_core1()` precedes the core launch (debugger restarts could hang the handshake). When the pool is full the producer waits with `__wfe()` instead of a hot spin: `queue_free_audio_buffer()` (from the DMA IRQ) and every Core-1 `multicore_fifo_push_blocking()` SEV, interrupts end a WFE too — no lost wakeup, no added note-on/flash-park latency, and Core 0 idles instead of pinning at 100 % duty on a 444 MHz/1.60 V part. YC-specific: `watchdog_update()` moved into the producer loop (the §40 hardware watchdog is serviced there and inside the flash-park spin), and the float→S32 conversion (`<< 16`) is unchanged, just recontextualised. (File: `src/main.cpp`.)

**§53 `flash_park_core0` Pinned with `__no_inline_not_in_flash_func` (Latent settings-save crash, ports DX §27)**
`__not_in_flash_func()` places only the outlined function body in a RAM section; it does *not* prevent inlining — for a `static` single-caller function the compiler may fold it into a FLASH-resident caller, silently destroying the very XIP immunity the flash-park handshake exists for. YC was in the same fragile state DX documented: `arm-none-eabi-nm` showed no `flash_park_core0` symbol at all — it survived only by being inlined into the RAM-resident IRQ chain, an arrangement §52 would have broken (the producer loop lives in flash). Fixed with the same macro as the peer `flash_write_locked()` on the Core 1 side. Verified post-build: `flash_park_core0` at 0x20000110 (RAM, out-of-line), `__flash_park_core0_veneer` in flash, `i2s_callback_func` 2 bytes in RAM. (File: `src/main.cpp`.)

**§54 pico_hw / Build: Per-Core FTZ, QMI Register Access, 1 MHz I2C, VREG Note, Stacks to Scratch (Cleanup bundle)**
* `pico_fpu_ftz_enable()` is now an inline helper in `pico_hw.h` and is called by **both** cores — FPSCR is per-core state; Core 1 has float paths (UI, MIDI pitch handling) and previously ran without flush-to-zero. The stale `RDX_Operator`-era comment was replaced with the YC engine's actual subnormal risk (reverb comb/allpass feedback, rotary crossover LP).
* QMI M0 timing now goes through `qmi_hw->m[0].timing` instead of the hardcoded `0x400d000c` pointer (the struct include already existed for the XIP registers).
* SH1106 I2C raised from 400 kHz to 1 MHz (Fast Mode) — halves the blocking display time on Core 1 (§30's throttled redraws benefit directly). Same panel family as DX/CP, which run this in the field.
* The 1.60 V VREG setting is documented as never-bisected includings a step-down soak procedure (ported verbatim from DX for sibling consistency).
* The ROSC/`srand()` block *stays* (YC-specific: the demo melody generator in `main.cpp` uses `rand()`; DX could drop it because nothing there calls `rand()`), as does `hardware_watchdog` on the link line (YC uses the §40 watchdog; DX/CP do not). `PICO_USE_SW_SPIN_LOCKS=1` stays per the §31 decision.
* Dead weight removed: `hardware_adc`/`hardware_spi`/`hardware_interp` unlinked (no API usage anywhere in `src/`), duplicate/stale includes in `pico_hw.h` (`adc`, `spi`, `interp`, `timer` — the latter listed twice) dropped.
* Both stacks raised to 4 KB and relocated into the dedicated scratch banks (`PICO_STACK_SIZE=0x1000`, `PICO_CORE1_STACK_SIZE=0x1000`): SCRATCH_X/Y are now 100 % used as designed, main-SRAM usage *dropped* from 56,096 to 54,412 bytes despite the larger audio pool. Flash: 124,264 B (0.74 % of 16 MB).

---

# MIDI Completion Pass (09/2026)

The eight "TODO" markers the port had carried since M6 - pitch bend unused, rotary mono, bulk dump deferred, model byte "verify from a real device dump, do NOT use unchecked" - closed in one pass. No reface YC was on the bench; the sources are the Yamaha reface CS/DX/CP/YC Data List (PO-B0, 04/2016) and the readable source of Yamaha's Soundmondo editor, which agree with each other. What is the firmware's own choice is named as such.

**§55 Model ID and Identity Reply from the Data List (was a placeholder)**
`YC_MODEL_ID` was `0x00` with the note to verify it, and because it was unverified every exclusive message was accepted whatever model byte it carried. The data list gives the reface YC **06H** (CS 03, CP 04, DX 05) and the identity reply `F0 7E 7F 06 02 43 00 41 54 06 00 00 00 7F F7`; Soundmondo's `reface-panel.js` keys its "reface YC" entry to modelId 0x06 and the identity pair `[0x54, 0x06]` at bytes 8/9 of a 15-byte reply. The old reply was 14 bytes and would have failed that length check. Now: model 0x06, `checkModelId = true` (a DX or CP message is ignored, as on the other two ports), the data list's reply with the version byte 0x03 (1.3, the current firmware, whose MIDI additions the SYSTEM block already serves - same reasoning as the DX port; the data list prints 00 for 1.0).

**§56 TG Bulk Dump and Dump Request (was "deliberately deferred", §15)**
The reason for deferring - the risk of an off-by-one in the block framing - went away with the shared reface layer (#167), which frames every block with byte count and checksum once for all three ports and has a host test on it. The YC now answers a Dump Request on the bulk header `0E 0F 00` with header, the 22-byte TG block at `30 00 00` (byte count 26) and footer `0F 0F 00`, exactly what Soundmondo sends on connect (`DUMP_ADDR_PART_HEADER_REFACE`); `30 00 00` alone gives the block. A received TG block is applied byte by byte through the ring like Parameter Changes; header and footer carry nothing. Every TG value is clamped to the data list's range on the way in (`kTgMax`): §39 had clamped the footage LUT index in the render loop after a SysEx footage of 127 read past a 7-entry table, and the other addresses (wave 0-4 into a 5-table array, vibrato depth into a 512-sample delay) had the same exposure without the fix. (File: `src/midi_reface.cpp`.)

**§57 Pitch Bend (was "engine does not use pitch bend yet")**
The implementation chart lists pitch bend as recognised; the YC has no range setting (the CS has), so ±2 semitones. The bend is a frequency factor `2^(semitones/12)` stored in `yc_engine_state_t::bend_ratio`; `yc_tonegen_set_bend()` re-derives the nine cached phase increments of every active voice from `base_freq` when a bend message arrives (16 × 9 multiplies at MIDI rate, `exp2f` once per message), note-on folds it in, the percussion oscillator follows it. Nothing in the per-sample path changed; at centre the factor is exactly 1.0f and the increments are bit-identical to before. The ring's `IPC_CMD_YC_PITCH_BEND` (reserved since M1) now carries it. (Files: `include/yc_engine/yc_core.h`, `yc_tonegen.h`, `yc_percussion.h`, `yc_engine.h`, `include/YC_Synth_Bridge.h`.)

**§58 CC1 / CC7 / CC11 and the Channel Mode Messages (were received and dropped)**
The chart recognises modulation, volume and expression without MIDI Control. Yamaha's "Rotary Speed Control - reface YC" article says what the wheel does on the original: it switches the rotary between FAST and SLOW; implemented as ≥ 64 FAST, < 64 SLOW (the threshold is ours). CC7 and CC11 are folded into the one master gain the render loop reads (`vol_gain = volume × CC7 × CC11`, each /127; 127 is a factor of exactly 1.0f, so an untouched controller changes nothing). The percussion now goes through that gain as well - it had bypassed the volume entirely, so a muted organ still clicked at full level. CC121 resets bend, expression and sustain but leaves the rotary alone (the data list's "modulation to 0" would park it at SLOW); CC120/126/127 act as all sound off per data list 3-2-1/3-2-6/3-2-7. `IPC_CMD_YC_MIDI_CTRL_MODE`, reserved for a flag that never travelled the ring, gave its number to `IPC_CMD_YC_MIDI_VOLUME`; `IPC_CMD_YC_EXPRESSION` is new. (Files: `src/midi_reface.cpp`, `include/ipc.h`, `include/yc_engine/yc_engine.h`.)

**§59 Stereo Rotary (was "mono on both channels", §32 deferred)**
§32 deferred true stereo because it seemed to need a stereo reverb (+18 KB, CPU) and could not be judged by the mono host test. Neither holds: the rotary is where the channels part - the left channel is the mono model as it was, the right channel hears the horn half a turn (π) and the drum a quarter turn (π/2) behind, as a mic pair around the cabinet would; two more sine-LUT reads and two multiply-adds per sample. The reverb stays mono: fed with the mid of both channels behind the rotary, the same tail mixed into each - a room behind a Leslie sounds like that, the swirl is in the direct sound. With the rotary OFF both channels are the old mono path bit for bit (pinned by the host test); with it on, the host WAV's left-channel RMS moved from 0.605883 to 0.604316 because the reverb now hears the mid rather than the left. The offsets are a first choice for the ear, not a measurement: on the bench the swirl should be audible in headphones and the STOP position may leave the image off-centre (a parked horn points somewhere). (Files: `include/yc_engine/yc_rotary.h`, `yc_reverb.h`, `yc_engine.h`.)

**§60 Host Tests: `yc_sysex` New, Engine Test Extended, One IPC Switch**
`tools/host_tests/yc_sysex` runs the real `midi_reface.cpp` on the shared layer and drains the ring through `include/yc_ipc_apply.h` - the same switch `YC_Instrument::render()` uses, moved out of the adapter for that purpose - so a MIDI path the test sees land in `yc_engine_state_t` is the path the firmware runs. 37 checks: identity bytes, the three-block dump with byte counts and checksums, an editor's dump reaching every parameter, range clamping, model byte and checksum rejection, Parameter Change/Request, and every controller of §57/§58. The engine test (`tools/host_tests/yc`) now writes a stereo WAV and pins: rotary FAST tells the channels apart, rotary OFF is mono bit for bit, ±2 semitones on the cached increments with an exact return to centre, expression 0 mutes voices and percussion. Both run in `run_all.sh` and therefore in CI. Firmware (pico2, `arm-none-eabi-size`): text 153,188 bytes, bss 50,240 - 2,296 bytes of flash for all of the above, no RAM.

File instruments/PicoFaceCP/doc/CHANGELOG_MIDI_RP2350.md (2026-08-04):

# Changelog: MIDI implementation + RP2350 optimization

Date: 2026-07-02 · Workflow: architecture/orchestration by Claude, code
generation by `glm-5.2:cloud`
Build verified: `cmake --build build -j4` -> FLASH 26.32 % / RAM 36.44 %
(release, no new warnings)

> **Historical document.** This log describes the state of the standalone
> PicoFaceCP repository. File names such as `main.cpp`, `pico_frontpanel.cpp`
> and the core0/core1 split no longer match the collection - the front panel is
> `CP_Ui` now and everything runs on core0. See
> [docs/ARCHITECTURE.md](../../../docs/ARCHITECTURE.md), section 4a.

## 0. Addendum after the live hardware test: a new SYSTEM screen

After the hardware test succeeded, two additional controls were added:

* **Pre-gain** (`effects/reface_cp_chain.h`): a new parameter `_preGain`
  (0..1, default 1.0), applied as the very first stage in
  `RefaceCpChain::process()` - **before** drive and the rest of the FX chain.
  Purpose: some effects (drive and wah in particular, at a high level) tend to
  overdrive; pre-gain lets the input level of the FX chain be lowered
  independently of the engine volume. The multiplication is skipped at unity
  (>= 0.9999), so there is no extra cost in the normal case. New: `FX_PRE_GAIN`
  in `include/ipc.h`, an `ipc_apply` case in `main.cpp`
  (`cp_fx.setPreGain(v)`), operable locally from the panel (no reface CP CC
  equivalent, hence no MIDI TX/RX binding).
* **MIDI channel display and setting**: `RefaceMidi` gained `getRxChannel()` /
  `setRxChannel()` (inline resp. in `src/midi_reface.cpp`). Since `RefaceMidi`
  and the front panel UI both ran on **core1**, access is direct and needs no
  IPC - unlike every audio-affecting parameter, which goes through the core0
  FIFO.
* **New screen `SCR_SYSTEM`** (`src/pico_frontpanel.cpp`, the last page before
  wrapping back to VOL/OCT): param A = MIDI receive channel (1-16 or "All" for
  omni, reset button -> All), param B = pre-gain in % (reset button -> 100 %).

## 1. New files

| File | Content |
|---|---|
| `include/midi_reface.h` | class `RefaceMidi`: the reface CP compatible MIDI protocol layer (declaration, SYSTEM and TG address enums) |
| `src/midi_reface.cpp` | implementation: channel filter, CC map, channel mode messages, SysEx (identity, parameter change/request, bulk dump/request including checksum), active sensing (TX 200 ms / RX timeout 350 ms), master transpose/tune, soft pedal velocity, panel CC TX |
| `doc/MIDI_IMPLEMENTATION.md` | separate MIDI document (equivalent to Data List pages 11-14) |
| `doc/CHANGELOG_MIDI_RP2350.md` | this document |

## 2. Changed files

### `include/midi_input_usb.h` / `src/midi_input_usb.cpp` (transport rewrite)
* The parser moved from fixed 3-byte reads to **USB MIDI 4-byte event packets**
  (`tud_midi_packet_read`, CIN dispatch) - before that, SysEx messages and pitch
  bend were lost or threw the stream out of step.
* New callbacks: pitch bend (14 bit), realtime byte (0xF8-0xFF), complete SysEx
  message (64-byte assembler, overflow-safe), activity (for the active sensing
  supervision).

### `include/ipc.h`
* New: `IPC_CMD_PITCH_BEND` (0x09), `FX_EXPRESSION`, `ipc_send_pitch_bend()`.

### `effects/reface_cp_chain.h`
* New: `setExpression()` / `getExpression()` (CC 11), multiplied with the master
  volume in the process loop (one extra multiplication per sample, arranged for
  inlining).

### `include/mdaEPiano.h` / `src/mdaEPiano.cpp` (engine)
* **Pitch bend** (±2 semitones): `VOICE.dbase` stores the unbent sample
  increment; `setPitchBend(0..16383)` scales the `delta` of all active voices by
  `exp2f(semis/12)`; `noteOn` starts new voices with the current bend factor.

### `src/main.cpp` (integration, core assignment unchanged)
* Global instance `RefaceMidi refaceMidi` (core1).
* The MIDI callbacks forward to `refaceMidi.on*()`; four new callbacks (pitch
  bend, realtime, SysEx, activity) registered; `refaceMidi.init(&ep, &cp_fx)` in
  `core1_main`.
* Octave transposition (`apply_octave`) moved into `RefaceMidi::transposeNote()`
  (combined with the SysEx master transpose); the CC 1 special case moved into
  the protocol layer.
* `ui_poll_usb()` additionally calls `refaceMidi.tick()` (active sensing).
* `ipc_apply` (core0, audio IRQ): new cases `IPC_CMD_PITCH_BEND` ->
  `ep.setPitchBend()` and `FX_EXPRESSION` -> `cp_fx.setExpression()`.

### `src/pico_frontpanel.cpp`
* Panel changes now additionally send the reface CC (wrappers
  `fp_send_fx_param/mode/instrument` = IPC + `RefaceMidi::tx*`; only while MIDI
  control is on).

### `CMakeLists.txt`
* `src/midi_reface.cpp` added to the target.

## 3. RP2350 optimizations (task 2)

Analysis finding: the most critical path is `mdaEPiano::noteOn()`, because it
runs through `ipc_apply` **inside the audio DMA IRQ on core0**. There - and in
`update()` / `getVolume()` - the engine computed in **double** precision. The
Cortex-M33 only has a single-precision FPU, so doubles go through the slower
software/DCP emulation.

* `exp` -> `expf` (8 sites, among them the decay/release calculation per note
  on/off, the LFO rate and the treble filter), `pow` -> `powf` (velocity curve),
  `sqrt` -> `sqrtf`, `fabs` -> `fabsf` plus float literals; the `(double)note`
  casts removed. Numerically equivalent within float range.
* Side finding fixed: `getVolume()` cast the `sqrt` result to `uint8_t`
  needlessly inside a float assignment.
* Existing measures verified and kept: FX hot path in RAM (`CP_HOT` /
  `__not_in_flash_func`), int16 delay lines, bare-metal dual core with FIFO IPC,
  release build (`-O3`, `-ffast-math`), samples flash-resident (XIP).
* The new MIDI layer runs entirely on **core1**; the audio IRQ only ever sees
  the existing 32-bit FIFO packets, so there is no additional latency or jitter
  in the audio path. The SysEx buffer is static (64 B), there is no heap
  allocation and no printf in the MIDI path.

## 4. Behaviour and compatibility

* Existing functions (UI, presets, instrument selection, FX operation)
  unchanged.
* Newly controllable from outside: all reface CP CCs, SysEx parameters, bulk
  dump/restore, identity reply, active sensing, pitch bend, expression, soft
  pedal, master transpose/tune, receive channel (including omni on/off via
  CC 124/125).
* Deviations from the original are documented in
  `doc/MIDI_IMPLEMENTATION.md` §8.

## 5. Open points and recommendations

* Hardware test: enumeration, CC RX/TX with a DAW, bulk dump round trip (e.g.
  MIDI-OX or SysEx Librarian).
* Optional: persist the SYSTEM block in flash (RAM-only at the time, defaults at
  boot).
* Optional: show the `_sys` settings (RX channel, MIDI control) in the OLED
  SYSTEM menu.

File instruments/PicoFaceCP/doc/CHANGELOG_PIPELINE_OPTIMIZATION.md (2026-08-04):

# Changelog: RP2350 pipeline optimization and bug fixes

**Date:** 2026-07-08  
**Workflow:** architecture/orchestration by Claude, code generation by
`kimi-k2.7-code:cloud` via the Ollama API

> **Historical document.** This log describes the state of the standalone
> PicoFaceCP repository. File names such as `main.cpp` and
> `pico_frontpanel.cpp` and the core0/core1 split no longer match the
> collection; see [docs/ARCHITECTURE.md](../../../docs/ARCHITECTURE.md),
> section 4a.

---

## 1. Summary

This round of optimization concentrates on two critical areas: correcting the
long-standing L/R channel swap in the stereo output, and targeted performance
and memory optimizations in the DSP pipeline. In addition, a safety problem in
the audio IRQ was removed by getting rid of a variable length array (VLA). All
changes were built and verified successfully; there are no new compiler
warnings.

---

## 2. Bug fixes

| ID | Priority | File(s) | Description |
|---|---|---|---|
| B1 | critical | `src/main.cpp`, `i2s_callback_func` | L/R channel swap fixed: `mdaEPiano::process(int16_t* outputs_r, int16_t* outputs_l)` expects the **right** channel as its first parameter. The call `ep.process(&l[0], &r[0])` therefore filled `l[]` with the right channel and `r[]` with the left. Fixed to `ep.process(&r[0], &l[0])`, so that I2S left is engine left. Affected: stereo width, tremolo pan, reverb L/R, chorus stereo. |
| B2 | normal | `src/pico_frontpanel.cpp` | `pct()` clamped values at 99 instead of 100. Corrected to `if(x>100)x=100`. |

---

## 3. Performance optimizations

| ID | Weight | File(s) | Description | Expected effect |
|---|---|---|---|---|
| P1 | high | `effects/dsp_lut.h`, `effects/reface_cp_fx.h` | New global `g_sinLUT()` with 512 entries (lazy init). Six `sinf()` calls in tremolo (1), chorus (2), phaser (2) and delay wobble (1) replaced by LUT interpolation. | `sinf` is roughly 50-100 cycles, LUT interpolation roughly 5-10 on the Cortex-M33. Cost: +2048 bytes of RAM for the table. |
| P2 | medium | `effects/dsp_reverb.h` | The reverb modulo `idx=(idx+1)%len` (an integer division, 12x per sample) replaced by `if(++idx>=len)idx=0`. | About 529,000 divisions per second eliminated. |
| P3 | medium | `lib/audio/include/audio_subsystem.h` | Audio buffer size raised from 16 to 32 samples. | IRQ rate halved from 2756/s to 1378/s, less context switch overhead. Latency stays below 1 ms. |
| P4 | safety | `src/main.cpp` | VLA removed from the audio IRQ: `int16_t l[buffer->max_sample_count]` replaced by `int16_t l[SAMPLES_PER_BUFFER]` (fixed size). | No variable length arrays in interrupt context; more predictable and safer. |
| P5 | low | `src/pico_hw.cpp` | OLED I2C clock raised from 400 kHz to 1 MHz. | Faster display refresh for the front panel UI. |

---

## 4. Memory optimizations

| ID | File(s) | Description | Saving |
|---|---|---|---|
| C2 | `effects/reface_cp_fx.h` | Delay buffer `kBuf` adjusted from 24001 to 22080 samples. The old value was sized for 48 kHz, but the system runs at 44.1 kHz. | 7680 bytes of BSS |

---

## 5. Build verification

- **FLASH:** `text` 4,428,008 bytes (about 26.4 % of 16 MB)
- **RAM:** `bss` 173,568 bytes (about 33.8 % of 512 KB)  
  - before: 179,200 bytes (35.0 %)
  - difference: -7684 bytes
- **Warnings:** no new warnings, clean build

---

## 6. Addendum: volume bug fix

**Date:** 2026-07-08 (same session)

### B3 [CRITICAL BUG FIX]: overall volume too low

| File | Change | Explanation |
|---|---|---|
| `src/main.cpp` | `ep.setVolume(64)` -> `ep.setVolume(100)` | The engine volume parameter `volume = 0.00002 x value²` was set to 64 (-> 0.08192). The constructor default in `mdaEPiano.cpp` is `volume = 0.2f`, which corresponds to `setVolume(100)`. main.cpp overwrote it with 64, i.e. 2.44x quieter. |
| `src/main.cpp` | `cp_fx.setVolume(0.9f)` -> `cp_fx.setVolume(1.0f)` | FX chain master volume default from 90 % to 100 % (unity). |

**Signal level before/after the fix** (single note, velocity 100, FX volume
100 %):
- before (setVolume 64): peak about 4.1 % full scale = -27.8 dB
- after (setVolume 100): peak about 10 % full scale = -20.0 dB (+7.8 dB)
- four-note chord: 40 % FS = -8 dB (healthy, no clipping risk)

---

## Backport from PicoFaceDX/PicoFaceRD - audio pipeline, encoders, producer in thread context (2026-08-03)

### Why

The sibling projects PicoFaceDX and PicoFaceRD share the vendored `lib/audio`
and `lib/encoder` as well as `pico_hw`/`project_config` with PicoFaceCP. Every
bug found there was still open here. The reference is PicoFaceDX commit
`668b9b8` including its §27 addendum; the bug descriptions there apply here word
for word.

### A) Tuning: the instrument sounded 14.5 cents sharp

`update_pio_frequency()` discarded the fractional part of the PIO clock divider.
At 444 MHz / 44,100 Hz / S32 stereo the exact divider is **78.65625**, but
**78** was used:

```
raw divider (1/256): 444000000 * 2 / 44100 = 20136  ->  int 78, frac 168
old (integer):       444e6 / 78       / 128 = 44,471.15 Hz = +14.51 cents
new (fractional):    444e6 / 78.65625 / 128 = 44,100.12 Hz = +0.005 cents
```

Now `pio_sm_set_clkdiv_int_frac()`. The RP2040 fallback branch (402 MHz) was at
+5.26 cents and is now at +0.028 cents.

### B) The silence buffer read past its allocation

The underrun replacement buffer was allocated as
`PICO_AUDIO_I2S_BUFFER_SAMPLE_LENGTH * 4` = 2,304 B, but at S32 stereo the DMA
reads `sample_count * 2` 32-bit words = 4,608 B. On **every** underrun, 2,304 B
of heap garbage went to the DAC, for 13.06 ms. Now stride-correct and shrunk to
one producer block:

| | allocation | DMA reads | silence per underrun |
|---|---|---|---|
| before (576) | 2,304 B | 4,608 B -> **2,304 B out of bounds** | 13.06 ms |
| now (32) | 256 B | 256 B | **0.73 ms** |

`PICO_AUDIO_I2S_SILENCE_BUFFER_SAMPLE_LENGTH` is deliberately **32** (DX and RD
use 64) and has to stay in sync with `SAMPLES_PER_BUFFER`. `SAMPLES_PER_BUFFER`
must not move to 64: `mdaEPiano.h:45` derives `I2S_BUFFER_WORDS` from it, the
hard loop bound of the render.

### C) Further `lib/audio` bugs

A broken `#ifdef` guard (it checked the same name as the surrounding `#ifndef`);
`wrap_consumer_take` / `wrap_producer_give` compared the input channel count
with itself and could run off the end without a `return` in a release build;
`playing_buffer` was only cleared under `#ifndef NDEBUG` (a buffer leak in
release); `audio_i2s_set_enabled(false)` did not abort the running DMA;
`audio_i2s_end()` had an unsafe teardown order; `printf()` in the DMA IRQ. New:
`g_i2s_underrun_count` and `audio_i2s_consume_txstall()`.

### D) `lib/encoder`

`clocks_per_time` was computed in the constructor of global objects and
therefore captured the 150 MHz boot clock instead of 444 MHz - dormant in CP,
which only uses `delta()`, but taken over for parity. Two overflow guards relied
on signed wraparound (UB at `-O2`). The `PushButton` debounce compared an
absolute millisecond deadline and would have blocked the button for weeks after
the 49.7-day overflow - **that is the only change with an immediately observable
effect**. `lib/encoder/src/rotary_encoder.cpp` removed (not in the CMakeLists,
references three headers that do not exist).

### E) `pico_hw` and build

FPU flush-to-zero: **new for CP**, there was none at all before. The feedback
states of the FX chain (reverb/delay/phaser/chorus) had no denormal protection;
`mdaEPiano` protects itself only partially. It is now set on **both** cores
(FPSCR is per-core state). Also: typed `qmi_hw->m[0].timing` access, dead
ROSC/`srand()` block removed, 1.60 V documented as not bisected, `analogRead()`
removed from `arduino_compat.h` (no callers, and the only consumer of
`hardware/adc.h`).

CMake: `hardware_adc/spi/interp/watchdog` unlinked - the "interpolation" in the
sample engine is plain integer arithmetic, not the interp peripheral.
`PICO_USE_SW_SPIN_LOCKS` removed (it is the SDK default on RP2350); the comment
records that the flag **renumbers** the reserved spinlock IDs and that IDs 6/7
in hardware mode would collide with the ones hardcoded in
`lib/audio/include/audio.h:29,34`. Both stacks moved to 4 KB in the scratch
banks.

### F) Producer out of the DMA IRQ and into thread context

`i2s_callback_func()` used to render a complete block inside the interrupt. Now:
empty callback, rendering and IPC drain in the `main()` loop of core0,
`AUDIO_BUFFER_COUNT 6`.

Two points that are **mandatory** here and were missed in DX at first (see §27
there):

1. `__not_in_flash_func` is a pure section attribute **without** `__noinline`
   (`pico/platform/sections.h:268` vs. `:284`). `flash_park_core0()` was
   RAM-resident only as a side effect of being inlined into the RAM-resident IRQ
   handler. With the producer in `main()` (flash), the spin loop would have
   landed in XIP - exactly where core1 is erasing and rewriting
   `qmi_hw->m[0].timing` at the same time. Now `__no_inline_not_in_flash_func`,
   like `flash_write_locked()` on the core1 side.
2. The same applies to the **render path**: `cp_process_block_i16()` is `inline`
   without a symbol of its own and was likewise in RAM only by accident. Hence
   the new `render_one_block()` as `__no_inline_not_in_flash_func`. With 4.4 MB
   of sample data in flash, rendering from XIP would be particularly expensive.

Fixed in passing: `l[i] << 16` is a signed overflow for `l[i] == -32768` (UB at
`-O2`); now cast through `(uint16_t)`, same bit pattern, defined behaviour.

With a full pool core0 waits with `__wfe()` instead of spinning hot - both wake
sources already SEV, the event register is latched, so there is no lost wakeup.
A permanent spin would be a real thermal change at 1.60 V and 444 MHz.

### G) Output latency

`audio_i2s_connect()` would have used the hardwired **2 x 256** consumer frames,
which dominate the latency because the consumer take pulls all prepared producer
buffers into one 256-frame buffer and the DMA plays that as a single transfer.
Instead: `audio_i2s_connect_extra(pool, false, 2, 64, NULL)`. 64 is an exact
multiple of `SAMPLES_PER_BUFFER` (32), so producer buffers are never split. The
price is a higher DMA IRQ rate, which is affordable now that the handler no
longer renders.

### Deliberately NOT taken over

- **Master volume as a menu entry** (DX §26 E): CP already has a volume on the
  home screen (`"Vol %2d"`, `RefaceCpChain::getVolume()`, persisted in the
  settings). A second control would be duplication. The author's decision.
- **`std::__throw_*` panic stubs**: measurably zero gain in CP - `nm` shows no
  unwinder or demangler symbols, `.ARM.exidx` is already 8 B, CP uses no
  libstdc++ containers, and the build is already
  `-fno-exceptions -fno-unwind-tables -fno-rtti`.
- The 480 MHz branch from PicoFaceRD. CP stays at 444 MHz.

### Build verification

Zero warnings. **Flash:** 4,424,968 B / 26.37 % (before 4,423,912 B). **RAM:**
187,868 B / 35.83 % (before 188,792 B). SCRATCH_X/Y 4 KB each / 100 % -
intentional, those are the stacks.

Placement audit (the acceptance criterion for F):

```
10001f04 000006c8 T main                        <- flash, small: nothing large inlined into it
10011b98 00000008 t __flash_park_core0_veneer   <- flash (long-call veneer)
10011bb8 00000008 t __render_one_block_veneer   <- flash (long-call veneer)
20000110 00000040 t flash_park_core0            <- RAM
20000150 00001424 W RefaceCpChain::process      <- RAM
20001574 00000184 t render_one_block            <- RAM
200016f8 00000002 T i2s_callback_func           <- RAM (empty)
200027bc 00000094 T lrintf                      <- RAM
```

### Still open - only checkable on hardware

1. Tuning against a reference instrument (it should be A=440 now instead of
   14.5 cents sharp).
2. Underruns at full polyphony with the producer in thread context. CP has no
   CPU load screen like DX; if it is suspected, `g_i2s_underrun_count` would
   have to be surfaced.
3. Noticeable input/output latency after the move to 64-frame consumer buffers.
4. FPU FTZ is new for CP: watch for changed decay tails or CPU load.

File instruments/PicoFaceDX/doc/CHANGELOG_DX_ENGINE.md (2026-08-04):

# CHANGELOG_DX_ENGINE.md

**Date:** 2026-07-05
**Workflow:** architecture/orchestration by Claude, code generation by glm-5.2:cloud
**Context:** porting the FM synth engine of an ESP32/Arduino project ("RDX", a Yamaha reface DX emulator) into the existing RP2350 project PicoFaceDX (a copy of PicoFaceCP).

> **Historical document.** This is the engineering log of the DX port, written
> in the standalone PicoFaceDX repository. Paths such as `src/main.cpp`,
> `pico_frontpanel.cpp` and `tools/refacedx/` no longer exist in the collection,
> and the core0/core1 split described here is gone - everything runs on core0
> now. What the instrument looks like today is in
> [docs/ARCHITECTURE.md](../../../docs/ARCHITECTURE.md), section 4a.

---

## 1. New files - engine (header-only, `include/dx_engine/`)

Ported 1:1 from the ESP32 project with clean-up (see section 4).

| File | Content |
|---|---|
| `RDX_Types.h` | patch data structures |
| `RDX_State.h` | singleton state |
| `RDX_VoiceAlloc.h` | voice allocator |
| `RDX_Constants.h` | LUTs and constants |
| `misc.h` | math utilities |
| `RDX_Envelope.h` | amplitude envelope |
| `RDX_PEG.h` | pitch envelope |
| `RDX_LFO.h` | LFO |
| `RDX_Operator.h` | FM operator/oscillator |
| `RDX_Voice.h` | 4-operator voice with 12 algorithms |
| `RDX_Synth.h` | synth host with `renderAudioBlock()` / `process()` / `noteOn()` / `noteOff()` |
| `dx_engine_config.h` | **new**, not taken from the ESP32 project - the minimal engine configuration |

**`dx_engine_config.h` - configuration values:**

- `SAMPLE_RATE = 44100`
- `DMA_BUFFER_LEN = 64`
- `MAX_VOICES = 8`
- `MAX_VOICES_PER_NOTE = 2`
- `TIMING_CORRECTION = 1.0f`

> It replaces the ESP32 `config.h`, which contained GPIO, display and SD
> definitions.

---

## 2. New files - integration (top-level `include/` and `src/`)

| File | Content |
|---|---|
| `DX_Synth_Bridge.h` / `DX_Synth_Bridge.cpp` | wrapper class: translates `fill_buffer(float* buffer, int length)` [interleaved stereo, length = frames] into blocks of 64 frames through `RDX_Synth::renderAudioBlock()` |
| `DX_Controller.h` / `DX_Controller.cpp` | control class: MIDI note forwarding, encoder handling, menu page logic |
| `DX_GUI.h` / `DX_GUI.cpp` | GUI: algorithm diagrams and screen drawing |

### 2.1 DX_Synth_Bridge

- `fill_buffer(float* buffer, int length)` - interleaved stereo, `length` =
  frames
- block-wise processing through `RDX_Synth::renderAudioBlock()` in blocks of 64
  frames
- fixed scratch buffers, no heap allocation
- `synth_.updateCache()` is called once per invocation
- `noteOn()` / `noteOff()` / `patch()` as pass-through and access

### 2.2 DX_Controller

- `onMidiNoteOn()` / `onMidiNoteOff()` - forward to `DX_Synth_Bridge`
- `onEncoder1()` - changes the menu page (enum `DxPage`: `OP1`, `OP2`, `OP3`,
  `OP4`, `LFO`, `ALGO`, with wraparound)
- `onEncoder2()` / `onEncoder3()` - change two values per page:

| Page | Encoder 2 | Encoder 3 |
|---|---|---|
| OP1-OP4 | `freqCoarse` (0-31) of that operator | `outLevel` (0-127) of that operator |
| LFO | `lfoSpeed` (0-127) | `lfoPMD` (0-127) |
| ALGO | `algorithm` (0-11) | `feedback` of operator 1 (0-127) |

### 2.3 DX_GUI

- `drawAlgo()` - draws the 12 FM algorithm diagrams (operators as boxes and
  circles with connecting lines)
- a 1:1 geometry port from the ESP32 project's own implementation (the
  `UI_Display` class) onto direct u8g2 calls (thin wrapper functions for call
  compatibility)
- `dxDrawScreen()` - shows the header (page name) plus the algorithm diagram (on
  the ALGO page) or placeholder text (other pages; real value display came
  later)

---

## 3. Changed files

| File | Change |
|---|---|
| `CMakeLists.txt` | three new `.cpp` files added to the `add_executable()` target: `DX_Synth_Bridge.cpp`, `DX_Controller.cpp`, `DX_GUI.cpp` |

---

## 4. Clean-up (removed during the port)

- `#include <Arduino.h>`, `<esp_log.h>`, `<esp_heap_caps.h>` - removed
  everywhere
- `ESP_LOGI` / `ESP_LOGD` calls removed (pure diagnostic code)
- the `logMemoryStats()` function (ESP heap diagnostics) - removed entirely
- `vTaskDelay(1)` in the audio hot path (`RDX_Voice::step()`, the
  invalid-algorithm fallback) removed - it would have been catastrophic in the
  audio IRQ
- `IRAM_ATTR` / `DRAM_ATTR` (ESP32 memory placement):
  - replaced by the `CP_HOT()` macro already present in the project
    (`effects/cp_hot.h`, RAM placement via `__not_in_flash_func` on the RP2350,
    a no-op on the host build)
  - or removed without replacement for constant data tables (they stay in
    flash/rodata, in line with the existing practice for the mdaEPiano sample
    data)
- `RDX_GUI.h` and the PresetManager coupling removed from `RDX_Synth.h`
  (Arduino filesystem/LittleFS based, not part of the sound generation proper)
- `applyBankProgram()` loads the hardcoded `DigiChordPatch()` for now (a TODO
  comment in the code marks the later multi-patch persistence)

---

## 5. Bug fixes (found in the original ESP32 code, corrected during the port)

Defects unrelated to the ESP32 that were already present in the original source:

- **The identifier `VOICES`:** used in nine places in the original project
  (`RDX_Synth.h` x8, `RDX_VoiceAlloc.h` x1) but defined nowhere - only
  `MAX_VOICES` existed, in `config.h`. It would have been a compile error.
  Unified to `MAX_VOICES`.
- **Missing `TWO_PI` macro:** implicitly available from `wiring.h` in the
  Arduino world, but not in standard C++. Added as a constant of its own
  (`6.283185307179586f`) in `RDX_Constants.h`.
- **Missing explicit includes:** the code relied on transitive inclusion through
  `Arduino.h`. The following headers were added in several places: `<cstring>`,
  `<cmath>`, `<initializer_list>`.

---

## 6. A known problem that was not fixed

**`misc.h`, function `fast_floorf()`:**

```cpp
int i = (int)x - (int)(i > x);
```

- `i` is read before it is initialized (undefined behaviour)
- confirmed by the compiler as a warning (`-Wuninitialized`)
- already present in the ESP32 original
- deliberately not fixed, since it is outside the scope of "remove the ESP32
  dependencies"
- **Recommendation:** fix it in a separate task

---

## 7. Architecture note (IMPORTANT, not yet solved)

- Like the existing `mdaEPiano` engine, `DX_Synth_Bridge` is **not designed for
  cross-core access** (callable from one execution context only; the intended
  one is the core0 audio DMA IRQ)
- `DX_Controller` (encoders and MIDI) would naturally run on core1 - direct
  calls across the core boundary are **not safe**
- The integration into `main.cpp` (instantiation, the actual IPC binding through
  new `IPC_CMD_DX_*` commands analogous to `IPC_CMD_NOTE_ON`, hooking into
  `pico_frontpanel.cpp`) has **not happened yet**
- The new codebase compiles and links, but is not reachable or callable at
  runtime

---

## 8. Build verification

- **Build command:** `cmake -G Ninja ..` plus `ninja`
- **Toolchain:** `arm-none-eabi-gcc 15.2.1`
- **Board:** `sparkfun_promicro_rp2350`
- **Platform:** `PICO_PLATFORM=rp2350-arm-s`
- **Result:** 455/455 targets successful, `main.elf` linked

**Memory usage:**

| Resource | Used | Total | Share | Before (CP only) |
|---|---|---|---|---|
| FLASH | 4,423,320 B | 16 MB | 26.37 % | 26.32 % |
| RAM | 193,872 B | 512 KB | 36.98 % | 36.44 % |

**Compiler warnings:**

All compiler warnings come unchanged from the ported ESP32 original:

| Warning | Count | Source |
|---|---|---|
| `misleading-indentation` | 3 | ESP32 original code |
| `reorder` | 1 | the `RDX_Operator` constructor |
| `sign-compare` | 1 | `renderAudioBlock` |
| `uninitialized` | 1 | `fast_floorf` |

> The newly written files `DX_Synth_Bridge.cpp` / `DX_Controller.cpp` /
> `DX_GUI.cpp` produce **no warnings of their own**.

---

## 9. Open points and recommendations

1. **Dual-core IPC binding in `main.cpp`** (see the architecture note in section
   7) - the key piece for actual usability.
2. Fix the **`fast_floorf()` uninitialized read**.
3. **The DX's own effect chain** (distortion/chorus/flanger/phaser/delay/reverb/
   touch wah from the ESP32 project, present there as `fx_*.h`) is **not
   ported** - the DX voice currently has no effect processing. Short term the
   existing `RefaceCpChain` (already float-based) could be shared; long term the
   DX effects should be ported.
4. **The value display of `dxDrawScreen()`** for the OP1-4 and LFO pages is
   placeholder text - real numbers and gauges will follow in a later step.
5. **Patch persistence** (SysEx bulk dump, flash storage for DX patches) is not
   implemented; only one hardcoded init voice (`DigiChordPatch`) is available.
6. **`MAX_VOICES=8`** (taken from the ESP32-S3 model) has not been tested
   against the actual CPU load on the RP2350 (444 MHz overclock).

---

## 10. Addendum: dual-core IPC binding (2026-07-05, continued)

The missing IPC binding described in section 7 was implemented in this
continuation.

### Changed files and implementation details

- **`include/ipc.h`**:
  - three new commands added: `IPC_CMD_DX_NOTE_ON=0x0B`,
    `IPC_CMD_DX_NOTE_OFF=0x0C`, `IPC_CMD_DX_PARAM=0x0D`.
  - a new enum `DxParamId` with 12 values: two per operator
    (frequency and level) for OP1-4, plus LFO speed, LFO PMD, algorithm and OP1
    feedback.
  - three new send helpers: `ipc_send_dx_note_on`, `ipc_send_dx_note_off`,
    `ipc_send_dx_param`.
- **`src/midi_reface.cpp`**:
  - `RefaceMidi::onNoteOn` and `RefaceMidi::onNoteOff` now additionally send to
    the DX engine, with the same channel-filtered and transposed note number.
    Incoming MIDI notes therefore sound on BOTH engines (CP and DX)
    simultaneously.
- **`include/DX_Controller.h` / `src/DX_Controller.cpp`**:
  - the methods `onMidiNoteOn` and `onMidiNoteOff` were removed. They had become
    redundant, since MIDI now goes through `RefaceMidi`, which already brings
    the channel filter, transpose and soft pedal handling.
  - `onEncoder2` and `onEncoder3` no longer write into the patch directly (the
    cross-core defect documented in section 7). They still read the current
    value (an accepted cross-core read, as elsewhere in this project) and send
    the new values through `ipc_send_dx_param()`.
- **`include/DX_Synth_Bridge.h`**:
  - comment made precise: `noteOn()`, `noteOff()` and `fill_buffer()` may only
    be called from core0. `patch()` may be read (not written) from core1.
- **`src/main.cpp`**:
  - new global instance `DX_Synth_Bridge dxBridge;` (owned by core0, like `ep`
    and `cp_fx`).
  - `dxBridge.init()` called from `main()`.
  - `ipc_apply()` has three new cases: note on/off is passed straight through,
    and a parameter set writes the matching patch field.
  - `i2s_callback_func()` now additionally renders a `dxBuf` scratch buffer
    (float, interleaved stereo) via `dxBridge.fill_buffer()` and mixes it
    ADDITIVELY (with int16 clamping) into the existing CP output. With a silent
    DX engine (no active voices) the result is exactly identical to the previous
    pure CP signal.

### Build verification

- Build verified again: `ninja` -> 8/8 successful (only the changed and new
  targets rebuilt).
- FLASH: 4,485,528 B / 16 MB = 26.74 % (before 26.37 %).
- RAM: 241,040 B / 512 KB = 45.97 % (before 36.98 %). A clear jump, because
  `dxBridge` is now a real global instance the linker can no longer remove: 8
  voices x 4 operators plus the envelope and LFO state of all voices are now
  permanently allocated static RAM. Before that, the memory for the (never
  instantiated) engine may have been dropped.
- No new compiler warnings.

### Still open (as of before section 11)

- The encoder hardware (`encSel`/`encA`/`encB` in `main.cpp`, processed in
  `pico_frontpanel.cpp`) does NOT yet call `DX_Controller::onEncoder1/2/3`. The
  DX menu pages (OP1-4/LFO/ALGO) are not reachable from the physical encoders
  yet. That is a separate, still pending step (hooking into
  `pico_frontpanel.cpp`, for example as a new screen or a mode of its own).
- MIDI notes, on the other hand, already produce real DX sound (through the
  loaded default patch `DigiChordPatch`). That can be tested simply by playing
  from a MIDI keyboard or DAW.

---

## 11. Addendum: encoder binding in pico_frontpanel.cpp (2026-07-05, continued)

- **Goal:** make the DX menu pages (OP1-4/LFO/ALGO) actually reachable from the
  physical encoders (`encSel`/`encA`/`encB`).
- **New global instance:** `DX_Controller dxController(dxBridge);` in
  `src/main.cpp` (a core1 object that references the core0 bridge only for IPC
  sends and reads, see section 10).
- **`src/pico_frontpanel.cpp`:** a new function `openDxSynth()` implemented
  after the model of the existing `showAbout()` / `openSystem()` leaf screens.
  It has a small render/event loop of its own, draws via `dxDrawScreen()`, reads
  `encSel->delta()` / `encA->delta()` / `encB->delta()` and calls
  `dxController.onEncoder1/2/3()`. It exits on a press of `btSel`, returning to
  the main menu.
- **`openMainMenu()` extended:** the menu list gets a third entry, "DX Synth"
  (between "System" and "<< BACK"). The signature was extended by the `encA` and
  `encB` parameters (which were not passed through before), and the single call
  site was adjusted.
- **Reachability:** the DX synth page is now reachable through a long press of
  the selector encoder -> menu entry "DX Synth". There the selector cycles the 6
  pages (OP1-4/LFO/ALGO) and encoders A and B change the two values of the
  current page. A short press of the selector leaves the page for the main menu.
- **IMPORTANT BUG FIX (nothing to do with the ESP32, discovered by the first
  real build attempt with this change):** `include/mdaEPiano.h` defines
  `#define SUSTAIN 128` - a preprocessor macro, a purely textual replacement
  with no knowledge of C++ scope. The DX engine files `RDX_Envelope.h` and
  `RDX_PEG.h` each had their own `enum class Stage { ..., SUSTAIN, ... }` with
  an enum value `SUSTAIN`. As long as no translation unit included both headers
  in that order (first `mdaEPiano.h`, then `dx_engine`), this went unnoticed.
  `pico_frontpanel.cpp` already includes `mdaEPiano.h` through
  `pico_frontpanel.h` / `pico_userinterface.h`, and now additionally `DX_GUI.h`
  for the new DX page. The macro textually replaced `Stage::SUSTAIN` with
  `Stage::128`, which produced a compile error with a long cascade of follow-up
  errors.
  - **Fix:** both enum values in `RDX_Envelope.h` and `RDX_PEG.h` were renamed
    from `SUSTAIN` to `SUSTAIN_STAGE` (7 sites in total across both files: one
    enum declaration each plus several `Stage::SUSTAIN` uses in `enterStage()`,
    `advanceStage()` and `stageTarget()`). `mdaEPiano.h` itself was not touched
    (existing, working CP code).
- **Build verification after the fix:** `ninja` -> 6/6 successful. FLASH
  4,489,648 B / 16 MB = 26.76 % (before 26.74 %). RAM 241,048 B / 512 KB =
  45.98 % (before 45.97 %, the small increase being the `dxController`
  instance). No new compiler warnings - all remaining ones are unchanged and
  inherited from the ESP32 original (misleading-indentation, reorder,
  sign-compare, and the known fast_floorf uninitialized problem).
- **STATUS NOW:** the DX engine is fully reachable end to end - both by MIDI
  note (it sounds immediately, mixed additively with CP) and by hardware encoder
  (menu page navigation and parameter editing through the main menu entry "DX
  Synth").

---

## 12. Addendum: complete removal of the reface CP engine (2026-07-06)

**Goal (a correction of the original task):** the user clarified that PicoFaceDX
is to become **exclusively** a reface DX clone; the reface CP only served as a
template and skeleton for the hardware binding (pin, display and encoder init,
USB MIDI transport, virtual EEPROM, generic OLED dialogs). The additive
two-engine architecture from sections 10 and 11 was therefore rolled back.

### Deleted (24 files)

- the mdaEPiano engine plus instrument sample data (14 files, about 8 MB):
  `src/mdaEPiano.cpp`, `include/mdaEPiano.h`, `include/mdaEPianoData.h`,
  `include/mdaEPianoInstruments.h`, `include/{CP,Clv,Pno,Rd_II,Wr}Data.h`,
  `include/{CP,Clv,Pno,Rd_II,Wr}Keygroups.h`.
- the reface CP effect chain plus the generic DSP headers orphaned by it (7
  files): `effects/reface_cp_chain.h`, `reface_cp_fx.h`, `wahwah.h`,
  `cp_audio.h`, `dsp_fastmath.h`, `dsp_lut.h`, `dsp_reverb.h`.
- `src/pico_program_select.cpp` (the mdaEPiano program selection screen).
- the CP-only host test harness (7 files): `test/test.cpp`, `build.sh`,
  `mdaepiano_test`, `cp_test.cpp`, `build_cp.sh`, `cp_test`, `test/README.md`
  (`test/veeprom_test.*` stays - pure, engine-independent storage tests).
- `include/arduino_compat.h` (no consumers left after the mdaEPiano removal,
  verified by grep).

### Rewritten (DX-native instead of CP-native)

- **`include/ipc.h`:** all CP commands and enums (`FxParam`, `FxMode`,
  `IPC_CMD_NOTE_ON/OFF/CC/FX_PARAM/FX_MODE/VOICE_PARAM/PROGRAM/INSTRUMENT/PITCH_BEND`)
  removed. Four new DX commands added: `IPC_CMD_DX_PITCH_BEND`, `IPC_CMD_DX_CC`,
  `IPC_CMD_DX_RAW_WRITE` (a single patch byte from a SysEx parameter change,
  since the 12 curated `DxParamId` values do not cover the complete common and
  operator layout) and `IPC_CMD_DX_PATCH_APPLY`.
- **`include/dx_patch_stage.h`** (new): a cross-core staging slot for a complete
  `RDX_Patch` (about 66 bytes, too large for the 32-bit FIFO word) - core1
  writes it (presets, SysEx bulk dump) and core0 takes it over after
  `IPC_CMD_DX_PATCH_APPLY`.
- **`include/DX_Synth_Bridge.h`:** two new lean pass-through methods
  `processCC()` / `updatePB()`, pointing at the already present but unused
  `RDX_Synth::processCC()` / `updatePB()` methods (no change to the engine
  itself - just two extra call wrappers).
- **`include/midi_reface.h` and `src/midi_reface.cpp`:** a completely new,
  reface-DX-native MIDI/SysEx scheme (common block @ `30 00 00`, 38 bytes;
  operator blocks @ `31 <op> 00`, 28 bytes each; model ID `05H` instead of
  `04H`; identity reply bytes `41 53 06` instead of `41 52 06`), ported 1:1 from
  the ESP32 reference `RDX/RDX_Midi.h`. Control change handling is two-tier: a
  handful of cases stay local to core1 (soft pedal, reset all controllers, omni
  on/off), and the large remainder is passed through unchanged via
  `ipc_send_dx_cc` to `RDX_Synth::processCC`, which already implements mod
  wheel, volume, sustain, portamento, algorithm quick-select and operator
  quick-edit CCs completely - a previously unused code path, and a real
  simplification compared with the much more complex CC table originally
  planned.
- **`include/presets.h` and `src/presets.cpp`:** `CpPreset[8]` -> `DxPreset[1]`
  (a single entry, `"DigiChord"`, a deliberate scope decision; see
  `PRESETS.md`).
- **`include/settings.h` and `src/settings.cpp`:** `SettingsV1` -> `SettingsV2`
  (octave + the 32-byte SYSTEM block + the complete `RDX_Patch`); the storage
  mechanism (veeprom) is unchanged.
- **`include/pico_frontpanel.h` and `src/pico_frontpanel.cpp`:** the DX page
  view (previously reachable only through the "DX Synth" menu entry) is now the
  permanent home screen; all CP screens removed. The menu is only `Presets` /
  `System` / `<< BACK`.
- **`CMakeLists.txt`, `src/usb_descriptors.c`:** `mdaEPiano.cpp` and
  `pico_program_select.cpp` removed from the build, product name and USB string
  `PicoFaceCP` -> `PicoFaceDX`.
- **`effects/cp_hot.h` -> `effects/ram_hot.h`:** the macro `CP_HOT` was renamed
  to `RAM_HOT` (purely cosmetic, no behavioural change), carried through all 10
  `dx_engine` headers plus `DX_Synth_Bridge.cpp`.

### Build verification

- `ninja` -> all targets successful, no new warnings (only the known ones
  inherited from the ESP32 original).
- **FLASH: 142,864 B / 16 MB, about 0.85 %** (before 26.76 % with the CP sample
  data).
- **RAM: 71,672 B / 512 KB, about 13.67 %** (before 45.98 %).
- A grep sweep over `src/`, `include/` and `effects/` confirms: no
  `mdaEPiano` / `RefaceCpChain` / `CpPreset` / `FxParam` / `FxMode` / `CP_HOT`
  references left (apart from two purely historical comment sites, cleaned up as
  well: the header line of `include/veeprom.h` and the `.gitignore` entries for
  the deleted test binaries).

### STATUS NOW

PicoFaceDX is from now on a **pure reface DX clone** without any reface CP
engine, effect chain, presets or MIDI layer. The hardware binding (pin
configuration, USB MIDI transport, virtual EEPROM, generic OLED dialogs) remains
unchanged as a skeleton. Documentation updated: `README.md`,
`MIDI_IMPLEMENTATION.md` (v2.0), `PERSISTENCE.md`, `PRESETS.md`;
`CHANGELOG_MIDI_RP2350.md` marked as superseded and archived.

**Still open** (unchanged from section 9, now without the CP legacy): applying
master tune to the engine (currently a no-op, `tuningSemitones` not wired), real
numeric display on the OP and LFO pages instead of placeholder text, extending
the preset library (parity with the real reface DX factory bank), a CPU load
test of `MAX_VOICES=8` on real hardware, and a DX host test analogous to the
removed CP `cp_test`.

---

## 13. Addendum: phase A - MIDI spec accuracy (2026-07-06)

**Goal:** a gap analysis plan (based on the official Yamaha Data List and
Reference Manual plus another review of the ESP32 reference project) uncovered
several concrete deviations of our MIDI implementation from the real reface DX.
This addendum fixes the small, low-risk corrections ("phase A" of the plan); the
larger items (the preset library from the ESP32 project, and the effect chain)
follow in separate passes.

- **CC11 (expression) was specified but not wired.** `RDX_Synth::processCC` had
  no `case 11`. Now: `RDX_Controls` gained `expression` / `expressionFactor`
  (default 127/1.0, as in the real reset-all-controllers behaviour), `processCC`
  handles CC11 exactly like CC7 (volume), and `calcOutputGain()` additionally
  multiplies by `expressionFactor`.
- **CC66/CC67 (sostenuto and soft pedal) do not exist on the real reface DX**
  (only the reface CP has them) - confirmed against the official Data List. The
  CC67 soft pedal handling (velocity scaling by 0.75x), a leftover of the
  removed reface CP layer, was removed entirely: the `_softPedal` member from
  `midi_reface.h` and all its uses in `midi_reface.cpp` (`onNoteOn`, `init`,
  `resetControllers`, `onControlChange`).
- **The "MIDI control" gate reintroduced.** The official Data List confirms that
  on real hardware CC80 (algorithm) and CC85-90/102-119 (operator quick edit)
  only take effect while SYSTEM "MIDI control" is on; all other CCs (mod wheel,
  volume, expression, sustain, portamento, all sound/notes off) are always
  active. `RefaceMidi::onControlChange` now checks that correctly before
  forwarding the gated CCs.
- **Reset all controllers completed.** The Data List specifies for CC121: pitch
  bend -> centre, modulation -> 0 (minimum), expression -> 127 (maximum),
  sustain -> off. `resetControllers()` now sends all four instead of only pitch
  bend and sustain.
- **Documentation error corrected:** `MIDI_IMPLEMENTATION.md`, `PRESETS.md` and
  a code comment in `src/midi_reface.cpp` wrongly claimed that the real reface
  DX has no MIDI program change at all. Per the official Data List it does
  support program change 0-31 (4 banks of 8 presets) - this firmware implements
  only value 0 of that so far (the single preset "DigiChord"), which is now
  documented correctly as an open scope item rather than as (non-existent) spec
  parity.
- **A real bug found and fixed:** the stack buffer `buf[48]` in
  `RefaceMidi::txBulkBlock()` was too small - a complete common block bulk dump
  (38 data bytes) needs 11 header bytes + 38 data + checksum + F7 = 51 bytes,
  three more than the buffer held (a stack buffer overflow, reported by the
  compiler as `-Wstringop-overflow`). The buffer was enlarged to `buf[64]`. The
  bug had existed since the original SysEx implementation (section 12) and only
  became visible through another full rebuild in this session.

### Build verification

`ninja` -> successful, no new warnings left (the `-Wstringop-overflow` fixed by
the buffer change). FLASH 143,400 B / 16 MB, about 0.85 %; RAM 71,752 B / 512
KB, about 13.69 % (marginally above section 12, from the new `expression` and
`expressionFactor` fields).

### STATUS NOW

Phase A of the 100 % clone plan is complete. Still open: phase B (the preset
library from the 34 `.syx` factory files of the ESP32 reference project) and
phase C (the effect chain - 2 slots, 8 effect types, currently completely
unwired despite the memory already reserved in `RDX_Common::effects[2][3]`).

---

## 14. Addendum: phase B - preset library (2026-07-06)

**Goal:** grow from 1 hardcoded preset to the complete 32 real Yamaha reface DX
factory presets (program change 0-31, 4 banks of 8).

- **A new one-time host tool `tools/refacedx/syx_to_patches.cpp`** (not part of
  the firmware build, not compiled by CMake): it reads the 32 official `.syx`
  factory voice bulk dumps from the reference project's `RDX/data/patches/` and
  applies the already verified `syxToPatch()`
  (`include/dx_engine/RDX_Types.h`) to each file; for every patch it prints a
  `{ "Name", patchFromBytes({...150 bytes...}) }` initializer. Built with
  `g++ -std=c++17` (a host compiler, no Pico SDK needed - `RDX_Types.h` is
  already plain standard C++17).
- **Verified byte-exact:** the `voiceName` field of every parsed patch decodes
  to exactly the expected factory voice name as ASCII (spot-checked:
  "DigiChord ", "WobbleBass", "GlassHarp ", "Chopper   "). The byte count per
  patch confirms `sizeof(RDX_Patch)=150` exactly.
- **File order -> program change mapping:** the 32 file names encode bank and
  slot (`11` = bank 1 slot 1 … `48` = bank 4 slot 8); the generated table puts
  them in exactly PC 0..31 order. A 33rd file, `00-Init_Voice.syx`, exists in
  the ESP32 project as well, but it is not a real factory bank slot (it falls
  outside 0-31) and was deliberately left out.
- **`include/presets.h` / `src/presets.cpp`:** `DX_NPRESETS` 1 -> 32,
  `dxPresets[]` now filled with all 32 generated patches, plus a new
  `patchFromBytes()` helper (a memcpy of the 150 raw bytes into an
  `RDX_Patch`). `preset_apply` / `preset_stage` / `preset_set_current` /
  `preset_get_current` are unchanged - the architecture was already laid out for
  N presets.
- **A real follow-on bug found and fixed:** `openPresets()` in
  `pico_frontpanel.cpp` built the menu selection list in `char buf[128]` -
  harmless with a single preset, but a guaranteed stack buffer overflow with 32
  names (up to 10 characters plus a newline, about 360 bytes). The buffer was
  enlarged to `buf[512]`.
- **Documentation corrected:** all remaining "only 1 preset" and "only value 0
  is valid" statements in `MIDI_IMPLEMENTATION.md`, `PRESETS.md` and a code
  comment in `src/midi_reface.cpp` were updated - program change now covers the
  full real range 0-31.

### Build verification

`ninja` -> successful, no new warnings. FLASH 150,272 B / 16 MB, about 0.90 %
(before 0.85 % - the 32 x 150 bytes of preset data account for roughly 7 KB);
RAM 76,592 B / 512 KB, about 14.61 %.

### STATUS NOW

Phase B is complete. The preset library has full parity with the real reface DX
factory bank. Still open: phase C (the effect chain - by far the largest
remaining effort) and the longer-standing items (master tune wiring, numeric
display on the OP and LFO pages, a CPU load test on real hardware, a DX host
test).

---

## 15. Addendum: phase C - the effect chain (2026-07-06)

**Goal:** close the largest remaining gap to the real reface DX: two independent
effect slots, each selectable among 8 types (thru, distortion, touch wah,
chorus, flanger, phaser, delay, reverb) - confirmed against the official Yamaha
Data List AND the ESP32 reference project (`RDX_FX.h` plus `fx_*.h`), which
brings a complete, finished implementation of all 8 types.
`RDX_Common::effects[2][3]` had reserved the matching memory ever since the
original engine port, but it was wired up nowhere - until now the DX voice was
100 % dry.

### Ported files (all in `include/dx_engine/`, faithful to the ESP32 original)

- `fx_base.h` - the `FXBase` interface (virtual: `init` / `reset` /
  `processBlock` / `prepare`) plus `FxThru`.
- `fx_distortion.h`, `fx_touch_wah.h`, `fx_chorus.h`, `fx_flanger.h`,
  `fx_phaser.h` (a 2-notch phaser plus an internal flanger layer, the largest
  module at 256 lines in the original), `fx_delay.h`, `fx_reverb.h` (4 combs
  plus 2 all-passes per channel) - all DSP algorithms, coefficients and
  constants taken over 1:1, no tonal changes.
- All required LUTs and helpers (`LFO_SPEED`, `PM_DEPTH`, `DELAY_TIME_MS`,
  `sin01`, `semitonesToRatio`, `wrap01`, `fclamp`, `saturate_cubic`) were
  already present in the project from the original engine port - not a single
  new LUT was needed.

### RP2350 adaptations (ESP32-specific parts replaced, the DSP untouched)

- **The `prepare()` signature was simplified:** the ESP32 distinguished "fast"
  (DRAM) and "slow" (PSRAM) scratch buffers per slot; the RP2350 has no PSRAM
  tier in this build, so there is one shared buffer per slot
  (`prepare(float* scratch, uint32_t scratchSize, int sampleRate)`).
- **`DX_FXHost`** (`include/dx_engine/DX_FXHost.h`, new, not a 1:1 port): 2
  slots x 8 effect types as a static object pool (no allocation when switching
  effects), with one fixed `float[24576]` buffer per slot (96 KB) - sized for
  the largest single requirement (`FxReverb`, computed at 24276 floats, rounded
  up with margin). The ESP32's `heap_caps_get_largest_free_block` and
  `MALLOC_CAP_*` probing and the dynamic polyphony throttling (a `VOICES`
  estimate from measured effect compute time) are gone without replacement -
  this project already has a fixed `MAX_VOICES` budget.
- **The memory budget was checked, not guessed:** 2 x 96 KB = 192 KB of RAM for
  effect scratch buffers, which together with the rest of the firmware makes
  52.76 % of 512 KB - enough margin for stacks and so on (see the build
  verification below).
- **A real bug found (through a host smoke test before the actual Pico build)
  and fixed:** `FxTouchWah::reset(bool instant=false)` had a different signature
  from `FXBase::reset()` and therefore **hid** the virtual function instead of
  overriding it (`-Woverloaded-virtual`) - a bug taken over from the ESP32
  original, where it was equally present. A call through `FXBase*` - exactly
  what `DX_FXHost::setSlot()` does on an effect change - silently called the
  no-op base version, so the internal filter and envelope state was not reset
  when switching TO touch wah. Fix: `reset()` without a parameter, `override`
  added, and the single call site in `prepare()` adjusted.

### Wiring

- **`DX_Synth_Bridge`:** a new member `DX_FXHost fxHost_;`, `init()` calls
  `fxHost_.init((float)SAMPLE_RATE)`, and `fill_buffer()` calls
  `fxHost_.process(scratchL_, scratchR_, chunkLen)` right after
  `synth_.renderAudioBlock(...)` and before the interleaving - so the effects
  run post-mix, as on real hardware.
- **SysEx and patch editing work automatically:** `effects[2][3]` lies in the
  already addressable common block (offset `0x1D-0x22`); as soon as the DSP
  consumes those bytes, the already generic `IPC_CMD_DX_RAW_WRITE` path applies
  with no new IPC work at all.
- **No MIDI CC control needed:** the official Data List confirms that effects are
  addressed only through the patch and SysEx, and that no dedicated CC
  assignment exists.
- **New front panel pages FX1/FX2** (`DX_Controller`: `DxPage` extended by `FX1`
  and `FX2`; encoder A = effect type 0-7, clamped like ALGO, encoder B = param 1
  0-127; both through `ipc_send_dx_raw_write(1, offset, val)` using
  `offsetof(RDX_Common, effects)` instead of magic numbers). Param 2 stays
  SysEx-only, like many other patch parameters (voice name, KSC curves) that are
  equally out of reach of the three encoders.
- **`DX_GUI::dxDrawScreen()`:** the FX1/FX2 pages now show the real effect name
  (`FX_NAMES[]`, new in `DX_FXHost.h`) plus the param 1 value instead of the
  generic placeholder text - the other pages (OP1-4/LFO) still show the
  placeholder (still an open point).

### Build verification

`ninja` -> successful, no new warnings apart from a harmless signedness
comparison warning in `fx_delay.h` that was already in the ESP32 original. FLASH
166,128 B / 16 MB, about 0.99 %; RAM 276,616 B / 512 KB, about 52.76 % (a clear
but budgeted jump from the 192 KB of effect scratch buffers).

### STATUS NOW

Phase C is complete. PicoFaceDX now has a complete, working effect chain with
all 8 real reface DX effect types, editable by patch and SysEx and reachable
through two new front panel pages (FX1/FX2). All three phases of the 100 % clone
plan (A: MIDI spec accuracy, B: preset library, C: effect chain) are done.

**Still open** (phase D of the plan, lower priority): master tune wiring
(`tuningSemitones` still unwired), real numeric display on the OP and LFO pages
(still placeholder text), delay time display in milliseconds instead of the raw
value, a CPU load test of `MAX_VOICES=8` with active effects on real hardware
(more relevant now because of the effect chain), and the absence of a DX host
test.

---

## 16. Addendum: phase D - polish (2026-07-06)

**Goal:** work off the three polish items left open in phase C: master tune
wiring, real numeric display on the OP and LFO front panel pages, and a basis
for measuring CPU load with the effect chain active.

### Master tune wired up (a SYSTEM SysEx parameter, not a MIDI CC)

`RDX_Controls::tuningSemitones` had been stored and round-tripped since the
original engine port, but was consumed nowhere in the audio path. It is now
fully wired, end to end across the core boundary:

- **`RDX_Voice.h`** (`updateMods()`): the pitch calculation was extended from
  `ctl_.pitchbendSemitones` to
  `ctl_.pitchbendSemitones + ctl_.tuningSemitones` - master tune acts additively
  to the pitch bend on all operators, exactly as on real hardware.
- **`RDX_Synth.h`**: a new `setMasterTune(float semitones)`, which sets
  `ctl_.tuningSemitones`.
- **`ipc.h`**: a new `IPC_CMD_DX_MASTER_TUNE` plus
  `ipc_send_dx_master_tune(uint16_t rawTune)` - an IPC command of its own rather
  than misusing CC or raw write, because master tune is global controls state,
  not a patch byte and not a CC. Core0 decodes the four nibble bytes into cents
  and semitones (the formula per the official Yamaha Data List:
  `cents = (raw - 1024) * 0.1`, clamped to ±102.4/±102.3 cents) in
  `ipc_apply()` in `main.cpp`.
- **`DX_Synth_Bridge.h`**: a `setMasterTune(float semitones)` pass-through to
  `synth_.setMasterTune()`.
- **`midi_reface.cpp`**: `applyMasterTune()` was a documented no-op stub from
  phase A (correct at the time, because `tuningSemitones` was still unwired) -
  now a real implementation: it reads `_sys[SYS_TUNE_0..3]`, reconstructs the
  16-bit raw value from the four nibbles (`(t0<<12)|(t1<<8)|(t2<<4)|t3`, each
  masked with `& 0x0F` per the official Data List: "1st bit 3-0: bit 15-12" and
  so on) and sends it with `ipc_send_dx_master_tune()`.

### Real numeric display on the OP1-4 and LFO pages

`DX_GUI::dxDrawScreen()` used to show only the generic placeholder text
"(values shown via encoders)" for the OP1-4, LFO and ALGO pages - exactly like
the FX1/FX2 pages before they got their own display in phase C. It has now been
extended after the same pattern:

- **OP1-4:** `"Freq: %d"` (`ops[opIdx].freqCoarse`, which is what encoder A
  actually writes on this page) and `"Level: %d"` (`ops[opIdx].outLevel`, what
  encoder B writes).
- **LFO:** `"Speed: %d"` (`common.lfoSpeed`) and `"PMD: %d"`
  (`common.lfoPMD`).
- ALGO keeps its graphical algorithm rendering (`drawAlgo()`) and FX1/FX2 keep
  their phase C display - both unchanged.

### CPU load instrumented (no hardware test possible by me)

The plan called for a real CPU load test of `MAX_VOICES=8` with active effects
on real hardware. I have no physical RP2350 board, so an actual hardware test
cannot be performed or claimed by me. Instead the basis for measuring it was
created, so that the user can read real numbers after flashing:

- **`DX_Synth_Bridge::fill_buffer()`**: measures the actual block duration
  (rendering plus effect chain) with `time_us_32()` and compares it against the
  block's real-time budget (`length / SAMPLE_RATE` seconds). The result lands in
  two new members, `cpuLoadPercent_` (the last block) and `cpuLoadPeakPercent_`
  (the maximum since boot), readable publicly through `cpuLoadPercent()` and
  `cpuLoadPeakPercent()` - core1 may read them directly, the same convention as
  for `patch()`.
- **A new front panel page:** the SYSTEM menu was extended by "CPU Load"
  (`pico_frontpanel.cpp`, `showCpuLoad()` after the model of `showAbout()`) - it
  shows "Now" and "Peak" in percent, updated live.
- No overhead in the hot path beyond two `time_us_32()` calls (already in IRQ
  context, so no additional synchronization is needed).

### Build verification

`ninja` -> successful, no new warnings. FLASH 166,384 B / 16 MB, about 0.99 %;
RAM 276,544 B / 512 KB, about 52.75 % (a minimal increase over phase C: +256 B
of flash and +16 B of RAM for the whole of phase D).

### STATUS NOW

Phase D is complete, so all four phases of the 100 % clone plan (A: MIDI spec
accuracy, B: preset library, C: effect chain, D: polish) are implemented. What
remains is the actual CPU load test on real hardware itself - the measurement
basis is in place, but reading the real percentage while playing with active
effects can only be done by the user on a real board.

---

## 17. Addendum: compiler warnings cleaned up (2026-07-06)

**Trigger:** the user reported various warnings in the build log. They were
split into project-owned warnings (fixable) and vendor warnings (not fixable, or
not sensibly fixable, because they come from a third-party dependency pulled in
by CMake `FetchContent`).

### Project-owned warnings fixed (all in `include/dx_engine/`)

- **`misc.h` - `fclamp()` / `saturate_cubic()`:** two `if` statements each stood
  on one line (`-Wmisleading-indentation`) - split onto separate lines, no
  change in logic.
- **`misc.h` - `fast_floorf()`, a real bug, not just a warning:**
  `int i = (int)x - (int)(i>x);` read the local variable `i` inside its own
  initializer, before it had a value - undefined behaviour (`-Wuninitialized`).
  **This bug already existed in the ESP32 original** (`RDX/misc.h:27`, identical
  code) and was taken over 1:1 in the original engine port - just like the
  `FxTouchWah::reset()` bug found in phase C. `fast_floorf()` and `wrap01()` are
  used among other things for LFO phase wrapping (`RDX_LFO.h`), so the UB could
  potentially have caused phase glitches. Fixed with the standard
  truncate-then-adjust trick:
  `int i = (int)x; return (float)(i - (int)(i > x));`
- **`RDX_Types.h` - `syxToPatch()`:** `while (...) i++; i++;` on one line
  (`-Wmisleading-indentation`) - split onto two lines; the unconditional `i++`
  stays unconditional, no change in logic.
- **`RDX_Operator.h` - the constructor (`-Wreorder`):** the initializer list
  named `idx_` before `params_` although `params_` is declared first in the
  class (C++ always initializes in declaration order, regardless of list order)
  - the list was reordered (`params_` before `idx_`), pure cosmetics with no
  behavioural change.
- **`RDX_Synth.h` (`renderAudioBlock`) and `fx_delay.h` (`processBlock`)
  (`-Wsign-compare`):** one `for` loop each compared a signed `int` against an
  unsigned `uint32_t` limit (`len` / `frames`) - the loop variable was changed
  to `uint32_t`.

### Not fixed (outside the project source tree)

- `build/_deps/picotool-src/main.cpp:227` (a `static_assert` without a message,
  a C++17 extension warning) and a linker note about "ignoring duplicate
  libraries" (`liberrors.a` / `libmodel.a`) - both come from the `picotool`
  source that CMake pulls in automatically (`_deps/picotool-src/`), not from
  this repository. A patch there would be lost on the next `FetchContent`
  refresh and does not belong to PicoFaceDX - deliberately left alone.

### Build verification

A full rebuild (`cmake --build .` after touching every `.cpp` file, so that
every translation unit is recompiled): **zero warnings** from all project files.
FLASH 163,760 B / 16 MB, about 0.98 %; RAM 273,912 B / 512 KB, about 52.24 % -
slightly smaller than before the clean-up, among other things because the
`fast_floorf` UB path in `misc.h` (which is included practically everywhere) is
gone.

---

## 18. Addendum: two remaining items from the gap analysis (2026-07-07)

**Trigger:** the user's question "is anything still open for the 100 % clone?"
led to another review against the Data List, the Reference Manual and the
codebase. Two small, clearly bounded items were identified and fixed on request
(no tonal or protocol gap - pure code hygiene and display polish).

### Dead code removed: `RDX_Synth::programChange()` / `applyBankProgram()`

A grep over the whole source tree confirmed that neither method was called
anywhere. The real program change path has run entirely through
`midi_reface.cpp::onProgramChange()` -> `presets.cpp` ->
`IPC_CMD_DX_PATCH_APPLY` -> `preset_apply()` since phase B; the `RDX_Synth`
method was a leftover from before phase B, and its comment
`// TODO: multi-patch storage — for now always load the hardcoded init voice`
had been factually wrong since phase B (there are 32 real presets, just via the
other path). Both methods were deleted without replacement (`RDX_Synth.h`).
`ctl_.wantProgram` / `wantBankMSB` / `wantBankLSB` / `getWantBank()` in
`RDX_Types.h` were left untouched (deliberately out of scope -
`wantBankMSB`/`wantBankLSB` are still written by the real, active CC0/32
handlers, matching the "received and stored but not consumed" pattern
established elsewhere, e.g. tempo, LCD contrast and pedal model in the SYSTEM
block).

### FX1/FX2 display: effect-specific labels instead of a generic "Param1"

The front panel pages used to show "Param1: %d" regardless of the effect type.
Checked against the `processBlock()` of every `fx_*.h`, what the param 1 byte
(`effects[slot][1]`, the only one the encoders actually write - param 2 stays
SysEx-only) means per type: distortion = drive, touch wah = sens,
chorus/flanger/phaser/reverb = depth, delay = feedback; thru has no parameters
at all.

- **`DX_FXHost.h`:** a new `FX_PARAM1_LABELS[FX_COUNT]` array, indexed like
  `FX_NAMES[]`.
- **`DX_GUI::dxDrawScreen()`:** the FX1/FX2 branch now uses `"%s: %d"` with
  `FX_PARAM1_LABELS[typeId]` instead of the generic label; for thru the second
  line is omitted entirely (no parameter exists, so no empty or misleading
  line).
- The values stay raw (0-127) on purpose, consistent with all the other pages
  (OP1-4 likewise show raw values for freq and level, with no conversion). An
  idea noted in phase C, "show the delay time in milliseconds", resolves itself
  this way: the time is param 2 (delay/reverb), which stays SysEx-only and is
  never shown on the front panel - param 1 for delay is feedback, and a plain
  raw value without a unit really does fit best there.

### Build verification

Full rebuild: **zero warnings**. FLASH 163,864 B / 16 MB, about 0.98 %; RAM
273,912 B / 512 KB, about 52.24 % (a minimal change: -168 B of flash from the
deleted methods, +272 B from the new label array and the GUI change, for a net
+104 B).

### STATUS NOW

Both items raised in the user's question are done. The 100 % clone plan (A-D)
remains fully complete; the only remaining point I cannot close myself is still
the CPU load test on real hardware (the measurement instrumentation has been
there since phase D, see §16). The three-encoder user interface (against the
roughly 20 direct knobs of the real reface DX) remains a deliberate hardware
decision fixed since the start of the project, not a firmware gap.

---

## 19. Addendum: a real hardware CPU load test uncovers an effect-switch bug (2026-07-07)

**Trigger:** the user ran the CPU load test instrumented in phase D on real
hardware (the one open point I could not close myself). Result: **now 49-60 %
(good), peak 140 %** - a peak above 100 % means a real buffer underrun (an audio
glitch or click at that moment), not a measurement error.

### Root cause

`SAMPLES_PER_BUFFER` (`lib/audio/include/audio_subsystem.h`) is **16** samples -
at 44.1 kHz only about **363 µs** of real-time budget per I2S IRQ block.
`DX_FXHost::setSlot()` (called on every effect type change: an encoder on
FX1/FX2, a preset change, a SysEx patch load) called `resetSlot()`, which
**always cleared the full 96 KB scratch buffer** (24576 floats, sized for the
largest single requirement, `FxReverb`) with `memset()` - regardless of which of
the 8 effect types was actually activated. Estimated memset duration at about
150 MB/s of throughput: 400-650 µs depending on the real memory throughput at
runtime - which blows the 363 µs budget on practically every switch and explains
the measured 140 % peak.

The reason **some** clearing is necessary: chorus, flanger, phaser, delay and
reverb all place their delay lines as pointer aliases into the same shared
`scratch_[slot]` buffer (a RAM saving from phase C - only one effect per slot is
ever active). Without clearing on a switch, the new effect instance would find
the raw data of the previous effect as its delay line content (an audible
phantom echo artifact). The phase C fix recognized that correctly, but solved it
with the most expensive approach imaginable (always clear everything) instead of
the cheapest (clear only the region actually needed).

### Fix

- **`fx_base.h`:** a new virtual method `scratchFootprintFloats()`, defaulting
  to `0` (thru, distortion and touch wah never touch `scratch_`).
- **`fx_chorus.h` / `fx_phaser.h`:** override with `MAX_DELAY * 2` resp.
  `FLANGER_BUF_SIZE * 2` -> 8192 floats instead of 24576 (66.7 % less).
- **`fx_flanger.h`:** override with `bufferSize_ * 2` (a runtime value from
  `prepare()`, about 1338 floats at 44.1 kHz) -> 94.6 % less.
- **`fx_delay.h`:** override with `MAX_DELAY * 2` = 22050 floats (10.3 % less
  than the full buffer - delay itself needs almost the reverb maximum, see
  below).
- **`fx_reverb.h`:** the override sums `combSize_[ch][i]` + `allSize_[ch][i]`
  over both channels at runtime (a loop, uncritical - it runs once per switch,
  not per sample) -> exactly the roughly 24276 floats actually needed (no
  structural difference from the worst case, since reverb *is* the worst case).
- **`DX_FXHost.h`:** `resetSlot()` now takes the incoming `FXBase*` instance,
  asks it for `scratchFootprintFloats()` (defensively clamped to
  `FX_SCRATCH_FLOATS`) and clears only that region instead of always
  `sizeof(scratch_[slot])`.

### Result and remaining limitation

For 6 of the 8 target effects (thru, distortion, touch wah: no clearing needed;
chorus and phaser: 8192 instead of 24576 floats; flanger: 1338 instead of 24576)
the peak is now fully within the 363 µs budget. For the remaining two (delay:
22050 floats, reverb: about 24276 floats) a short, unavoidable blip remains when
switching **specifically into those two effect types** - their delay lines are
inherently so large that even their actual (no longer worst-case) requirement
exceeds the 363 µs budget of a single audio IRQ. Eliminating it entirely would
mean spreading the clear over several audio blocks (a state machine with
intermediate muting) - deliberately not implemented, since that is a
considerably larger intervention for a rare, user-driven event (turning the
encoder on the FX type), not a permanent condition while playing.

### Build verification

Full rebuild: **zero warnings**. FLASH 164,064 B / 16 MB, about 0.98 %; RAM
273,936 B / 512 KB, about 52.25 % (a minimal change: +200 B of flash and +24 B
of RAM for the 5 new overrides plus the `DX_FXHost` change).

### STATUS NOW

The hardware test carried out by the user uncovered a real, previously
undetected performance bug and led directly to its fix - exactly the purpose of
the instrumentation added in phase D. Recommendation to the user: run the load
test on real hardware again and in particular switch back and forth between
delay and reverb deliberately, to confirm that the peak now only occurs on those
two switches and no longer on the other six effect types.

---
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

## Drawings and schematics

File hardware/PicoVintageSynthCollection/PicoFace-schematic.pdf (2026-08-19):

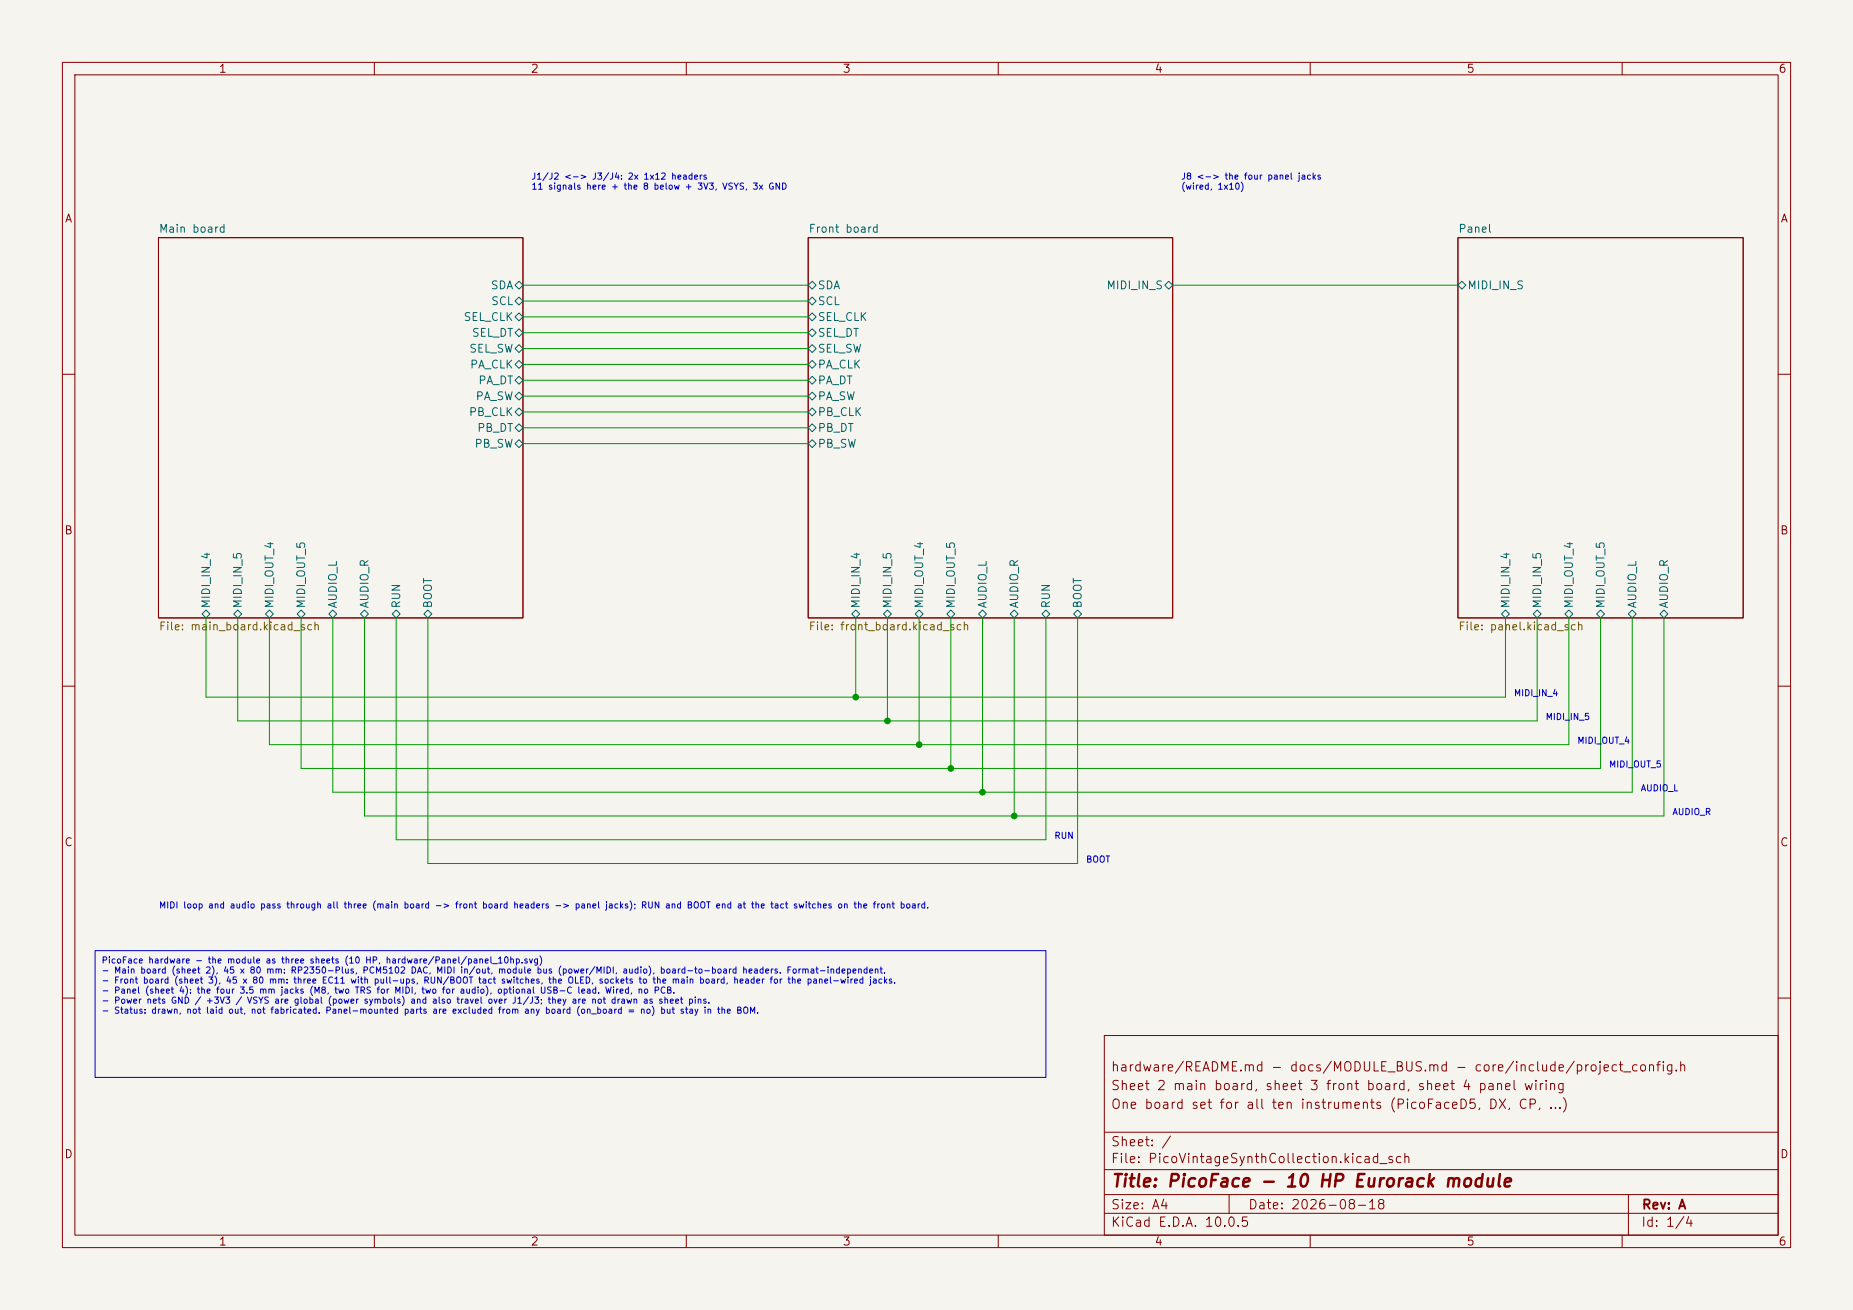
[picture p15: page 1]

J1/J2 <-> J3/J4: 2x 1x12 headers 11 signals here + the 8 below + 3V3, VSYS, 3x GND
(wired, 1x10) RUN

J8 <-> the four panel jacks

Panel File: panel.kicad_sch SDA SCL SEL_CLK

PicoFace hardware - the module as three sheets (10 HP, hardware/Panel/panel_10hp.svg) - Main board (sheet 2), 45 x 80 mm: RP2350-Plus, PCM5102 DAC, MIDI in/out, module bus (power/MIDI, audio), board-to-board headers. Format-independent. - Front board (sheet 3), 45 x 80 mm: three EC11 with pull-ups, RUN/BOOT tact switches, the OLED, sockets to the main board, header for the panel-wired jacks. - Panel (sheet 4): the four 3.5 mm jacks (M8, two TRS for MIDI, two for audio), optional USB-C lead. Wired, no PCB. - Power nets GND / +3V3 / VSYS are global (power symbols) and also travel over J1/J3; they are not drawn as sheet pins. - Status: drawn, not laid out, not fabricated. Panel-mounted parts are excluded from any board (on_board = no) but stay in the BOM.

hardware/README.md - docs/MODULE_BUS.md - core/include/project_config.h
Sheet 2 main board, sheet 3 front board, sheet 4 panel wiring
One board set for all ten instruments (PicoFaceD5, DX, CP, ...)

Sheet: /
File: PicoVintageSynthCollection.kicad_sch
Title: PicoFace - 10 HP Eurorack module

Size: A4 | Rev: A
KiCad E.D.A. 10.0.5 | Id: 1/4

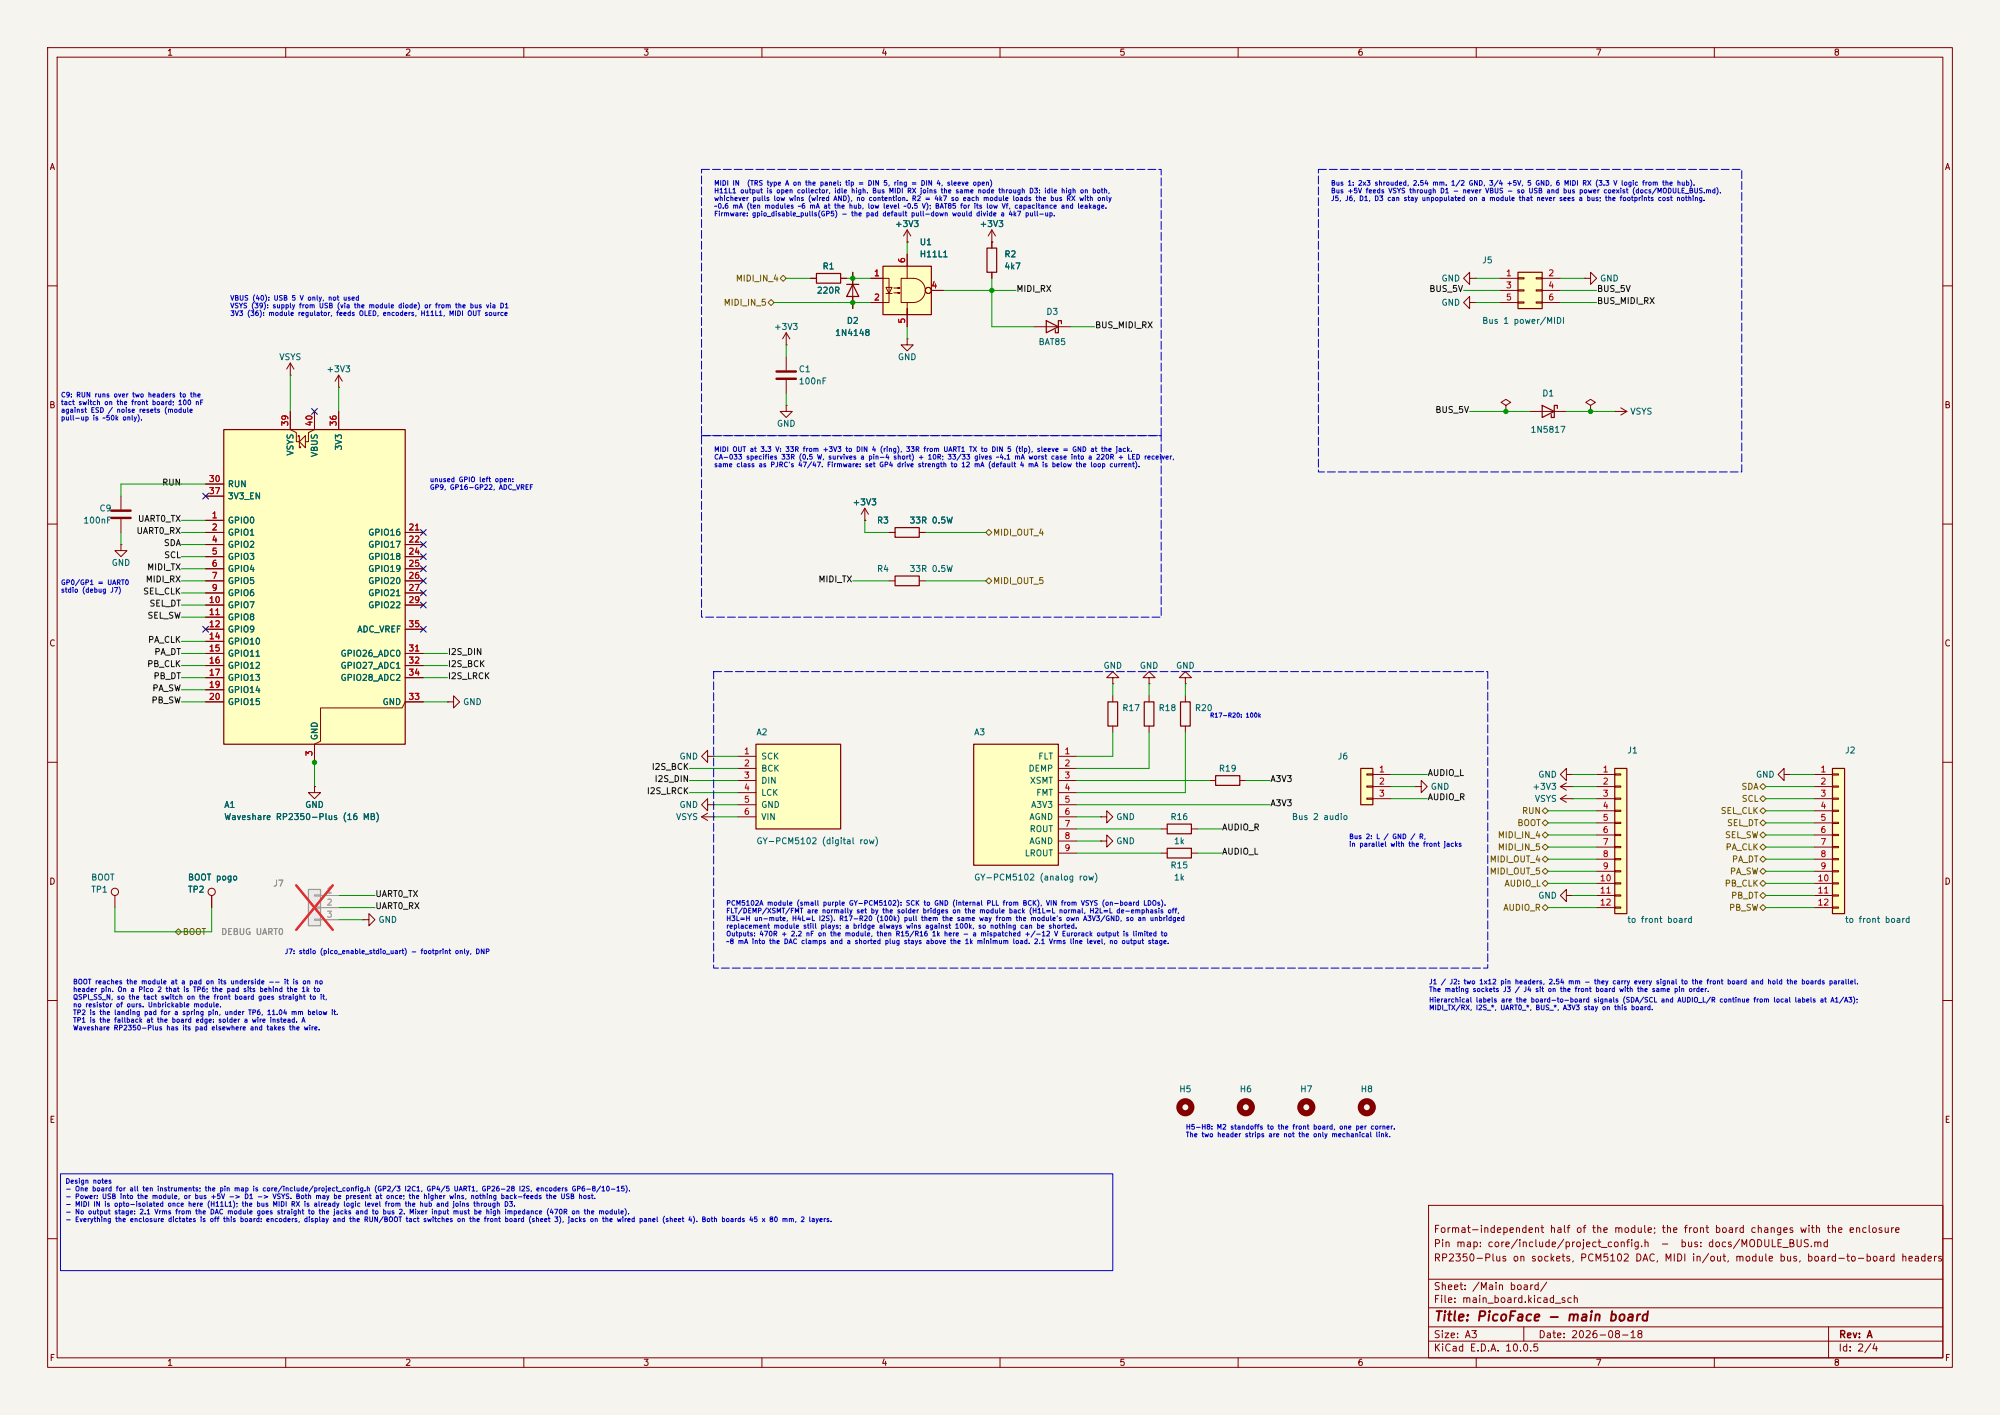
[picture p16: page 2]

MIDI IN (TRS type A on the panel: tip = DIN 5, ring = DIN 4, sleeve open) H11L1 output is open collector, idle high. Bus MIDI RX joins the same node through D3: idle high on both, whichever pulls low wins (wired AND), no contention. R2 = 4k7 so each module loads the bus RX with only

~0.6 mA (ten modules ~6 mA at the hub, low level ~0.5 V); BAT85 for its low Vf, capacitance and leakage. Firmware: gpio_disable_pulls(GP5) - the pad default pull-down would divide a 4k7 pull-up.

VBUS (40): USB 5 V only, not used
VSYS (39): supply from USB (via the module diode) or from the bus via D1

tact switch on the front board; 100 nF against ESD / noise resets (module pull-up is ~50k only). GP0/GP1 = UART0

R17-R20: 100k PCM5102A module (small purple GY-PCM5102): SCK to GND (internal PLL from BCK), VIN from VSYS (on-board LDOs). FLT/DEMP/XSMT/FMT are normally set by the solder bridges on the module back (H1L=L normal, H2L=L de-emphasis off, H3L=H un-mute, H4L=L I2S). R17-R20 (100k) pull them the same way from the module's own A3V3/GND, so an unbridged

in parallel with the front jacks H5-H8: M2 standoffs to the front board, one per corner. The two header strips are not the only mechanical link. J7: stdio (pico_enable_stdio_uart) - footprint only, DNP

replacement module still plays; a bridge always wins against 100k, so nothing can be shorted. Outputs: 470R + 2.2 nF on the module, then R15/R16 1k here - a mispatched +/-12 V Eurorack output is limited to

BOOT reaches the module at a pad on its underside -- it is on no

J1 / J2: two 1x12 pin headers, 2.54 mm - they carry every signal to the front board and hold the boards parallel. The mating sockets J3 / J4 sit on the front board with the same pin order.

Design notes - One board for all ten instruments; the pin map is core/include/project_config.h (GP2/3 I2C1, GP4/5 UART1, GP26-28 I2S, encoders GP6-8/10-15). - Power: USB into the module, or bus +5V -> D1 -> VSYS. Both may be present at once; the higher wins, nothing back-feeds the USB host. - MIDI IN is opto-isolated once here (H11L1); the bus MIDI RX is already logic level from the hub and joins through D3. - No output stage: 2.1 Vrms from the DAC module goes straight to the jacks and to bus 2. Mixer input must be high impedance (470R on the module). - Everything the enclosure dictates is off this board: encoders, display and the RUN/BOOT tact switches on the front board (sheet 3), jacks on the wired panel (sheet 4). Both boards 45 x 80 mm, 2 layers.

Format-independent half of the module; the front board changes with the enclosure
RP2350-Plus on sockets, PCM5102 DAC, MIDI in/out, module bus, board-to-board headers

Sheet: /Main board/
File: main_board.kicad_sch
Title: PicoFace - main board

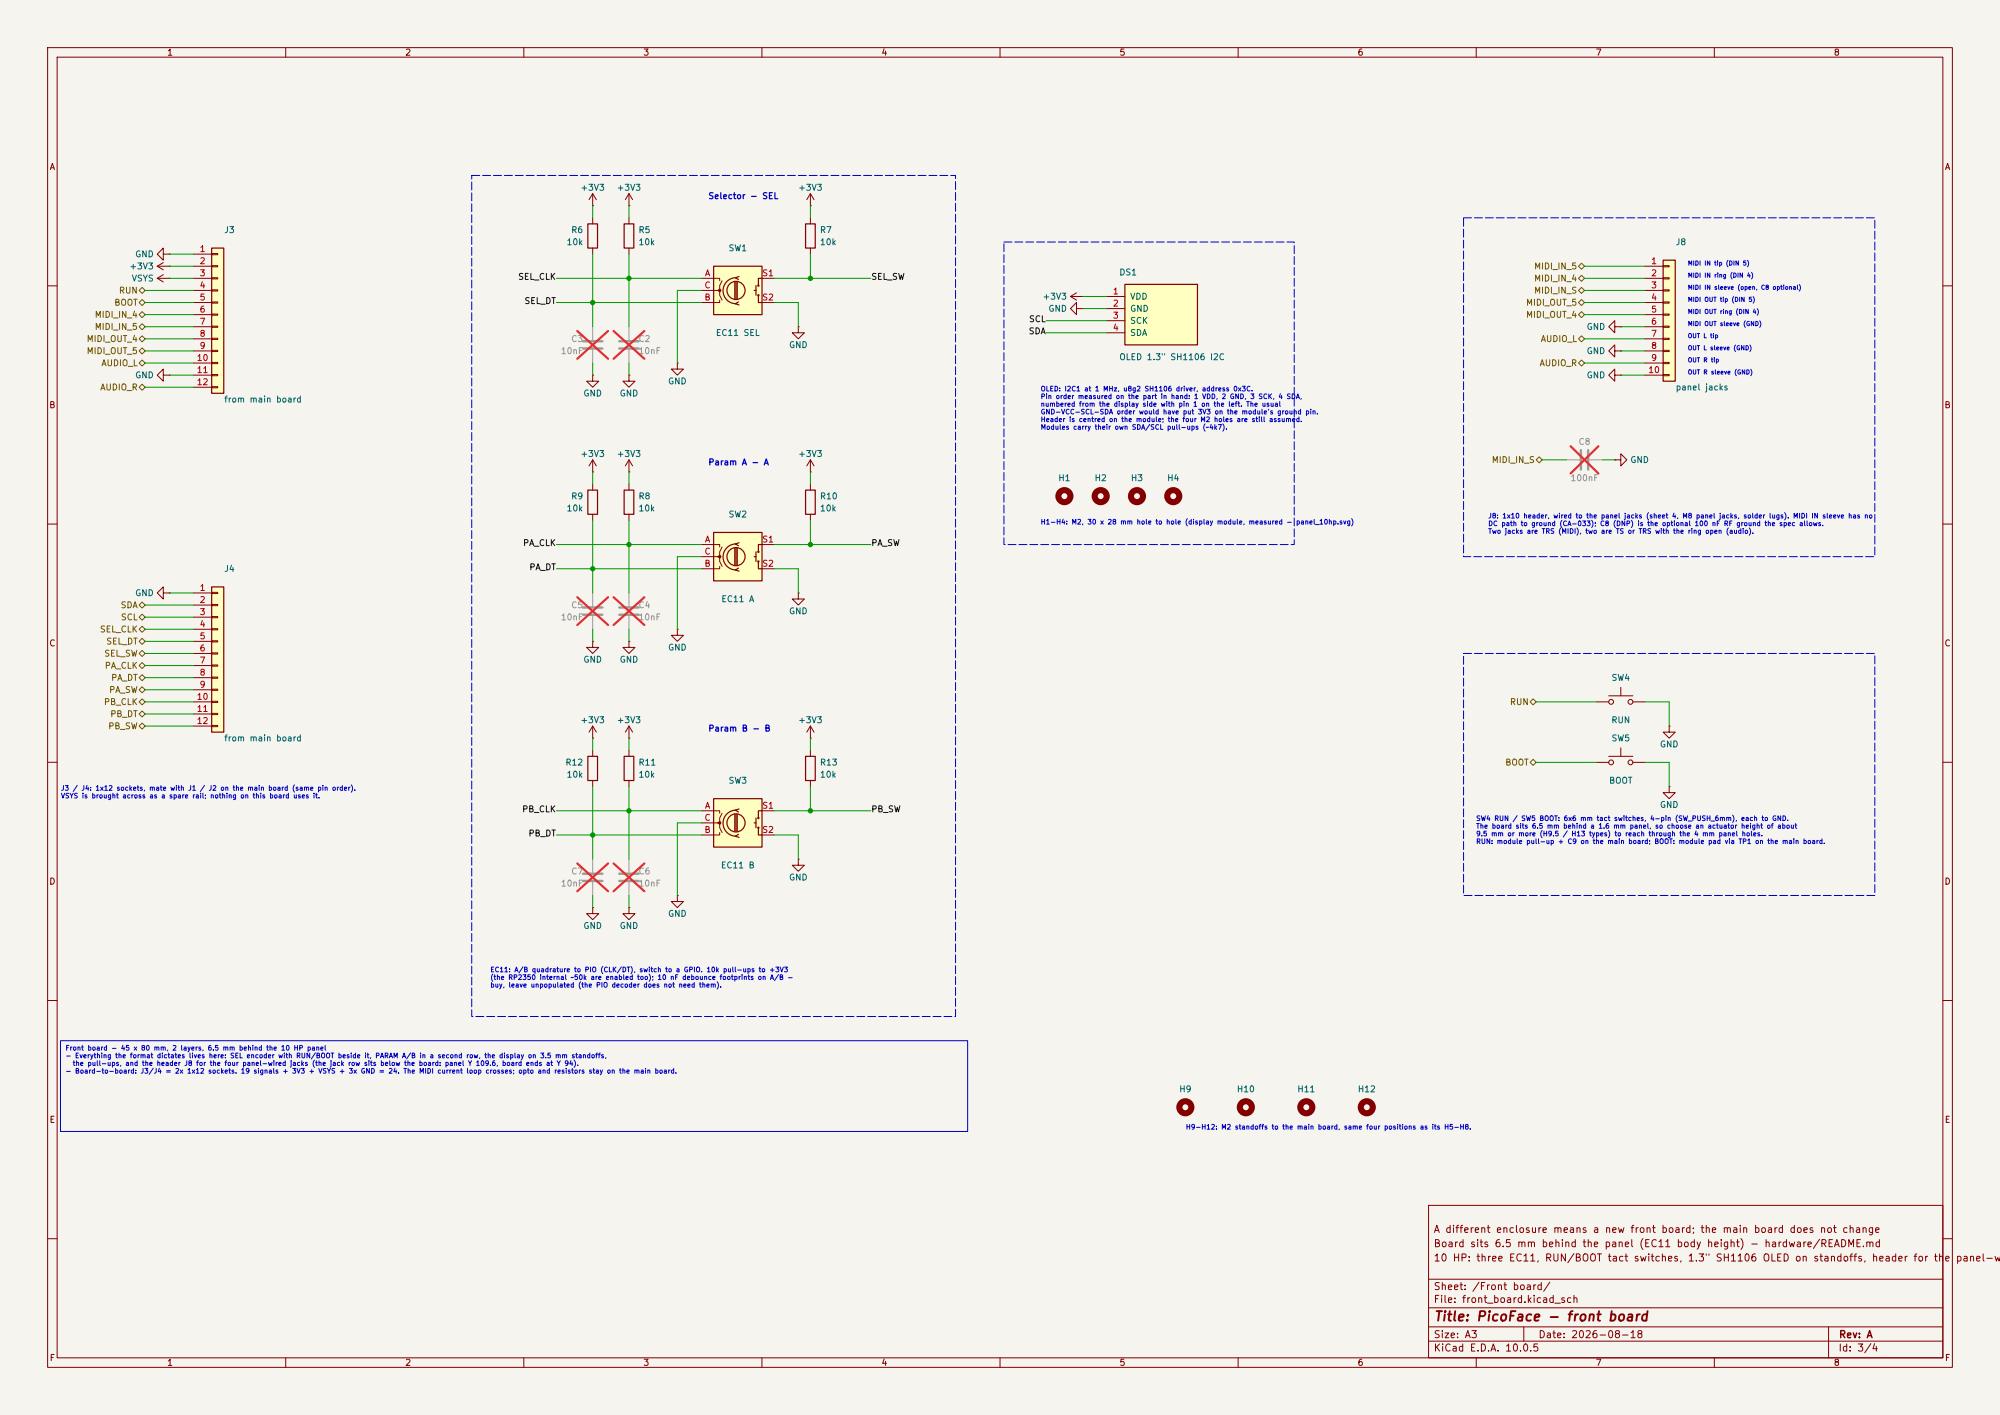
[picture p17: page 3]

J8: 1x10 header, wired to the panel jacks (sheet 4, M8 panel jacks, solder lugs). MIDI IN sleeve has no DC path to ground (CA-033); C8 (DNP) is the optional 100 nF RF ground the spec allows. Two jacks are TRS (MIDI), two are TS or TRS with the ring open (audio). MIDI OUT sleeve (GND) MIDI OUT ring (DIN 4) MIDI OUT tip (DIN 5) MIDI IN sleeve (open, C8 optional) MIDI IN ring (DIN 4) MIDI IN tip (DIN 5)
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

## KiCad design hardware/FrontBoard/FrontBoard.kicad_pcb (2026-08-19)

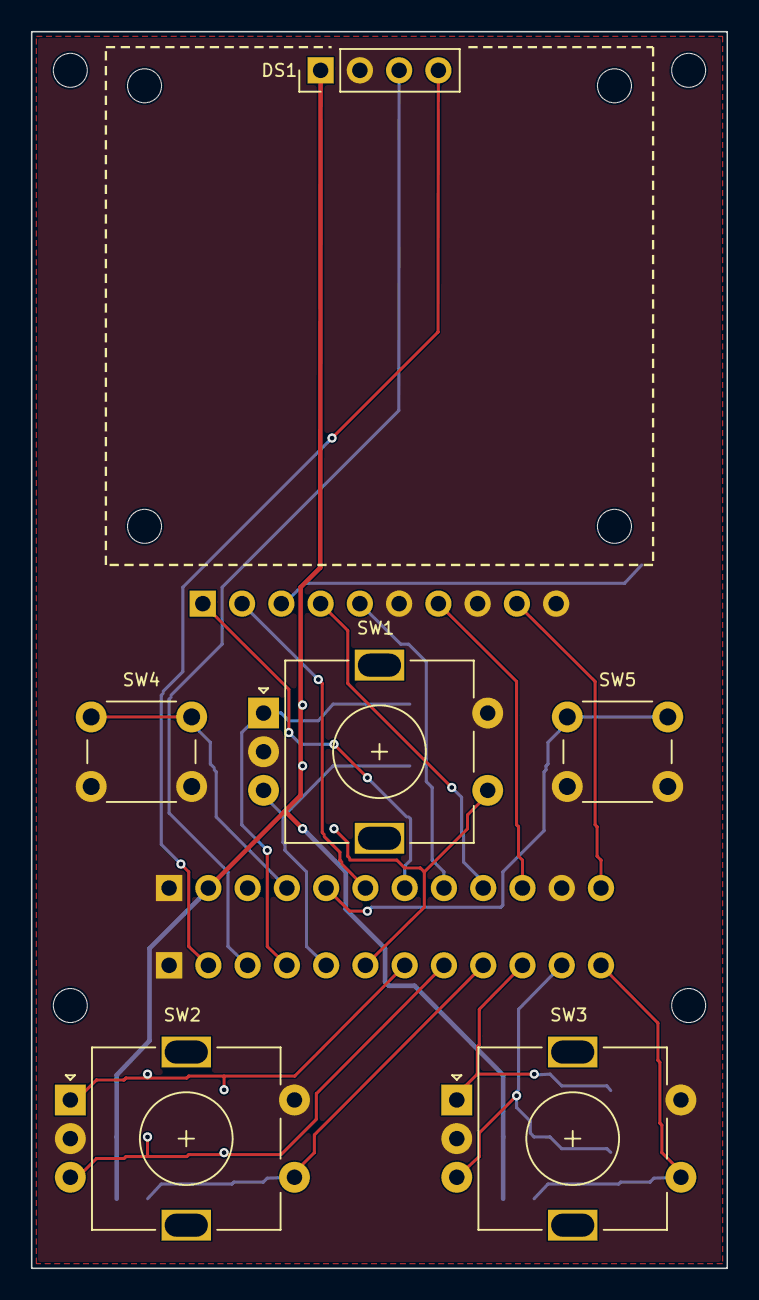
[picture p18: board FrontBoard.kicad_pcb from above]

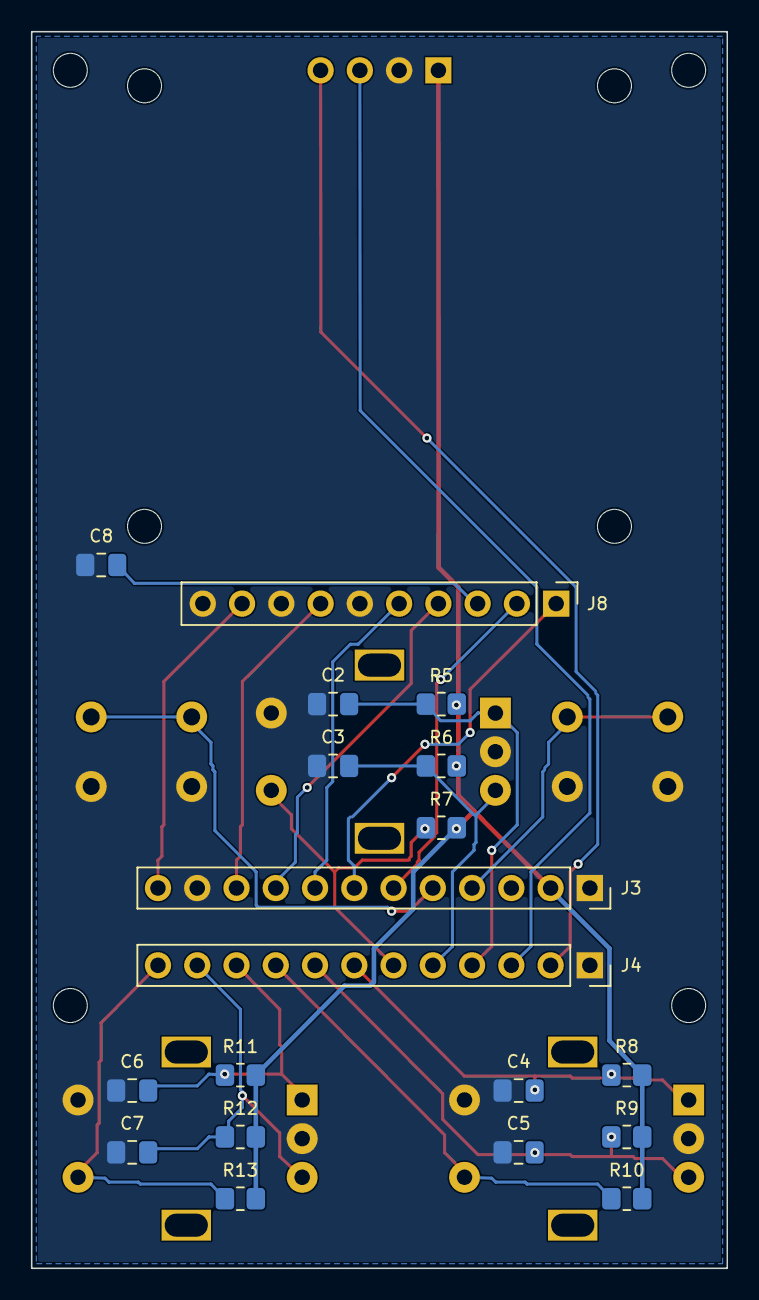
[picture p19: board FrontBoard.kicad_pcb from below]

Board: 2 copper layers, 45.0 x 80.0 mm, 33 parts (23 on the bottom side), 22 nets.

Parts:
C2, C3, C4, C5, C6, C7: 10nF; C_0805_2012Metric_Pad1.18x1.45mm_HandSolder
C8: 100nF; C_0805_2012Metric_Pad1.18x1.45mm_HandSolder
DS1: OLED 1.3" SH1106 I2C; PinHeader_1x04_P2.54mm_Vertical
H1, H2, H3, H4: M2 display standoff; MountingHole_2.2mm_M2
H9, H10, H11, H12: M2 board standoff; MountingHole_2.2mm_M2
J3, J4: from main board; PinSocket_1x12_P2.54mm_Vertical
J8: panel jacks; PinHeader_1x10_P2.54mm_Vertical
R5, R6, R7, R8, R9, R10, R11, R12, R13: 10k; R_0805_2012Metric_Pad1.20x1.40mm_HandSolder
SW1: EC11 SEL; RotaryEncoder_Alps_EC11E-Switch_Vertical_H20mm
SW2: EC11 A; RotaryEncoder_Alps_EC11E-Switch_Vertical_H20mm
SW3: EC11 B; RotaryEncoder_Alps_EC11E-Switch_Vertical_H20mm
SW4: RUN; SW_PUSH_6mm
SW5: BOOT; SW_PUSH_6mm

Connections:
+3V3: DS1.1, J3.2, R5.1, R6.1, R7.1, R8.1, R9.1, R10.1, R11.1, R12.1, R13.1
AUDIO_L: J3.10, J8.7
AUDIO_R: J3.12, J8.9
BOOT: J3.5, SW5.1
GND: C2.2, C3.2, C4.2, C5.2, C6.2, C7.2, C8.2, DS1.2, J3.1, J3.11, J4.1, J8.6, J8.8, J8.10, SW1.C, SW1.S2, SW2.C, SW2.S2, SW3.C, SW3.S2, SW4.2, SW5.2
MIDI_IN_4: J3.6, J8.2
MIDI_IN_5: J3.7, J8.1
MIDI_IN_S: C8.1, J8.3
MIDI_OUT_4: J3.8, J8.5
MIDI_OUT_5: J3.9, J8.4
PA_CLK: C4.1, J4.7, R8.2, SW2.A
PA_DT: C5.1, J4.8, R9.2, SW2.B
PA_SW: J4.9, R10.2, SW2.S1
PB_CLK: C6.1, J4.10, R11.2, SW3.A
PB_DT: C7.1, J4.11, R12.2, SW3.B
PB_SW: J4.12, R13.2, SW3.S1
RUN: J3.4, SW4.1
SCL: DS1.3, J4.3
SDA: DS1.4, J4.2
SEL_CLK: C2.1, J4.4, R5.2, SW1.A
SEL_DT: C3.1, J4.5, R6.2, SW1.B
SEL_SW: J4.6, R7.2, SW1.S1

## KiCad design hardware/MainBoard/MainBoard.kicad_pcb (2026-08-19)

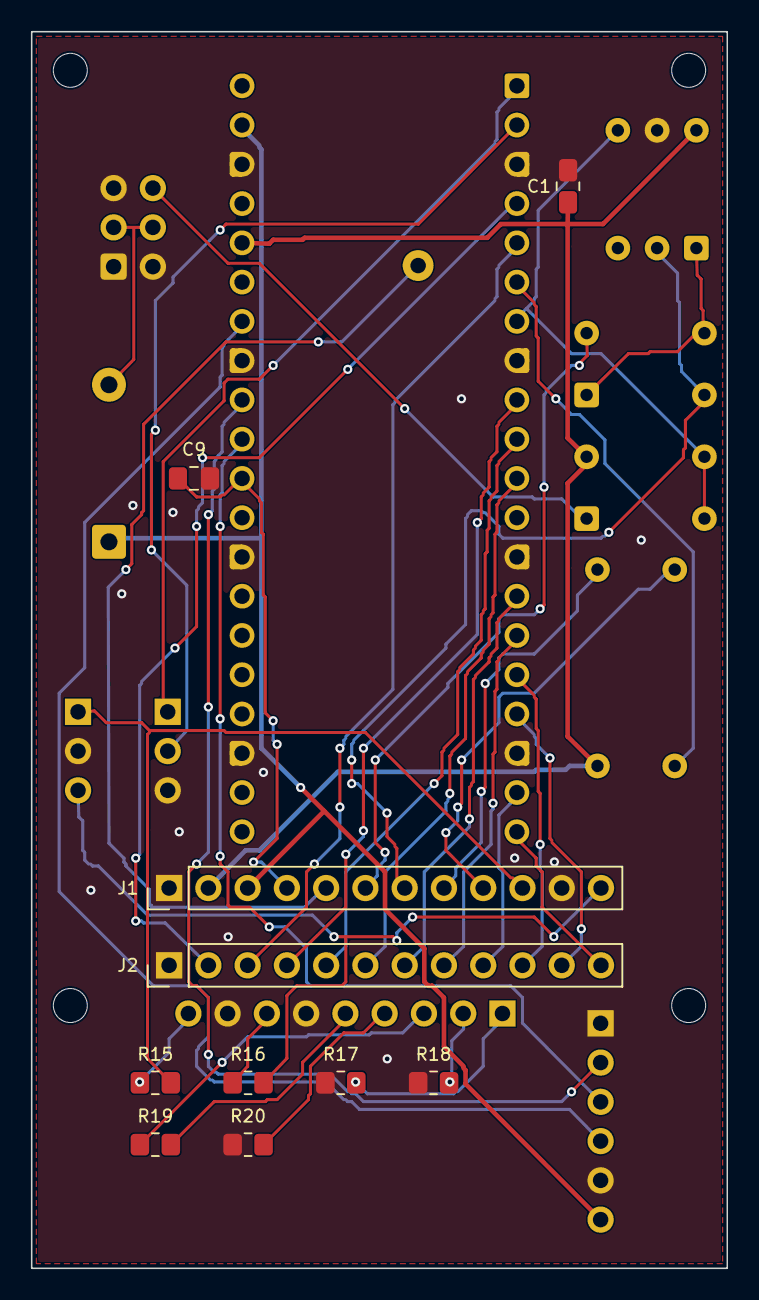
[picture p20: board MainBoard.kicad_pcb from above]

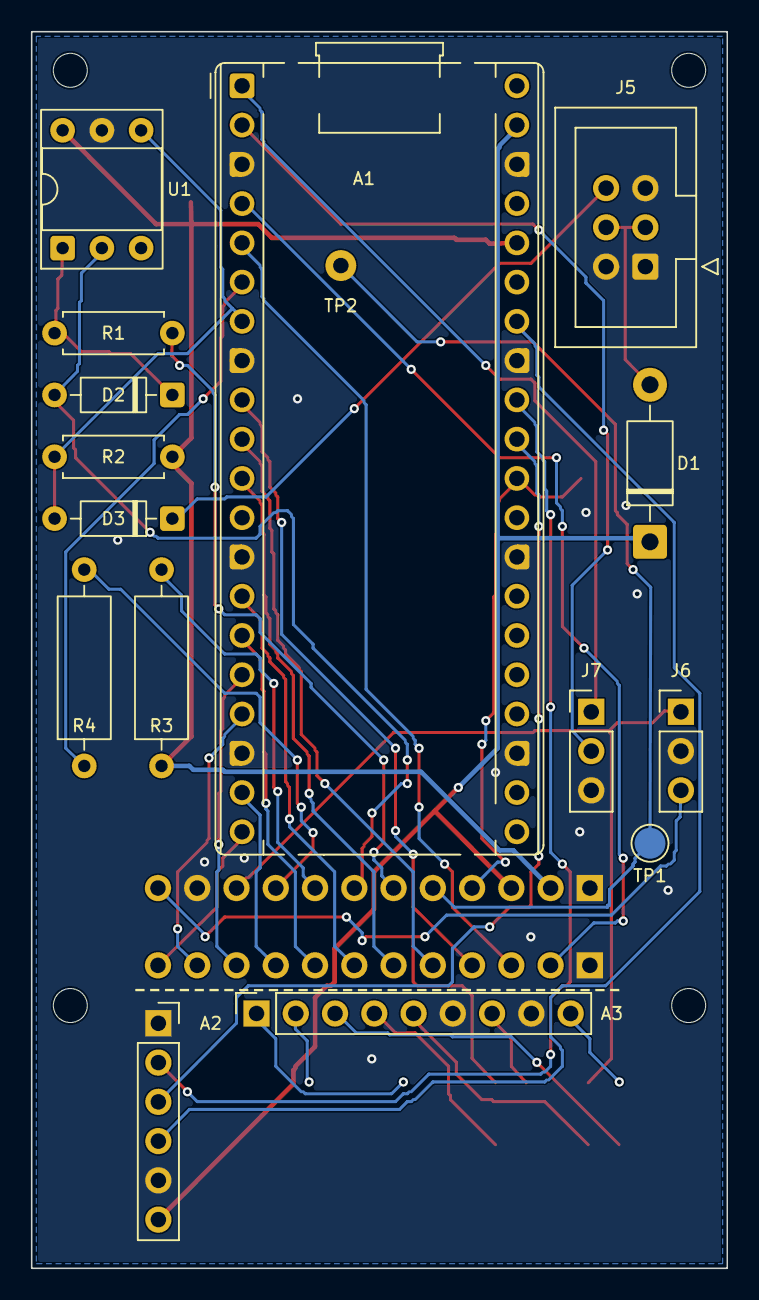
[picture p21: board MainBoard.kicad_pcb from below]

Board: 2 copper layers, 45.0 x 80.0 mm, 30 parts (16 on the bottom side), 39 nets.

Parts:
A1: Waveshare RP2350-Plus (16 MB); RaspberryPi_Pico_Common_THT
A2: GY-PCM5102 (digital row); PinSocket_1x06_P2.54mm_Vertical
A3: GY-PCM5102 (analog row); PinSocket_1x09_P2.54mm_Vertical
C1, C9: 100nF; C_0805_2012Metric_Pad1.18x1.45mm_HandSolder
D1: 1N5817; D_DO-41_SOD81_P10.16mm_Horizontal
D2: 1N4148; D_DO-35_SOD27_P7.62mm_Horizontal
D3: BAT85; D_DO-35_SOD27_P7.62mm_Horizontal
H5, H6, H7, H8: M2 board standoff; MountingHole_2.2mm_M2
J1, J2: to front board; PinHeader_1x12_P2.54mm_Vertical
J5: Bus 1 power/MIDI; IDC-Header_2x03_P2.54mm_Vertical
J6: Bus 2 audio; PinHeader_1x03_P2.54mm_Vertical
J7: DEBUG UART0; PinHeader_1x03_P2.54mm_Vertical
R1: 220R; R_Axial_DIN0207_L6.3mm_D2.5mm_P7.62mm_Horizontal
R2: 4k7; R_Axial_DIN0207_L6.3mm_D2.5mm_P7.62mm_Horizontal
R3, R4: 33R 0.5W; R_Axial_DIN0309_L9.0mm_D3.2mm_P12.70mm_Horizontal
R15, R16: 1k; R_0805_2012Metric_Pad1.20x1.40mm_HandSolder
R17, R18, R19, R20: 100k; R_0805_2012Metric_Pad1.20x1.40mm_HandSolder
TP1: BOOT; TestPoint_Pad_D2.0mm
TP2: BOOT pogo; TestPoint_THTPad_D2.0mm_Drill1.0mm
U1: H11L1; DIP-6_W7.62mm_Socket

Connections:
+3V3: A1.36, C1.1, J1.2, R2.1, R3.1, U1.6
/Main board/A3V3: A3.5, R19.2
/Main board/BUS_5V: D1.2, J5.3, J5.4
/Main board/BUS_MIDI_RX: D3.1, J5.6
/Main board/I2S_BCK: A1.32, A2.2
/Main board/I2S_DIN: A1.31, A2.3
/Main board/I2S_LRCK: A1.34, A2.4
/Main board/MIDI_RX: A1.7, D3.2, R2.2, U1.4
/Main board/MIDI_TX: A1.6, R4.1
/Main board/UART0_RX: A1.2, J7.2
/Main board/UART0_TX: A1.1, J7.1
AUDIO_L: J1.10, J6.1, R15.2
AUDIO_R: J1.12, J6.3, R16.2
BOOT: J1.5, TP1.1, TP2.1
GND: A1.3, A1.8, A1.13, A1.18, A1.23, A1.28, A1.33, A1.38, A2.1, A2.5, A3.6, A3.8, C1.2, C9.2, J1.1, J1.11, J2.1, J5.1, J5.2, J5.5, J6.2, J7.3, R17.1, R18.1, R20.1, U1.5
MIDI_IN_4: J1.6, R1.1
MIDI_IN_5: D2.2, J1.7, U1.2
MIDI_OUT_4: J1.8, R3.2
MIDI_OUT_5: J1.9, R4.2
unnamed: A3.2, R18.2
unnamed: A3.1, R17.2
unnamed: A3.4, R20.2
unnamed: A3.9, R15.1
unnamed: A3.7, R16.1
unnamed: A3.3, R19.1
unnamed: D2.1, R1.2, U1.1
PA_CLK: A1.14, J2.7
PA_DT: A1.15, J2.8
PA_SW: A1.19, J2.9
PB_CLK: A1.16, J2.10
PB_DT: A1.17, J2.11
PB_SW: A1.20, J2.12
RUN: A1.30, C9.1, J1.4
SCL: A1.5, J2.3
SDA: A1.4, J2.2
SEL_CLK: A1.9, J2.4
SEL_DT: A1.10, J2.5
SEL_SW: A1.11, J2.6
VSYS: A1.39, A2.6, D1.1, J1.3

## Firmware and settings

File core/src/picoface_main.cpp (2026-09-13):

// SPDX-License-Identifier: GPL-3.0-or-later
// SPDX-FileCopyrightText: 2026 Michi71

/**
 * Shared entry point for every instrument in the collection.
 * Brings up hardware, USB, display, audio pool, encoders and persistence,
 * then runs the audio producer loop. The instrument itself is only ever
 * reached through picoface::instrument().
 */

#include <stdio.h>
#include <string.h>

#include "pico/stdlib.h"
#include "hardware/irq.h"
#include "pico/bootrom.h"
#include "hardware/clocks.h"
#if PICO_RP2350
#include "hardware/structs/qmi.h"
#endif

#include "project_config.h"
#include "pico_hw.h"
#include "veeprom.h"
#include "get_serial.h"
#include "midi_input_usb.h"
#include "midi_output_usb.h"
#include "midi_serial.h"
#include "audio_subsystem.h"
#include "u8g2.h"
#include "encoder.h"
#include "push_button.h"
#include "picoface/instrument.h"

#if __has_include("bsp/board_api.h")
#include "bsp/board_api.h"
#else
#include "bsp/board.h"
#endif

#ifndef PICO_AUDIO_I2S_DMA_IRQ
#define PICO_AUDIO_I2S_DMA_IRQ 0
#endif

Encoder g_encSel(pio1, 0, {PIN_SEL_CLK, PIN_SEL_DT}, PIN_UNUSED, NORMAL_DIR, ROTARY_CPR, false, 444);
Encoder g_encA(pio1, 1, {PIN_PA_CLK, PIN_PA_DT}, PIN_UNUSED, NORMAL_DIR, ROTARY_CPR, false, 444);
Encoder g_encB(pio1, 2, {PIN_PB_CLK, PIN_PB_DT}, PIN_UNUSED, NORMAL_DIR, ROTARY_CPR, false, 444);
PushButton g_btSel(PIN_SEL_SW, 50);
PushButton g_btA(PIN_PA_SW, 50);
PushButton g_btB(PIN_PB_SW, 50);
static audio_buffer_pool_t* g_audio_pool = nullptr;
static u8g2_t g_u8g2;
static MIDIInputUSB g_usbmidi;
static volatile uint32_t g_pio_stall_count = 0;
picoface::ui::Display g_display(&g_u8g2);   // facade, holds only the u8g2 pointer

// One bit per half tile row, 16 in all; a set bit is a row still to be
// pushed out, 0 means idle. Display::flush() sets all of them, its ranged
// overload only the rows that changed, and the main loop pushes one row per
// pass instead of calling a blocking SendBuffer. Deliberately not static: core/src/ui/display.cpp refers to it.
uint16_t picoface_ui_flush_mask = 0;

extern "C" void __not_in_flash_func(i2s_callback_func)()
{
    // Rendering happens in the main loop; the IRQ stays deliberately tiny.
    if (!g_audio_pool) return;
    g_pio_stall_count += audio_i2s_consume_txstall();
}

// -----------------------------------------------------------------------------
// MIDI callbacks
// The MIDIInputUSB callbacks deliver the channel number as the LAST argument,
// the picoface instrument interface expects it as the FIRST - swap them here.
// -----------------------------------------------------------------------------
static void pf_note_on(uint8_t n, uint8_t v, uint8_t c)
{
    picoface::instrument().noteOn(c, n, v);
}

static void pf_note_off(uint8_t n, uint8_t v, uint8_t c)
{
    picoface::instrument().noteOff(c, n, v);
}

static void pf_cc(uint8_t cc, uint8_t v, uint8_t c)
{
    picoface::instrument().controlChange(c, cc, v);
}

static void pf_pc(uint8_t p, uint8_t c)
{
    picoface::instrument().programChange(c, p);
}

static void pf_pb(uint16_t bend14, uint8_t c)
{
    // USB delivers 14-bit offset binary 0..16383, the interface wants -8192..8191
    picoface::instrument().pitchBend(c, (int16_t)((int32_t)bend14 - 8192));
}

static void pf_at(uint8_t v, uint8_t c)
{
    picoface::instrument().channelPressure(c, v);
}

static void pf_sysex(const uint8_t* d, uint16_t len)
{
    picoface::instrument().sysEx(d, len);
}

static void pf_realtime(uint8_t status)
{
    picoface::instrument().realtime(status);
}

static void pf_activity(void)
{
    picoface::instrument().midiActivity();
}

// -----------------------------------------------------------------------------
// veeprom lock hooks
// nothing to park - the write runs on core0 between two audio blocks.
// veeprom disables the interrupts itself and restores the QMI flash timing
// afterwards.
// -----------------------------------------------------------------------------
static bool pf_flash_lock(void) { return true; }
static void pf_flash_unlock(void) {}

// -----------------------------------------------------------------------------
// long-press detection and input capture
// -----------------------------------------------------------------------------
static constexpr uint32_t PF_LONG_PRESS_MS = 600;
static uint32_t g_btDownSince[picoface::ui::kButtonCount] = {0, 0, 0};
static bool     g_btLongFired[picoface::ui::kButtonCount] = {false, false, false};

static void pf_build_input(picoface::ui::InputState& in, uint32_t nowMs)
{
    in.nowMs = nowMs;
    // pot is not wired on every board; instruments that use it read it themselves for now
    in.pot = 0;

    PushButton* buttons[3]  = {&g_btSel, &g_btA, &g_btB};
    Encoder*    encoders[3] = {&g_encSel, &g_encA, &g_encB};

    for (int i = 0; i < 3; ++i) {
        in.encoderDelta[i] = (int8_t)encoders[i]->delta();

        bool toggled = buttons[i]->Toggled();
        bool down    = (buttons[i]->ReadButton() == PushButton::PRESSED);

        in.buttonDown[i] = down;
        // Toggled() fires on both edges, so the level is checked too -
        // otherwise releasing would trigger a second event
        in.buttonPressed[i]   = (toggled && down);
        in.buttonLongPress[i] = false;

        if (down && g_btDownSince[i] == 0) {
            g_btDownSince[i] = nowMs;
            g_btLongFired[i] = false;
        }
        if (down && !g_btLongFired[i] && (nowMs - g_btDownSince[i]) >= PF_LONG_PRESS_MS) {
            in.buttonLongPress[i] = true;
            g_btLongFired[i]      = true;
        }
        if (!down) {
            g_btDownSince[i] = 0;
            g_btLongFired[i] = false;
        }
    }
}

// -----------------------------------------------------------------------------
// firmware update: into the UF2 bootloader from the panel
// -----------------------------------------------------------------------------
// Ten firmware images share one board, so choosing a different instrument is
// something a user does, not something a factory does once. That makes the
// route into the bootloader part of the interface, and it belongs here rather
// than in a menu: a menu entry would have to be added to all ten instruments,
// while the core already owns the buttons and the display.
//
// The gesture is all three encoder buttons together. No instrument uses that
// combination -- they read single presses and long presses -- and it cannot be
// reached by resting a hand on one knob. After half a second the core takes the
// screen and counts down, so nothing happens invisibly and letting go cancels.
//
// Two details worth knowing:
//
//   The audio pipeline is drained before the jump. All-sound-off is sent first
//   and the main loop keeps rendering for a further 150 ms, so the five buffers
//   already queued in the DMA play out silent. Jumping straight away would
//   leave whatever was queued mid-note in the DAC as the clock stops.
//
//   reset_usb_boot's first argument is a GPIO mask for a USB activity LED, and
//   passing PIN_LED here would be the obvious thing to do. It is deliberately 0:
//   on RP2350 A2 silicon the SDK works around an activity-LED bug by rebooting
//   into RISC-V mode when a LED is named (see PICO_BOOTROM_WORKAROUND_RP2350_
//   A2_ACTIVITY_LED_BUG), which is not what anyone wants from a firmware
//   update. No LED, no workaround, Arm bootloader.
//
// Settings are NOT written on the way out. A flash write stalls execution and
// this is not a normal shutdown; the debounced save in the main loop has had
// two seconds of idle to run long before anyone holds three buttons down.
static constexpr uint32_t PF_FW_ARM_MS   = 500;    // core takes the screen
static constexpr uint32_t PF_FW_HOLD_MS  = 2500;   // committed
static constexpr uint32_t PF_FW_DRAIN_MS = 150;    // silence reaches the DAC
static uint32_t g_fwHoldSince = 0;
static uint32_t g_fwCommitted = 0;
static int32_t  g_fwShown     = -1;                // last second drawn

// Returns true while the core owns the display, so the caller skips uiTick.
static bool pf_firmware_update(picoface::Instrument& inst,
                               const picoface::ui::InputState& in,
                               uint32_t nowMs)
{
    if (g_fwCommitted) {
        if ((nowMs - g_fwCommitted) >= PF_FW_DRAIN_MS) reset_usb_boot(0, 0);
        return true;                                  // never returns from that
    }

    const bool all = in.buttonDown[0] && in.buttonDown[1] && in.buttonDown[2];
    if (!all) { g_fwHoldSince = 0; g_fwShown = -1; return false; }
    if (g_fwHoldSince == 0) { g_fwHoldSince = nowMs; return false; }

    const uint32_t held = nowMs - g_fwHoldSince;
    if (held < PF_FW_ARM_MS) return false;

    if (held < PF_FW_HOLD_MS) {
        // Redraw only when the digit changes -- three times, not once every
        // 20 ms. The countdown goes out through the incremental flush like
        // everything else, because a blocking full-buffer transfer costs more
        // than the audio lead has (see section 2 of the main loop) and two and
        // a half seconds of stutter is a poor thing to hand someone who is
        // about to let go and cancel.
        const int32_t left = (int32_t)((PF_FW_HOLD_MS - held + 999) / 1000);
        if (left != g_fwShown) {
            g_fwShown = left;
            char line[16];
            snprintf(line, sizeof line, "%ld", (long)left);
            g_display.clear();
            g_display.setFont(u8g2_font_7x13B_tf);
            g_display.drawTextCentered(20, "FIRMWARE");
            g_display.drawTextCentered(42, line);
            g_display.setFont(u8g2_font_6x10_tf);
            g_display.drawTextCentered(58, "let go to cancel");
            g_display.flush();
        }
        return true;
    }

    // Committed: silence every channel, say so, and let the loop drain the
    // queued buffers. Here the blocking transfer is right -- the audio is
    // deliberately over, and the message has to be on the glass before the
    // chip resets.
    for (uint8_t ch = 0; ch < 16; ++ch) inst.controlChange(ch, 120, 0);
    u8g2_ClearBuffer(&g_u8g2);
    u8g2_SetFont(&g_u8g2, u8g2_font_7x13B_tf);
    u8g2_DrawStr(&g_u8g2, (128 - u8g2_GetStrWidth(&g_u8g2, "BOOTLOADER")) / 2, 28, "BOOTLOADER");
    u8g2_SetFont(&g_u8g2, u8g2_font_6x10_tf);
    u8g2_DrawStr(&g_u8g2, (128 - u8g2_GetStrWidth(&g_u8g2, "drop a .uf2 on it")) / 2, 46,
                 "drop a .uf2 on it");
    u8g2_SendBuffer(&g_u8g2);
    g_fwCommitted = nowMs;
    return true;
}

#if PICOFACE_BOOT_DIAG && PICO_RP2350
// Eight lines of 5x7 text, scrolling; each call redraws and flushes. The I2C
// baud is re-derived on every call because the stages straddle the clk_sys
// change, and a divider computed at 150 MHz is three times too fast at 444.
static void pf_boot_diag_line(const char *line)
{
    static char lines[8][26];
    static int  n = 0;
    if (n == 8) { memmove(lines[0], lines[1], sizeof lines - sizeof lines[0]); n = 7; }
    snprintf(lines[n++], sizeof lines[0], "%s", line);
    i2c_set_baudrate(i2c1, PICOFACE_OLED_I2C_HZ);
    u8g2_ClearBuffer(&g_u8g2);
    u8g2_SetFont(&g_u8g2, u8g2_font_5x7_tf);
    for (int i = 0; i < n; i++) u8g2_DrawStr(&g_u8g2, 0, 7 + 8 * i, lines[i]);
    u8g2_SendBuffer(&g_u8g2);
}
#endif

int main(void)
{
    // bring up the chip basics before anything else
#if PICOFACE_BOOT_DIAG && PICO_RP2350
    // Boot diagnostics: the display first, at the bootrom's clock and flash
    // timing, before pico_init() changes any of it. The header is what the
    // bootrom left behind; pico_init() then appends one line per stage. On a
    // board that never reaches the splash, the last line on the screen is the
    // stage it did not survive.
    u8g2_Setup_sh1106_i2c_128x64_noname_f(&g_u8g2, U8G2_R0, u8x8_byte_pico_hw_i2c, u8x8_gpio_and_delay_pico);
    u8g2_InitDisplay(&g_u8g2);
    u8g2_SetPowerSave(&g_u8g2, 0);
    {
        char l[26];
        snprintf(l, sizeof l, "DIAG A%u b%u %s", (unsigned)rp2350_chip_version(),
                 (unsigned)rp2350_rom_version(), PICOFACE_VERSION);
        pf_boot_diag_line(l);
        snprintf(l, sizeof l, "T %08x", (unsigned)qmi_hw->m[0].timing);
        pf_boot_diag_line(l);
        snprintf(l, sizeof l, "F %08x", (unsigned)qmi_hw->m[0].rfmt);
        pf_boot_diag_line(l);
        snprintf(l, sizeof l, "C %08x", (unsigned)qmi_hw->m[0].rcmd);
        pf_boot_diag_line(l);
    }
    picoface_boot_diag = pf_boot_diag_line;
#endif
    pico_init();
#if PICOFACE_BOOT_DIAG && PICO_RP2350
    pf_boot_diag_line("init done");
    // Leave it readable: the normal splash below would overwrite it.
    for (int i = 0; i < 4000; i++) sleep_ms(1);
#endif

    // grab the singleton instrument
    picoface::Instrument& inst = picoface::instrument();

    // Installed before init(), so an instrument may already use the veeprom
    // while starting up.
    veeprom_set_lock_hooks(pf_flash_lock, pf_flash_unlock);
    // Before the scan: it decides which records this instrument may see at all.
    veeprom_set_instrument(inst.name());
    veeprom_init();

    inst.init();   // engine first - it determines its own sample rate

    // board, serial and USB stack
    board_init();
    usb_serial_init();
    tusb_init();

    // display setup (SH1106, 128x64, I2C)
    u8g2_Setup_sh1106_i2c_128x64_noname_f(&g_u8g2, U8G2_R0, u8x8_byte_pico_hw_i2c, u8x8_gpio_and_delay_pico);
    u8g2_InitDisplay(&g_u8g2);
    u8g2_SetPowerSave(&g_u8g2, 0);
    u8g2_ClearBuffer(&g_u8g2);

    // splash screen: instrument name and firmware version, both centered
    const char* name = inst.name();
    u8g2_SetFont(&g_u8g2, u8g2_font_7x13B_tf);
    u8g2_DrawStr(&g_u8g2, (128 - u8g2_GetStrWidth(&g_u8g2, name)) / 2, 28, name);
    u8g2_SetFont(&g_u8g2, u8g2_font_6x10_tf);
    u8g2_DrawStr(&g_u8g2, (128 - u8g2_GetStrWidth(&g_u8g2, PICOFACE_VERSION)) / 2, 44, PICOFACE_VERSION);

    // Bottom line: which silicon this is, and the flash clock actually in force.
    // Both come up in bug reports (issue #107 turned on exactly this pair) and
    // neither is otherwise readable: picotool does not report the stepping, and
    // the flash timing is a compile-time choice with a runtime fallback -- if
    // set_sys_clock_hz() misses its target the boot keeps the slack timing, so
    // only the register knows what is really running. Read it, do not assume it.
#if PICO_RP2350
    {
        // CLKDIV encodes the SCK period in system clock cycles; 0 means 256.
        const uint32_t clkdivRaw = qmi_hw->m[0].timing & QMI_M0_TIMING_CLKDIV_BITS;
        const uint32_t clkdiv = clkdivRaw ? clkdivRaw : 256u;
        const uint32_t sysHz    = clock_get_hz(clk_sys);
        const uint32_t coreMHz  = (sysHz + 500000u) / 1000000u;
        const uint32_t flashMHz = (sysHz / clkdiv + 500000u) / 1000000u;
        char hw[32];
        // Q or D/S: whether the bootrom got the flash into quad mode. On a
        // board where it did not, the whole fast-timing path is skipped and
        // the flash keeps the bootrom's own (much slower) clock -- so this
        // letter and that number together say why an instrument feels slow.
        // RXDELAY too: it is the other half of the flash timing, it is the one
        // parameter two builds can differ in while showing the same SCK, and
        // without it an A/B of two timings is unreadable at the device.
        const uint32_t rxdelay =
            (qmi_hw->m[0].timing & QMI_M0_TIMING_RXDELAY_BITS) >> QMI_M0_TIMING_RXDELAY_LSB;
        // The core clock leads: it is what set_sys_clock_hz() may silently have
        // failed to reach (the flash figure is derived from it and would then
        // be misread as a flash problem), and it is the parameter the #107
        // board is suspected on. Reading "core/flash" also makes a set of
        // images that differ only in clock target tellable apart at the device.
        //
        // "b" is the bootrom revision (2/3/4 for A2/A3/A4), read from the ROM
        // itself. The stepping letter comes from CHIP_ID, and A4 is by the
        // datasheet a bootrom-only revision on unchanged silicon: the datasheet
        // gives it REVISION 0x8, yet a chip marked A0A4 in #107 reported A3.
        // The ROM byte does not depend on that mapping, so the two together
        // say what the marking on the package actually corresponds to.
        snprintf(hw, sizeof hw, "A%u b%u %c %u/%u r%u", (unsigned)rp2350_chip_version(),
                 (unsigned)rp2350_rom_version(),
                 picoface_flash_is_quad ? 'Q' : 'D', (unsigned)coreMHz,
                 (unsigned)flashMHz, (unsigned)rxdelay);
        u8g2_SetFont(&g_u8g2, u8g2_font_5x7_tf);
        u8g2_DrawStr(&g_u8g2, (128 - u8g2_GetStrWidth(&g_u8g2, hw)) / 2, 60, hw);
    }
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

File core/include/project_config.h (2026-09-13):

// SPDX-License-Identifier: GPL-3.0-or-later
// SPDX-FileCopyrightText: 2026 Michi71

// project_config.h - the PicoFace hardware platform.
//
// One board for every instrument: pin map and flash timing live here in
// the core, not per instrument. Every pin below was already identical in all
// original repositories; only comments and one extra timing constant
// differed, which is why this used to be copied once per instrument.
#ifndef __PROJECT_CONFIG_H__
#define __PROJECT_CONFIG_H__

// DIN MIDI on uart1, behind the opto-coupler on the board. uart0 (GPIO 0/1)
// stays reserved for stdio, so the two never collide.
#define PIN_MIDI_RX 5
#define PIN_MIDI_TX 4

// Pimoroni Pico Audio
//#define PIN_I2S_DOUT  9
//#define PIN_I2S_BCK   10
//#define PIN_I2S_WS    11

// Waveshare Pico Audio
#define PIN_I2S_DOUT  26
#define PIN_I2S_BCK   27
#define PIN_I2S_WS    28

#define  PIN_LED	  25

#define PIN_OLED_SDA  2
#define PIN_OLED_SCL  3

// OLED bus speed. 1 MHz is Fast-mode Plus, and it is what the reference board
// runs: the display push is paced in half tile rows of roughly 1.5 ms of I2C
// each, so the rate is directly the UI's frame time -- 400 kHz would make a
// full screen 60 ms instead of 24.
//
// It is also above what an SH1106 datasheet promises (400 kHz), and the only
// pull-ups are the chip's internal ones at around 50 kOhm. On the short, tidy
// wiring of the prototype that is fine and has been for every board tested
// here. On longer jumper leads it is the first thing to suspect when a panel
// stays dark while the instrument is otherwise alive -- drop it to 400000 and
// see. Worth adding real 2.2k-4.7k pull-ups before blaming the display.
#ifndef PICOFACE_OLED_I2C_HZ
#define PICOFACE_OLED_I2C_HZ (1000 * 1000)
#endif

//#define PIN_POT_0     28
#define PIN_POT_1     29

// Encoder pins.
//
// CLK and DT are swapped against the GPIO order, and deliberately so: on the
// board under hardware/ the A and B contacts of all three EC11s reach the RP2350
// this way round, and that board is the reference hardware - it is in
// production, and the firmware is built to match it (v1.19.0 on).
//
// Builds from before that board - the prototypes and protoboards wired the
// other way round - count down when turned clockwise from v1.19.0 on (#161).
// That is by decision, not by accident: one firmware, one wiring, and an older
// build swaps its two encoder wires rather than the firmware carrying a
// variant for it. Do not add REVERSED_DIR, a build option or a second default
// for this.
//
// The swap is in the pin numbers rather than in the driver. Encoder takes a
// Direction (NORMAL_DIR / REVERSED_DIR) which would produce the same counts,
// but that would describe the wiring as correct and the counting as backwards.
// It is the other way round: these two names say which GPIO carries which
// contact, and on this board that is 7 and 6, not 6 and 7. The PIO watches the
// two pins independently (jmp_pin for A, in_pins for B - see
// lib/encoder/piosrc/encoder.pio, "do not need to be consecutive"), so any
// pairing works.

// Selector encoder
#define PIN_SEL_CLK   7
#define PIN_SEL_DT    6
#define PIN_SEL_SW    8

// Param A encoder
#define PIN_PA_CLK    11
#define PIN_PA_DT     10
#define PIN_PA_SW     14   // optional switch

// Param B encoder
#define PIN_PB_CLK    13
#define PIN_PB_DT     12
#define PIN_PB_SW     15   // optional switch
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

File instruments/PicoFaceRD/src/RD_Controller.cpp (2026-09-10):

// SPDX-License-Identifier: GPL-3.0-or-later
// SPDX-FileCopyrightText: 2026 Michi71

#include "RD_Controller.h"
#include "rd_cc_map.h"
#include "midi_serial.h"

// RD_Controller shadow array holds UI units:
//   - continuous params: percent 0..100
//   - toggle params: 0/1
// The single wire-conversion point is toWire()/sendParam() at send time.
// Engine bridge normalizes wire value /255 with >=0.5 == ON, so toggles
// MUST be sent as 0 or 255 and percent maps 0->0, 100->255 via (v*255+50)/100.

// Default parameter shadow values.
// UI units: percent 0..100; toggles 0/1.
static constexpr uint8_t kDefVolume       = 80;
static constexpr uint8_t kDefChorusOn     = 0;
static constexpr uint8_t kDefChorusRate   = 50;   // grid index: 2.50 Hz (was 40 % = 2.51 Hz)
static constexpr uint8_t kDefChorusDepth  = 50;
static constexpr uint8_t kDefTremOn       = 0;
static constexpr uint8_t kDefTremRate     = 82;   // grid index: 4.10 Hz (was 50 % = 4.09 Hz)
static constexpr uint8_t kDefTremDepth    = 50;
static constexpr uint8_t kDefBass         = 50;
static constexpr uint8_t kDefTreble       = 50;
static constexpr uint8_t kDefDacFilterOn  = 1;
static constexpr uint8_t kDefPhaserOn      = 0;
static constexpr uint8_t kDefPhaserRate    = 14;  // grid index: 0.70 Hz (was 50 % of an exponential = 0.71 Hz)
static constexpr uint8_t kDefPhaserDepth   = 50;

// Step a percent value by delta (1% per detent), clamped to 0..100.
static uint8_t stepPct(uint8_t v, int delta) {
    int n = (int)v + delta;
    if (n < 0) n = 0;
    if (n > 100) n = 100;
    return (uint8_t)n;
}

// True for toggle params (stored as 0/1 in shadow).
static bool isToggleParam(uint8_t id) {
    return id == RD_PARAM_CHORUS_ON ||
           id == RD_PARAM_TREM_ON ||
           id == RD_PARAM_PHASER_ON ||
           id == RD_PARAM_DAC_FILTER_ON;
}

// Convert UI value to engine wire format (0..255).
// Toggles: 0/1 -> 0/255. Percent -> (v*255+50)/100 so 0->0, 100->255.
// Bridge normalizes wire/255 and treats >=0.5 as ON.
static uint8_t toWire(uint8_t id, uint8_t v) {
    if (isToggleParam(id)) {
        return v ? 255 : 0;
    }
    if (rd_is_rate_param(id)) {
        // Rates are stored as a 0.05 Hz grid index, not a percent. Map the
        // index across its own range so the engine's law lands on the same
        // frequency the display prints.
        const int lo = (int)rd_rate_idx_min(id);
        const int hi = (int)rd_rate_idx_max(id);
        int n = (int)v; if (n < lo) n = lo; if (n > hi) n = hi;
        return (uint8_t)(((n - lo) * 255 + (hi - lo) / 2) / (hi - lo));
    }
    return (uint8_t)(((int)v * 255 + 50) / 100);
}

// One encoder detent = one grid position = exactly 0.05 Hz.
static uint8_t stepRate(uint8_t id, uint8_t v, int delta) {
    const int lo = (int)rd_rate_idx_min(id);
    const int hi = (int)rd_rate_idx_max(id);
    int n = (int)v + delta;
    if (n < lo) n = lo;
    if (n > hi) n = hi;
    return (uint8_t)n;
}

// Send a shadow UI value to the engine, converting to wire format.
// Transmit channel for the panel mirror, kept in step with midiCh_.
static uint8_t s_txChannel = 0;

static void sendParam(uint8_t id, uint8_t uiVal) {
    ipc_send_dx_param(id, toWire(id, uiVal));

    // Mirror the edit as a Control Change, the way the reface instruments do.
    // Only the encoder handlers reach this function; importSettings() sends
    // directly, so a restore at boot stays silent.
    if (id >= RD_PARAM_COUNT) return;
    const uint8_t cc = kRdCc[id];
    if (cc == RD_CC_NONE) return;
    // UI units are percent 0..100 for continuous params, 0/1 for toggles.
    const uint8_t val = isToggleParam(id) ? (uiVal ? 127 : 0)
                                          : (uint8_t)(((int)uiVal * 127 + 50) / 100);
    midiSerial().sendControlChange(s_txChannel, cc, val);
}

// Page name table.
static const char *const kPageNames[(int)RdPage::COUNT] = {
    "PATCH", "CHORUS", "TREMOLO", "PHASER", "EQ", "VOICES", "TUNE", "SYS",
    "DIAG",
};

RD_Controller::RD_Controller(RD_Midi &midi)
    : midi_(midi)
{
    page_ = RdPage::PATCH;
    instrument_ = 0;
    midiCh_ = 16; // Omni by default (matches RD_MIDI_OMNI)

    for (uint16_t i = 0; i < RD_PARAM_COUNT; ++i) shadow_[i] = 0;

    shadow_[RD_PARAM_VOLUME]        = kDefVolume;
    shadow_[RD_PARAM_CHORUS_ON]     = kDefChorusOn;
    shadow_[RD_PARAM_CHORUS_RATE]   = kDefChorusRate;
    shadow_[RD_PARAM_CHORUS_DEPTH]  = kDefChorusDepth;
    shadow_[RD_PARAM_TREM_ON]       = kDefTremOn;
    shadow_[RD_PARAM_TREM_RATE]     = kDefTremRate;
    shadow_[RD_PARAM_TREM_DEPTH]    = kDefTremDepth;
    shadow_[RD_PARAM_BASS]          = kDefBass;
    shadow_[RD_PARAM_TREBLE]        = kDefTreble;
    shadow_[RD_PARAM_DAC_FILTER_ON] = kDefDacFilterOn;
    shadow_[RD_PARAM_PHASER_ON]      = kDefPhaserOn;
    shadow_[RD_PARAM_PHASER_RATE]    = kDefPhaserRate;
    shadow_[RD_PARAM_PHASER_DEPTH]   = kDefPhaserDepth;
}

RdPage RD_Controller::advancePage(RdPage current, int delta) {
    int n = static_cast<int>(current) + delta;
    int m = static_cast<int>(RdPage::COUNT);
    // Positive modulo, handles negative inputs.
    n %= m;
    if (n < 0) n += m;
    return static_cast<RdPage>(n);
}

void RD_Controller::onEncoder1(int delta) {
    page_ = advancePage(page_, delta);
}
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

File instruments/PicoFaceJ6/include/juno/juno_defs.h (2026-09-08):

// SPDX-License-Identifier: GPL-3.0-or-later
// SPDX-FileCopyrightText: 2026 Michi71

/*
  PicoFaceJ6 -- Roland Juno-60

  Built from three sources, and where they disagree the order of precedence is
  stated at the value:

    doc/Roland Juno-60 Service Notes ( HI-RES ).pdf
        The specifications page and the schematics. Component values and IC
        types come from here and nothing overrides them.

    doc/PG-JU60_Manual_eng_05_W.pdf
        What the controls are called and what they are meant to do.

    https://github.com/pendragon-andyh/Juno60
        Measurements taken off a real instrument -- envelope times and slopes,
        chorus rates and delay ranges, HPF corner frequencies. Where a
        measurement contradicts the specification, the measurement wins and
        both numbers are recorded.

    https://github.com/dzannotti/junox
        Structure and parameter scaling. Two places where it is not followed
        are marked in the code: its DCO quantises the period to whole audio
        samples, which is not what the instrument does, and its filter is a
        diode ladder, which is not what an IR3109 is.

  Signal flow (service notes, block diagram, page 3):

    MASTER OSC -> DCO x6 -> WAVEFORM -> VCF x6 (IR3109) -> VCA x6 (BA662)
      -> SUM -> HPF (switched, one for all voices) -> VCA (patch level)
      -> CHORUS (2x MN3009 BBD) -> VOLUME -> output

  Two details of that chain are easy to get wrong and are worth stating:
  the high-pass filter sits after the voices are summed, not in each voice,
  and the patch's VCA level sits *before* the chorus, so a loud patch drives
  the bucket-brigade lines harder and distorts them more.
*/

#ifndef JUNO_DEFS_H
#define JUNO_DEFS_H

#include <stdint.h>
#include <stddef.h>

/* ------------------------------------------------------------------------   */
/* Host/target switch (same approach as the rest of the family)               */
/* ------------------------------------------------------------------------   */
#ifdef JUNO_HOST_BUILD
#ifndef PICO_AUDIO_I2S_BUFFERS_PER_CHANNEL
#define PICO_AUDIO_I2S_BUFFERS_PER_CHANNEL 3
#endif
#ifndef SAMPLES_PER_BUFFER
#define SAMPLES_PER_BUFFER 16
#endif
#else
#include "audio_subsystem.h"
#endif

#define I2S_BUFFERS         PICO_AUDIO_I2S_BUFFERS_PER_CHANNEL
#define I2S_BUFFER_WORDS    SAMPLES_PER_BUFFER
#define SAMPLING_RATE       (44100)

#define JUNO_BLOCK          I2S_BUFFER_WORDS

/* ------------------------------------------------------------------------   */
/* Oversampling                                                               */
/*                                                                            */
/* Six voices cost six times what one does, so this matters far more here     */
/* than it did for the Model D, and it is the one number worth getting right   */
/* before anything else.                                                      */
/*                                                                            */
/* Measured on this engine, scaled against the load PicoFaceMD reports on the  */
/* device (its dry engine is 0.185 % of one host core and P21 on the RP2350):  */
/*                                                                            */
/*     1x   fixed P8, P6.2 per voice, chorus P2   -> six voices P48            */
/*     2x   fixed P10, P10 per voice, chorus P2   -> six voices P72            */
/*                                                                            */
/* A prototype written before the engine predicted P42 and P59. It was too     */
/* optimistic by 13 points at 2x, so the earlier conclusion that one core is   */
/* comfortable at 2x does not survive its own measurement: P72 leaves only a   */
/* quarter of the core for USB, MIDI and pushing the display out.              */
/*                                                                            */
/* Aliasing, one voice, sawtooth, filter wide open and no resonance -- the     */
/* only configuration that can be measured honestly, since a resonant peak     */
/* below the fundamental is not at a harmonic and swamps the figure:           */
/*                                                                            */
/*     1x  -45.2 dB     2x  -55.4 dB     4x  -53.7 dB                          */
/*                                                                            */
/* So 2x buys 10 dB and 4x buys nothing, the same shape of result as the       */
/* Model D. 1x is the default because it fits one core with room to spare;     */
/* going to 2x means either living at P72 or splitting the voices over both    */
/* cores the way PicoFaceRD does.                                             */
/* ------------------------------------------------------------------------   */
#ifndef JUNO_OVERSAMPLE
#define JUNO_OVERSAMPLE 1
#endif

#define JUNO_DECIMATE_HZ 15000.0f
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

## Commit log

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2026-08-04 Add DIN MIDI on uart1: receive on all six, transmit on four
    New core module midi_serial (core/include/midi_serial.h,
    core/src/midi_serial.cpp). Its callback signatures are deliberately identical
    to MIDIInputUSB, so both transports feed the very same dispatch functions and
    an instrument never sees which wire an event arrived on.
    Hardware: uart1, RX on GPIO 5 (PIN_MIDI_RX, already reserved), TX on GPIO 4
    (new PIN_MIDI_TX, the matching uart1 pin and the only free one). stdio stays
    on uart0/GPIO 0-1, so the two never collide.
    Receive is interrupt driven into a 256-byte lock-free ring. Polling would be
    too fragile: at 31250 baud a byte lands every 320 us and the 32-byte hardware
    FIFO gives only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
    [J6_Controller.cpp, MD_Controller.cpp, midi_serial.cpp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]
2026-08-04 Panel-as-CC for PicoFaceSM and PicoFaceRD
    Both instruments now mirror panel edits as Control Changes and accept the same
    controllers back, closing the last gap from the DIN MIDI commit.
    Neither brought a parameter-to-CC assignment with it - the Solina is purely
    electromechanical in the original, and the RD answers to sustain plus a few
    mode messages. The tables in instruments/PicoFaceSM/include/sm_cc_map.h and
    instruments/PicoFaceRD/include/rd_cc_map.h are therefore this project's
    decision. Each table serves both directions, so send and receive cannot drift
    apart.
    Assignment follows three rules: standard sound controllers where the function
    genuinely matches (72 release, 73 attack, 74 brig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
    [RD_Controller.cpp, SM_Controller.cpp]
2026-08-04 Move PicoFaceYC to the standard runtime model
    PicoFaceYC was one of two instruments whose UI ran on core1 while core0
    stayed a pure audio master. pico_UserInterfaceFrontPanel() contained
    for(;;) and never returned - it *was* the core1 loop - and ipc.h pushed
    over the SIO FIFO with multicore_fifo_push_blocking(), which would block
    forever once producer and consumer share a core. IPC, UI and adapter had
    to move together; there was no working intermediate state.
    - ipc.h: same-core SPSC ring modelled on md_ipc.h, drained at the top of
    render(). The ipc_send_yc_* signatures are unchanged, so YC_Controller
    and midi_reface need no edit. Flash-lock command dropped.
    - YC_Ui replaces pico_frontpa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
    [picoface_main.cpp]
2026-08-04 Drop the second runtime model
    With PicoFaceYC and PicoFaceCP converted and confirmed on hardware, no
    instrument returns true from ownsUserInterface() any more. The contract
    loses five methods - ownsUserInterface, runUserInterface, pumpCrossCore,
    flashLockHook, flashUnlockHook - and picoface_main.cpp loses the branch
    that launched core1, skipped display and encoder setup, and idled the
    producer on __wfe.
    An instrument that wants core1 launches it from its own adapter, as
    PicoFaceRD has always done for its voice worker.
    The veeprom lock hooks stay: all six install no-ops today, but the guard
    belongs to the flash layer and would be needed by an instrument whose core1
    worker is not RAM-residen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
    [picoface_main.cpp]
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2026-08-07 PicoFaceJV: an opt-in build that fits a 4 MB Pico 2
    The full instrument is 4.33 MB of flash and needs a 16 MB board. Most
    people who would like to try it own a base Pico 2.
    -DPICOFACEJV_4MB=ON builds a 3.76 MB image. It keeps banks A and B --
    128 patches -- and drops the user bank. Nothing is resampled,
    requantised or shortened: the samples those banks reach are relocated
    into a shorter blob and the sample table is rewritten to match, so all
    128 patches render bit-identically to the full build.
    Where the 0.57 MB comes from, largest first: the user bank's own 22
    samples, the 39 samples no patch of any bank references at all (the ROM
    also serves the rhythm sets, which this instrument does no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
    [JV_Controller.cpp]
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2026-08-07 PicoFaceMD: the ladder must not be asked for cutoffs past one radian
    The Huovilainen fits in the ladder are only good to about one radian per
    sample. The resonance one does not merely lose accuracy past that -- it
    crosses zero at wc = 1.085 and goes negative, which turns the feedback
    around the loop from negative into positive. The tanh at the input keeps
    that bounded, so nothing overflows, but the stage then sits pinned
    against its own saturation and a filtered note comes out as a crushed
    square. Further up the tuning fit passes 1.0 as well and the one pole
    sections overshoot on every step.
    The old ceiling of 0.49 of the sample rate let all of that happen: at the
    88.2 kHz the filter runs a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
    [moog_defs.h]
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2026-08-08 Core: let a queued MIDI dump take priority over the display flush
    Not a bug fix - the editor problem this was first written against turned out
    to be Soundmondo's, see the commit before this one. It stays because it is
    right on its own: the display flush spends about 1.5 ms of I2C per main loop
    pass, and the transmit queue is topped up once per pass, so a voice dump was
    paced at one TinyUSB FIFO per 1.5 ms - some 9 ms for 241 bytes where USB
    itself would deliver them in about four 1 ms frames. An editor waiting on a
    voice sees those gaps; the display catching up a few milliseconds later is
    invisible.
    So the flush now stands aside while the queue is non-empty. Ran on hardware
    (WeAct RP2350A,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
    [picoface_main.cpp]
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2026-08-08 veeprom: a record belongs to the instrument that wrote it
    Issue #18: PicoFaceJ6 and PicoFaceSM start silent and stay silent until a
    program change. Only one reporter sees it, and that reporter flashes every
    instrument onto the same board.
    The store sits at a fixed address at the top of flash and a .uf2 does not
    erase it, so the previous instrument's record survives the reflash. The
    header carries a schema version but no instrument, and those versions
    collide: J6, SM and DX all reached version 3 independently. The core's load
    check accepts a record whose version matches and whose length is at least
    what the instrument needs, so J6's 72 bytes satisfied SM's 54 and SM read
    J6's programme numbe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
    [picoface_main.cpp]
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2026-08-11 PicoFaceD5: the instrument -- tenth in the collection, and it builds
    Bridge, controller, display, MIDI front end and the picoface::Instrument
    adapter, following the JV's shape: three encoder pages (patch,
    mix, tune), the house-style display with the load/underrun/voices
    footer, settings through veeprom, and the underrun governor that sheds
    voices and gives them back after a second of quiet. USB PID 0x1059.
    Writing it surfaced three things the engine was missing, all of them
    real D-50 parameters or real faults:
    - continuous fine tune. Master tune is in cents and the engine only
    took note numbers, so it gained WG Pitch Fine per partial plus the
    instrument's own offset.
    - pitch bend that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
    [D5_Controller.cpp]
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2026-08-13 PicoFaceD5: the hand leans into the keys, and four lanes answer
    Channel pressure (0xD0) finally arrives where the D-50 heard it: the core
    stops dropping the message (serial dispatch case 0xD0, USB-MIDI CIN 0xD,
    a channelPressure virtual on the instrument interface, both transports
    wired through pf_at) and the engine speaks it in all four of the
    firmware's lanes, taken from the mask ROM and the bank code:
    - P-Mod aftertouch (common c[24]) is the second lever: kPModCurve[c24]*AT
    enters the vibrato depth additively beside CC1, under the same 0x0FFF
    clamp, and -- like the lever -- bypasses the LFO fade (IC25
    0x1552-0x158E). The per-partial gate mirrors the lever gate, which is
    what make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
    [midi_serial.cpp, picoface_main.cpp]
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2026-08-17 Enter the bootloader from the panel, not from a paperclip
    Ten firmware images share one board, which makes choosing a different
    instrument a thing the user does rather than a thing a factory does once. Until
    now that meant reaching the module's BOOTSEL button: fine on a breadboard,
    awkward once this is a Eurorack module with a front panel in the way.
    The SDK can do it from software -- reset_usb_boot() jumps straight into the UF2
    bootloader -- so no second button and no panel hole are needed. The gesture is
    all three encoder buttons together, held for two and a half seconds, with the
    core taking the screen after half a second so nothing happens invisibly and
    letting go cancels. It lives in t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
    [picoface_main.cpp]
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2026-08-19 Lay out the front board, where the panel has already decided everything
    The main board layout was a series of choices. This one is mostly arithmetic:
    the panel fixes where the three encoder shafts, the two buttons and the display
    go, and the layout is what falls out. Board origin is panel (2.9, 14), so
    SELECT lands at (22.5, 46.58), PARAM A and B at (10.0, 71.61) and (35.0, 71.61),
    RUN and BOOT at (7.1, 46.58) and (37.9, 46.58). 229 track segments, 691 mm of
    copper, 20 vias, ground poured both sides, DRC clean and in agreement with the
    schematic.
    What was actually decided:
    J3 and J4 sit on the back at exactly the coordinates J1 and J2 occupy on the
    main board. That works because both board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
    [FrontBoard.kicad_pcb, FrontBoard.kicad_sch, MainBoard.kicad_pcb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]
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2026-08-19 The display's pin 1 is VDD, not GND
    Measured on the part now in hand: 1 VDD, 2 GND, 3 SCK, 4 SDA, numbered from the
    display side with pin 1 on the left. The symbol had the order most modules use
    -- GND, VCC, SCL, SDA -- so the board as drawn would have put 3.3 V on the
    module's ground pin and ground on its supply. The display would not have
    survived first power-up. The README has been warning about exactly this since
    the schematic was drawn ("some vendors swap the first two"); it turns out this
    vendor is one of them.
    The fix is two pins swapped in the symbol and the two power symbols exchanged in
    the sheet, which changes the netlist, so the front board is re-routed: 230
    segments, 19 vias, s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
    [FrontBoard.kicad_pcb, MainBoard.kicad_pcb, front_board.kicad_sch]
2026-08-19 Measure the last thing that was still assumed
    The display's four M2 holes: 30.4 x 28.5 mm apart, 2.5 mm in from the module's
    top-left corner, off the part itself. The layout had them at 30 x 28 -- carried
    over from the first draft of this document and never checked -- so they were
    0.4 and 0.5 mm out. Small enough to look right and big enough that an M2 screw
    would not go in.
    The numbers also confirm the module: 2.5 + 30.4 + 2.5 is 35.4 and
    2.5 + 28.5 + 2.5 is 33.5, exactly the outline this document has been carrying
    since before anyone had the part.
    Front board re-routed around the moved holes, 230 segments and 19 vias, no
    failures, DRC clean. The drill file now carries the four holes at 3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
    [FrontBoard.kicad_pcb]
2026-08-19 Read the Gerbers back the way a fab would
    Rendered both packages with gerbonara and looked at all four sides. Three
    things were wrong on the silkscreen and one file would not open at all.
    The Pico's A1 designator sat 1 mm above the top edge -- the fab trims it,
    so the largest part on the board would have shipped without a marking.
    TP1 and A2 sat on pads; --subtract-soldermask cuts silk out over mask
    openings, so both would have come out chewed. On the front board the
    display outline ran 0.12 mm alongside the DS1 box.
    The axial parts now carry their designator centred on their own body.
    That was the second attempt: moving the labels into the gaps cleared DRC
    but put "R2" against D2's body,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
    [FrontBoard.kicad_pcb, MainBoard.kicad_pcb]
2026-08-19 Put the parts back into the 3D view
    Both boards opened to an empty 3D view: the footprints were placed by
    script and their (model ...) lines never came along. Every footprint
    points at its library model again.
    Three things needed more than that. KiCad ships 3D models for 105 of its
    155 footprint libraries and Rotary_Encoder is not one of them, so the
    three parts that fill the 6.5 mm between the front board and the panel
    were invisible -- a 3D view without them answers nothing. They and the
    display now have stand-ins under hardware/3dmodels/, written from the
    footprints' own outlines and labelled in the files as what they are:
    envelopes for clearance, not datasheet models. And A1 was showing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
    [FrontBoard.kicad_pcb, MainBoard.kicad_pcb]
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2026-08-19 Give BOOT a spring pin so the module stays a plug-in part
    BOOT was the only signal on either board that did not end on a connector
    pin: it stopped at TP1, a solder pad, and a hand-soldered wire finished
    the job at the module's underside. That works, but the sockets are in the
    BOM specifically to keep the module replaceable, and a wire tethers it.
    TP2 is a landing pad at 26.51 / 7.58, under the module's BOOT pad, for a
    spring-loaded pin spanning 11.04 mm -- socket body 8.5 plus header plastic
    2.54, both read out of their own STEP models. Seating the module makes the
    contact. TP1 stays, out at the edge where an iron reaches, because two
    things about that position are unsettled: the coordinate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
    [MainBoard.kicad_pcb, main_board.kicad_sch]
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2026-08-19 The boards are drawn for a Pico 2, not for what I had written
    Michael's correction: the target is a plain Raspberry Pi Pico 2, the
    module most of the instruments here run on, and the Waveshare RP2350-Plus
    is what goes in when 16 MB of flash is wanted. "WeAct" was my own
    invention -- the top-level README has said Waveshare all along.
    That flips the standing caveat on the spring pin. TP2's position comes
    from the Pico 2 datasheet, so it is the drawn-for part's own document
    rather than a number borrowed from a different board. Only the side of the
    centreline was ever unsettled, because a drawing does not say which face
    it is viewed from, and that is now checked on the part: nearer the GP0
    row,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
    [FrontBoard.kicad_sch, main_board.kicad_sch]
2026-08-19 TP6 is at (8, 38), not where I had it
    Michael's photo said the test point looked wrong, and it was: 7.7 mm
    wrong. The pad moves from 26.51 / 7.58 to 25.00 / 15.13.
    Both coordinate sets I had been given were second-hand and neither
    matched. Figure 5 of the Pico 2 datasheet settles it -- the SMT footprint,
    test-point centres in a frame whose origin is the board's bottom-left
    corner, USB shell pads at x 7.775 and 13.225 fixing the centreline at
    10.5. The frame checks out independently: it puts pin 1's centre 1.37 mm
    from the top edge, exactly what KiCad's Pico footprint uses.
    The drawing gives seven test points and labels none of them, so which one
    is TP6 had to be reasoned out. Three sit at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
    [MainBoard.kicad_pcb]
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2026-08-20 Put the jack labels above the jacks, not below
    Drawing them below looked right on the render and would have been wrong on
    the rack: a patch cable hangs down out of a Eurorack jack and covers what is
    printed under it, so MIDI IN / MIDI OUT / L / R would have been legible only
    while nothing was plugged in.
    Moved to y 102, which puts them above the 11 mm nut with 1.5 mm to spare and
    8 mm clear of the PARAM knobs, and makes every label on the panel sit above
    what it names. SELECT gains half a millimetre to its 15 mm knob while I am
    in here.
    Checked rather than eyeballed: no silkscreen stroke within 0.3 mm of an
    opening or the edge, and none under a knob or a nut.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
    [Panel.kicad_pcb]
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2026-08-20 Configure the two MIDI pads for the DIN circuit
    hardware/README.md has asked for both of these by name since the schematic
    was drawn; the firmware never caught up. gpio_set_function does not touch
    the pad controls -- it says so in the SDK -- so neither happened by itself.
    RX: every RP2350 GPIO comes out of reset with its internal pull-down enabled
    (PADS_BANK0 reset 0x116, PDE=1). On this pin that divides the 4k7 pull-up
    the H11L1's open collector and the bus MIDI RX share through the Schottky.
    TX: the pads come up at 4 mA nominal drive (DRIVE_RESET = DRIVE_VALUE_4MA)
    and the 33R/33R output pair puts about 4.1 mA worst case through the pin, so
    the default is at or under the loop current. VO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
    [midi_serial.cpp]
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2026-08-31 Flash timing: one macro for all four writers, and slower values to test with
    Issue #107 reports that no instrument starts on third-party 16 MB RP2350
    boards while official Pico 2 boards work, and suspects the A4 stepping. The
    decisive fact is in the report: dropping clk_sys to 300 MHz made them boot.
    M0_TIMING encodes a divider of clk_sys, so that test lowered the flash clock
    from 148 to 100 MHz along with the core -- core and flash have moved together
    in every test so far, and nothing yet separates them.
    Worked out what the flash actually gets. RXDELAY counts half clk_sys cycles
    and 0 samples on the launching SCK edge, so the budget for clock-to-Q plus pad
    round trip is (half an SCK period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
    [pico_hw.cpp, project_config.h]
2026-08-31 Splash: show the chip stepping and the flash clock actually in force
    Issue #107 arrived as "not compatible with RP2350 A4?" and neither half of
    that question could be answered from the device. picotool does not report the
    stepping, so identifying the silicon means reading the part number off the
    package with a loupe. And the flash clock is worse than unknown: it is a
    compile-time choice with a runtime fallback, because pico_init() calls
    set_sys_clock_hz(..., false) and keeps the slack timing if the target turns
    out to be unreachable. Nothing announced which of the two had happened.
    Both now sit under the version on the splash, in a 5x7 line: "A4 148MHz".
    The stepping comes from rp2350_chip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
    [picoface_main.cpp]
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2026-09-01 A dead display should cost the display, not the instrument
    Michael asked whether a wrong audio board or a miswired I2C display could look
    like "the firmware does not boot", which is what two open issues report. Checked
    both, and the answers differ.
    The audio board cannot. I2S has no return path -- the DAC acknowledges nothing
    -- and init_audio() runs after the splash, so a wrong or absent DAC gives a
    normal boot and silence.
    A missing display cannot either, and I had assumed otherwise until I read the
    SDK: i2c_write_blocking() checks tx_abrt_source and returns an error on a NACK,
    so an absent panel just leaves the screen dark.
    A miswired one absolutely can. The wait for TX_EMPTY in the sa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
    [pico_hw.cpp, project_config.h]
2026-09-01 Flash timing: the datasheet has the pad delays, so stop guessing at the budget
    Michael found the current RP2350 datasheet while chasing issues #107 and #122,
    and it closes one question and opens a better one.
    Closed: the A4 stepping. "This stepping has no hardware changes." A4 is
    CHIP_ID.REVISION 0x8 and differs from A3 in bootrom only, and the A2->A3
    hardware delta -- GPIO leakage, a QFN-60 NSMASK fix, USB and OTP mitigations,
    changed reset states for the clock registers -- touches nothing about flash.
    Of 28 errata, 13 still affect A4 and none concerns QMI or booting from flash.
    There was never anything to miss there.
    Opened: Table 1292 gives the pad delays, worst case over process, volta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
    [project_config.h]
2026-09-01 Flash timing: RX4 as the default, because CD4's margin costs 1.3 voices
    Measured on hardware after the previous change went in, on the D5 -- the most
    XIP-bound of the ten, because it reads its PCM from flash. The boot benchmark
    went from B51 at 148 MHz to B59 at 111 MHz. Four voices, so 10.0 % per voice
    against 12.0 %: about 1.3 voices of headroom before the governor starts
    trimming tails.
    That is a real price, and it was paid for margin nobody has yet shown we need.
    Neither reporter of a non-booting board has tested anything, so we do not know
    whether their boards fail because the sample point is too early -- which RX4
    fixes for free -- or because 148 MHz is simply too fast for their flash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
    [project_config.h]
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2026-09-01 Withdraw the RXDELAY throughput claim: it was noise in a maximum
    A second OC run came back at B53 where the first had read B51, and that takes
    the finding away.
    The claim was that RXDELAY costs about five percent of throughput at constant
    SCK -- which would have been something the datasheet does not carry, since it
    describes RXDELAY only as a delay on the input sampling register. It rested on
    one OC run (B51) against one RX4 run (B53-54). With OC also reading 53 the two
    overlap and nothing separates them.
    The instrument is the problem, and it is worth knowing what it does:
    bootBenchPercent() reports the WORST of 94 blocks, not the mean. A maximum
    picks up whatever transient landed in one o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
    [project_config.h]
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2026-09-01 Flash: measure the timing at boot instead of prescribing it
    Two changes, both about the same thing: the right flash timing is a property
    of the board, and the boards are not ours.
    RX4 becomes the default. Same 148 MHz as OC and its benchmark numbers sit
    inside OC's own spread, so nothing measured separates them on cost -- but the
    sample point moves from 11 % into the window where the bit is valid to 28 %.
    RX4 was briefly the default already and was reverted on a measurement that
    RXDELAY costs throughput; that measurement was withdrawn one PR later and the
    default never followed the retraction.
    And the ladder is now walked at boot rather than handed out by e-mail.
    Checksum 32 KB of flash at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
    [pico_hw.cpp, project_config.h]
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2026-09-01 Flash: no upward ladder on a board the bootrom left in dual
    The ladder's premise was one sentence in the code: a too-fast timing corrupts
    data, so the checksum mismatches and the next rung gets a turn. Written as if
    established; it is not. A 16 MB A4-marked board settled it with two 444 MHz
    images differing only in their FIRST rung: RX4 first (148 MHz) does not boot,
    SAFE first (56 MHz) boots. The same board verifies RX4 at a 420 MHz core
    (140 MHz flash), so it is good to 140 and dead at 148 -- and the ladder never
    got to step down. Applying the fast rung is not a failed read; it takes the
    chip down, most likely by leaving the part's continuous-read mode bits in a
    state the controller did no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
    [pico_hw.cpp]
2026-09-01 Board variant: Waveshare RP2350B-Plus-W (I2S on GP40/41/42)
    An RP2350B in Pico format. Its 40-pin header carries GP40/41/42 where a
    Pico has GP26/27/28 (pins 31/32/34), so the RP2350B's ADC0-2 keep the Pico's
    ADC positions; GP26-28 exist only on the pads underneath. A Pico-Audio HAT on
    this board is therefore wired to GP40/41/42, and a firmware driving GP26-28
    plays into thin air -- display, MIDI and encoders sit where a Pico has them,
    so everything else works and only the sound is missing. Found on hardware
    with a pin probe: the chip was toggling BCK/LRCK on 27/28 all along.
    PICOFACE_BOARD=rp2350b_plus_w selects a board header with PICO_RP2350A=0
    (48 GPIOs, which is what compiles the PIO G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
    [waveshare_rp2350b_plus_w.h]
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

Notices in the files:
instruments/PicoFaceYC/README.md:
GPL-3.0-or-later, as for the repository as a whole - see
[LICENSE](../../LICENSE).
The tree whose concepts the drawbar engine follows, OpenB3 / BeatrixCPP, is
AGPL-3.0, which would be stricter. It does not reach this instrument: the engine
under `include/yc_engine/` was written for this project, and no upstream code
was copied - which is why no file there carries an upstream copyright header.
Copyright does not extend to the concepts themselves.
